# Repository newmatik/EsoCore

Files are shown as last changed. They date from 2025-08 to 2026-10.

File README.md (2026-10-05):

# EsoCore



EsoCore (Edge Sensor Observation, Control, Operations, Reliability Engine) is an open-source industrial IoT platform
for monitoring factory machinery and equipment. It spans the full stack from PCB hardware and embedded firmware to a
Django REST API backend and a Nuxt.js user portal.

## Repository Structure

```text
esocore/
  server/       Django REST API backend
  portal/       Nuxt.js user portal (dashboard, devices, alerts)
  website/      Public documentation site (static Nuxt.js, GitHub Pages)
  firmware/     Embedded C firmware for Edge (STM32H7) and sensors (STM32G0)
  hardware/     PCB designs (Altium), BOMs, Gerber, STEP, schematics
  tools/        Utility scripts (BOM sync, STEP linter)
  assets/       Shared icons and images
```

## Tech Stack

| Layer | Technology |
|---|---|
| Backend | Python 3.11+, Django 5, Django REST Framework, Poetry |
| Portal | TypeScript, Nuxt 4 (Vue 3), Nuxt UI, Tailwind CSS 4, Pinia |
| Website | TypeScript, Nuxt 4 (Vue 3), static generation, GitHub Pages |
| Firmware | C (C11), STM32H7 / STM32G0, ARM GCC, GNU Make |
| Hardware | Altium Designer, 4-layer FR4 PCBs |

## Prerequisites

- **Python 3.11+** and [Poetry](https://python-poetry.org/) for the server
- **Node 22.19+ (or 24.11+)** and [pnpm 9+](https://pnpm.io/) for the portal and website
- **ARM GCC** (`arm-none-eabi-gcc`) and **GNU Make** for the firmware

## Getting Started

### Server (Django REST API)

```bash
cd server
poetry install
poetry run python manage.py migrate
poetry run python manage.py createsuperuser
poetry run python manage.py runserver
```

The API is served at `http://localhost:8000/api/` with Swagger docs at `http://localhost:8000/api/docs/`.

See `server/README.md` for full setup, authentication, and deployment details.

### Portal (Nuxt.js)

```bash
cd portal
pnpm install
pnpm run dev
```

The portal runs at `http://localhost:3000`.

See `portal/README.md` for configuration and branding details.

### Website (Documentation)

```bash
cd website
pnpm install
pnpm run dev
```

To generate the static site for production:

```bash
pnpm run generate
```

See `website/README.md` for deployment instructions.

### Firmware

```bash
cd firmware
make all          # Build Edge + all sensors
make edge         # Build Edge only
make vibration    # Build a single sensor target
make help         # List all available targets
```

Requires the ARM GCC toolchain. See `firmware/README.md` for architecture and protocol details.

## Hardware

PCB designs, schematics, and BOMs are organized under `hardware/`:

- `hardware/edge/` -- Edge device (STM32H747, dual Ethernet, RS-485, WiFi, IEPE inputs, safety I/O)
- `hardware/sensors/` -- RS-485 sensor modules
  - vibration, acoustic, current, air quality, light, oil quality, pressure, temperature spot, proximity position
- `hardware/cables/` -- Cable assemblies

CAD files are in each device's `altium/` folder (open the `.PcbDoc` projects with Altium Designer).
See `hardware/README.md` and individual sensor READMEs for specifications.

### BOM Management

Canonical BOM CSVs live in each device folder under `hardware/`. The website reads CSVs from
`website/public/bom/` for public rendering. After editing any BOM in `hardware/`, run:

```bash
python3 tools/sync_bom_data.py
```

## Protocols

The Edge device supports industrial fieldbus protocols:

- Modbus RTU (RS-485, isolated) and Modbus TCP (Ethernet)
- PROFIBUS DP (DB-9, switchable termination)
- PROFINET Device (over Ethernet)

## Documentation

- [Hardware: Edge](website/content/esocore-edge.md) -- Core device specifications and connectivity
- [Hardware: Sensors](website/content/esocore-sensors.md) -- Sensor module catalog and applications
- [Installation Guide](website/content/getting-started/installation-guide.md) -- Full setup walkthrough
- Full docs are published at [www.esocore.com](https://www.esocore.com)

## Open Source

Source code: [github.com/newmatik/esocore](https://github.com/newmatik/esocore)

## Legal

Copyright 2026 Newmatik. All rights reserved.
Licensed under the Apache License, Version 2.0. See `website/content/license.md` for details.

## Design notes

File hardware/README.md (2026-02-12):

# EsoCore Hardware

## General Layout Requirements

- Prefer SMD components; avoid THT where feasible
- Provide Tag-Connect pads for MCU programming
- Include three fiducials on each SMD-assembled side
- Avoid single-sourcing; specify at least two MPNs where practical (exceptions: MCU or unique sensors)
- Evaluate cost-effective alternatives on LCSC, including reputable Chinese brands, not only established manufacturers

## Hardware sources

See READMEs in subfolders.

- `edge/`
- `sensors/`
  - `vibration sensor/`
  - `acoustic sensor/`
  - `current sensor/`
  - `air quality sensor/`
  - `light sensor/`
  - `oil quality sensor/`
  - `pressure sensor/`
  - `temperature spot sensor/`
  - `proximity position sensor/`
- `cables/`

Notes:

- BOMs live in the respective device folders.
- CAD/binaries belong under `altium/` and `mechanical/`.

## Copyright and License

Copyright © 2026 Newmatik. All rights reserved. Licensed under the Apache License, Version 2.0. See `website/content/license.md` for details.

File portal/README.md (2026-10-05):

# EsoCore Portal

Modern Vue.js frontend application for the EsoCore IoT monitoring system, built with Nuxt.js.

## Features

- **Dashboard**: Device monitoring overview with telemetry stats and recent alerts
- **Device Management**: Device listing with filtering, detail views with telemetry history
- **Asset Tracking**: Equipment grid with status filtering
- **Alert Management**: Alerts with severity filtering, acknowledgment, and resolution
- **Authentication**: Token-based authentication with cookie persistence
- **Dark Mode**: Forced dark theme with toggle support
- **Branding**: Configurable brand and product names via environment variables

## Technology Stack

- **Framework**: Nuxt 4 (Vue 3)
- **UI Library**: Nuxt UI (Tailwind CSS 4)
- **State Management**: Pinia
- **HTTP Client**: Nuxt `$fetch` (ofetch) with custom `useApi` composable
- **Authentication**: DRF Token authentication with cookie persistence
- **Icons**: Lucide (via Iconify)

## Quick Start

### Prerequisites

- Node.js 22.19+ (or 24.11+)
- pnpm 9+

### Installation

1. **Navigate to portal directory:**

   ```bash
   cd portal
   ```

2. **Install dependencies:**

   ```bash
   pnpm install
   ```

3. **Start development server:**

   ```bash
   pnpm run dev
   ```

The application will be available at `http://localhost:3000`

### Production Build

```bash
# Build for production
pnpm run build

# Preview production build
pnpm run preview

# Generate static site
pnpm run generate
```

## Configuration

### Environment Variables

Create a `.env` file in the portal directory:

```bash
# API Configuration
NUXT_PUBLIC_API_BASE_URL=http://localhost:8000/api
NUXT_PUBLIC_WS_BASE_URL=ws://localhost:8000/ws

# Authentication
NUXT_PUBLIC_AUTH_REDIRECT_URL=/dashboard

# App Configuration
NUXT_PUBLIC_APP_NAME=EsoCore
NUXT_PUBLIC_APP_VERSION=1.0.0

# Branding (optional)
# Set your brand and product names for UI titles and headers
# Example: Brand: Newmatik, Product: EsoCore => "EsoCore Portal"
NUXT_PUBLIC_BRAND=Newmatik
NUXT_PUBLIC_PRODUCT=EsoCore
```

### Branding

You can customize the displayed product name without code changes:

1. Set environment variables in your `.env` (or deployment env):

   ```bash
   NUXT_PUBLIC_BRAND=Newmatik
   NUXT_PUBLIC_PRODUCT=EsoCore
   ```

2. The UI will render headers and titles like: `EsoCore Portal`.

Defaults are defined in `app/config/branding.ts` and can be overridden at runtime via env vars.

## Project Structure

```text
portal/
├── app/
│   ├── app.vue                       # Root component
│   ├── assets/css/main.css           # Global CSS
│   ├── components/
│   │   └── ThemeToggle.vue           # Dark/light mode toggle
│   ├── composables/
│   │   ├── useApi.ts                 # API client ($fetch wrapper with auth)
│   │   └── useBranding.ts            # Brand/product name composable
│   ├── config/
│   │   └── branding.ts               # Branding defaults
│   ├── layouts/
│   │   ├── authenticated.vue         # Layout for authenticated pages
│   │   └── default.vue               # Default layout
│   ├── middleware/
│   │   └── auth.ts                   # Authentication route guard
│   ├── pages/
│   │   ├── index.vue                 # Landing page
│   │   ├── login.vue                 # Login page
│   │   ├── dashboard.vue             # Dashboard with stats and recent alerts
│   │   ├── alerts/index.vue          # Alert list with filtering and actions
│   │   ├── assets/index.vue          # Asset grid with status filtering
│   │   └── devices/
│   │       ├── index.vue             # Device list with site filtering
│   │       └── [id].vue              # Device detail with telemetry and events
│   ├── plugins/
│   │   ├── auth.client.ts            # Auth token restoration on startup
│   │   └── force-dark.client.ts      # Force dark mode on load
│   └── stores/
│       └── auth.ts                   # Auth state (token, user, login/logout)
├── public/                           # Static assets (icons, robots.txt)
├── app.config.ts                     # App-level configuration
├── eslint.config.js                  # ESLint configuration
├── nuxt.config.ts                    # Nuxt configuration
├── package.json                      # Dependencies and scripts
├── pnpm-lock.yaml                    # Lockfile
└── tsconfig.json                     # TypeScript configuration
```

## API Integration

The portal communicates with the Django REST backend through the `useApi` composable, which wraps
Nuxt's `$fetch` with automatic base URL resolution, auth token injection, and 401 redirect handling.

### Authentication

```typescript
const authStore = useAuthStore()
await authStore.login(email, password)

// Authenticated API calls
const api = useApi()
const devices = await api.get('/devices/devices/')
```

### API Endpoints Used

- **Auth**: `/auth/login/`, `/auth/logout/`, `/auth/me/`
- **Dashboard**: `/dashboard/summary/`
- **Devices**: `/devices/devices/`, `/devices/sites/`
- **Telemetry**: `/telemetry/points/`
- **Events**: `/events/events/`
- **Assets**: `/assets/assets/`

## Development

### Code Style

```bash
# Lint code
pnpm run lint

# Auto-fix lint issues
pnpm run lint:fix

# Format code
pnpm run format

# Check formatting
pnpm run format:check

# Type check
pnpm run typecheck
```

## Deployment

### Docker

```dockerfile
FROM node:22-alpine
WORKDIR /app
ENV NODE_ENV=production
# Use pnpm via Corepack (bundled with Node 22)
RUN corepack enable
COPY package.json pnpm-lock.yaml ./
RUN pnpm install --frozen-lockfile
COPY . .
RUN pnpm run build
EXPOSE 3000
CMD ["node", ".output/server/index.mjs"]
```

## Contributing

1. Follow Vue.js and Nuxt.js best practices
2. Use TypeScript for type safety
3. Follow the established component structure
4. Use meaningful commit messages

## License

Copyright 2026 Newmatik. All rights reserved.
Licensed under the Apache License, Version 2.0. See `website/content/license.md` for details.

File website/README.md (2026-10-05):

# EsoCore Website

This is the official website for EsoCore - an open-source industrial IoT platform for comprehensive monitoring of factory machinery and equipment.

The website is built with [Nuxt.js](https://nuxt.com) and deployed as a static site to GitHub Pages at [www.esocore.com](https://www.esocore.com).

## Features

- **Homepage**: Product overview with animated typewriter effect and hero image
- **Documentation**: Complete technical documentation with search and navigation
- **Static Generation**: Pre-rendered for optimal performance and SEO
- **BOM Integration**: Dynamic Bill of Materials widgets for hardware components
- **Responsive Design**: Works on desktop and mobile devices

## Development

### Prerequisites

- Node.js 22.19+ or 24.11+ (CI uses Node 22)
- pnpm 8 or later

### Setup

Install dependencies:

```bash
pnpm install
```

### Development Server

Start the development server on `http://localhost:3000`:

```bash
pnpm dev
```

### Building for Production

Generate the static site:

```bash
pnpm generate
```

The static files will be generated in `.output/public/` and can be deployed to any static hosting service.

### Preview Production Build

Preview the generated static site locally:

```bash
pnpm preview
```

## Project Structure

```text
website/
├── components/         # Vue components (header, footer, etc.)
├── composables/        # Vue composables (useDocs, etc.)
├── content/            # Markdown documentation files
├── layouts/            # Nuxt.js layouts
├── pages/              # Nuxt.js pages and routing
├── public/             # Static assets (images, CSS, BOM data)
│   ├── bom/            # Synced BOM CSV files
│   └── docs/           # Documentation assets
├── server/             # Server routes and plugins
│   ├── api/            # API routes for serving documentation
│   └── plugins/        # Server plugins (trailing-slash redirect)
├── utils/              # Utility modules (docs-config, etc.)
└── nuxt.config.ts      # Nuxt.js configuration
```

## Documentation

Documentation content is stored as Markdown files in the `content/` directory and served dynamically through API routes. The documentation includes:

- Hardware specifications
- API documentation
- Development guides
- Business information

## BOM Data Synchronization

BOM (Bill of Materials) data is synchronized from the hardware designs using the `sync_bom_data.py` script in the `tools/` directory:

```bash
# From the project root
python3 tools/sync_bom_data.py
```

This copies CSV files from `hardware/` to `website/public/bom/` for use in the documentation.

## Deployment

The website is automatically deployed to GitHub Pages via GitHub Actions when changes are pushed to the `main` branch. The workflow:

1. Sets up Node.js and pnpm
2. Installs dependencies
3. Generates the static site
4. Deploys to GitHub Pages

## Contributing

1. Make changes to the appropriate files
2. Test locally with `pnpm dev`
3. Generate and test the static build with `pnpm generate && pnpm preview`
4. Commit and push to trigger automatic deployment

For documentation updates, edit the Markdown files in `content/` and they will be automatically included in the next build.

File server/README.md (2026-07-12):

# EsoCore Server

Django REST Framework backend for the EsoCore IoT monitoring system.

**Status: In Development** -- Core REST API endpoints for device authentication, telemetry ingestion, and
configuration are implemented. MQTT real-time messaging and advanced analytics features are planned.

## Features

- **Device Management**: Register and manage IoT devices with API key authentication
- **Telemetry Ingestion**: High-performance time-series data collection
- **Asset Monitoring**: Track equipment cycles and maintenance schedules
- **Event Processing**: Real-time system events and alert management
- **User Management**: Role-based access control and customizable dashboards
- **RESTful API**: Complete REST API with OpenAPI/Swagger documentation

## Technology Stack

- **Framework**: Django 5.2 with Django REST Framework 3.16
- **Database**: SQLite (development) / PostgreSQL (production)
- **Authentication**: API Key authentication with session support
- **API Documentation**: DRF Spectacular (OpenAPI/Swagger)
- **Deployment**: Gunicorn / ASGI-compatible

## Quick Start

### Prerequisites

- Python 3.11+
- Poetry (recommended for Python dependencies)
- pnpm (for code quality scripts)

### Installation (Poetry)

1. **Navigate to server directory:**

   ```bash
   cd server
   ```

2. **Install dependencies with Poetry:**

   ```bash
   poetry install
   ```

3. **Activate the virtual environment (Poetry 2):**

   ```bash
   # Print the activation command, then evaluate it
   eval $(poetry env activate)
   # Or prefix all commands with: poetry run ...
   ```

4. **Run migrations:**

   ```bash
   poetry run python manage.py migrate
   ```

5. **Set up code quality tools (optional):**

   The project includes `package.json` with pnpm scripts for code quality tools. These are pre-configured and ready to use with the Poetry
   environment.

6. **Create superuser:**

   ```bash
   poetry run python manage.py createsuperuser
   ```

7. **Run development server:**

   ```bash
   poetry run python manage.py runserver
   ```

The API will be available at `http://localhost:8000/api/`

## API Endpoints

### Device-Facing Endpoints

- `POST /api/iot/v1/auth/handshake` - Authentication handshake
- `POST /api/iot/v1/telemetry/batch` - Telemetry data ingestion
- `GET /api/iot/v1/config` - Device configuration
- `GET /api/iot/v1/ota/check` - OTA update check
- `POST /api/iot/v1/ota/report` - OTA update status report

### Management Endpoints

- `/api/devices/devices/` - Device management
- `/api/devices/sites/` - Site management
- `/api/devices/firmware/` - Firmware bundle management
- `/api/assets/` - Asset management
- `/api/events/` - Event management
- `/api/telemetry/` - Telemetry data access
- `/api/users/` - User management
- `/api/auth/login/`, `/api/auth/logout/`, `/api/auth/me/` - User authentication
- `/api/dashboard/summary/` - Dashboard summary

## Authentication

### API Key Authentication (Devices)

Devices authenticate using API keys. Preferred header is `X-Auth-Key` (also accepts `X-API-Key` for compatibility):

```bash
curl -H "X-Device-Id: <uuid>" \
     -H "X-Auth-Key: <device-api-key>" \
     -H "Content-Type: application/json" \
     http://localhost:8000/api/iot/v1/telemetry/batch
```

### Session Authentication (Users)

Users authenticate via Django's session framework for web interface access.

## Configuration

### Environment Variables

The following environment variables can be set for production deployment. For local development the defaults
in `settings.py` are sufficient (SQLite, DEBUG=True).

> **Note:** The `.env` file is **not** auto-loaded by the Django settings. Set these as real environment
> variables, or add `python-dotenv` loading to `settings.py` if you prefer `.env` files.

```bash
DEBUG=True
SECRET_KEY=your-secret-key-here
ALLOWED_HOSTS=localhost,127.0.0.1
CORS_ALLOWED_ORIGINS=http://localhost:3000,http://127.0.0.1:3000
BRAND_NAME=Newmatik
PRODUCT_NAME=EsoCore
```

### Branding (Admin Title)

Admin branding is configured in `esocore_api/branding.py`.

Defaults:

```python
BRAND_NAME = "Newmatik"
PRODUCT_NAME = "EsoCore"
# Admin title becomes: "EsoCore Server"
```

Override via environment variables (no code change needed):

```bash
export BRAND_NAME="Acme"
export PRODUCT_NAME="Edge"
# Optional: override final admin title directly
export ADMIN_TITLE="Acme Edge Server"

poetry run python manage.py runserver
```

The title is used in Unfold's `SITE_TITLE` and the Django admin header/title.

### Database Configuration

For production, use PostgreSQL:

```python
DATABASES = {
    'default': {
        'ENGINE': 'django.db.backends.postgresql',
        'NAME': 'EsoCore',
        'USER': 'your_user',
        'PASSWORD': 'your_password',
        'HOST': 'localhost',
        'PORT': '5432',
    }
}
```

## Development

### Running Tests

```bash
poetry run python manage.py test
```

### Code Quality Tools

This project uses modern Python code quality tools:

- **Ruff**: Fast Python linter (replaces flake8)
- **Black**: Code formatter
- **isort**: Import organizer

#### Running Code Quality Checks

```bash
# Quick linting (recommended)
pnpm run lint

# Auto-format code
pnpm run format

# Individual tools
pnpm run ruff          # Lint with Ruff
pnpm run black         # Format with Black
pnpm run isort         # Organize imports
```

#### Check Only (No Auto-Fix)

```bash
# Check without fixing
pnpm run lint:check

# Individual checks
pnpm run ruff:check    # Check Ruff rules
pnpm run black:check   # Check Black formatting
pnpm run isort:check   # Check import organization
```

#### Auto-Fix Issues

```bash
# Fix all auto-fixable issues
pnpm run format:fix

# Individual fixes
pnpm run ruff:fix      # Fix Ruff issues
pnpm run black         # Format with Black
pnpm run isort         # Organize imports
```

### API Documentation

Access Swagger UI at: `http://localhost:8000/api/docs/`

## Deployment

### Production Settings

- Set `DEBUG=False`
- Use PostgreSQL database
- Configure proper CORS origins
- Set up proper logging
- Use environment variables for secrets

## Project Structure

```text
server/
├── esocore_api/          # Main Django project (active; used by manage.py, wsgi, asgi)
│   ├── settings.py
│   ├── urls.py
│   └── wsgi.py
├── devices/                   # Device management app (devices, sites, firmware)
├── iot/                       # IoT device-facing endpoints (auth, telemetry, config, OTA)
├── assets/                    # Asset management app
├── telemetry/                 # Telemetry data app
├── events/                    # Event processing app
├── users/                     # User management app
├── manage.py
├── pyproject.toml
├── poetry.lock (generated)
└── README.md
```

## Contributing

1. Follow Django coding standards
2. Write tests for new features
3. Update API documentation
4. Use meaningful commit messages

## License

Copyright © 2026 Newmatik. All rights reserved. Licensed under the Apache License, Version 2.0. See `website/content/license.md` for details.

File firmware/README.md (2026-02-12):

# EsoCore Firmware

## Industrial IoT Edge Computing Platform

**EsoCore** is a comprehensive firmware platform for industrial IoT applications, featuring real-time edge intelligence, robust communication
protocols, and enterprise-grade reliability.

## Architecture

```text
                          Data Acquisition
                   ┌──────────┬────────────────────┐
                   │          │                    │
              RS-485 Bus   4x Analog          6x Safety DI
              (Sensor       (Dual-mode          (Dual-channel
               Modules)      IEPE/DC)            optocoupled)
                   │          │                    │
                   └──────┬───┴────────────────────┘
                          │
                   EsoCore Edge Device (STM32H747)
                          │
          ┌───────────────┼───────────────┐
          │               │               │
     Dual Ethernet    WiFi/HTTP      Fieldbus
     Port A  Port B    API           RS-485
     (OT)   (IT)                     Modbus RTU
                                     PROFIBUS
     Internal Services:              Interbus
     ├── TinyML Engine
     ├── Safety I/O (6 dual-channel inputs + relay + SSR)
     ├── Power Management (24V DC + supercap)
     ├── Storage System (microSD)
     └── Configuration Management
```

### Data Acquisition Paths

EsoCore supports three complementary data acquisition methods:

- **RS-485 Sensor Bus**: Distributed sensor modules with local MCUs connect over an industrial RS-485 multi-drop bus. Each module performs its own
  conditioning and preprocessing. Supports auto-discovery and hot-plug. Best for: diverse sensor types, long cable runs (up to 100 m), scalable
  multi-sensor deployments.
- **Dual-Mode Analog Inputs (4 channels)**: On-board signal chain with per-channel mode selection via TMUX1101 analog switch. In IEPE mode:
  constant-current source enabled, AC-coupled for vibration accelerometers. In DC mode: current source off, direct bypass for 0-10 V, 4-20 mA,
  or other analog sensors. Both modes share 24-bit simultaneous ADC (ADS1274) at 50 kSPS, PGA (PGA280), and 15 kHz anti-aliasing filter. Best
  for: high-fidelity vibration monitoring or general-purpose analog sensing directly wired to the Edge device.
- **Safety Digital Inputs (6 channels)**: Dual-channel optocoupled 24V inputs with cross-monitoring (EN ISO 13849 Cat. 3). Each channel uses
  two independent optocouplers; firmware verifies agreement between both channels. Response time <10 ms. Best for: safety devices (e-stops,
  light curtains, safety edges, door sensors) as well as general machine state monitoring, production counting, and PLC integration.

## Key Features

- **Edge Intelligence**: TinyML with anomaly detection and predictive maintenance
- **Industrial Communication**: Dual Ethernet, RS-485, Modbus RTU/TCP, PROFINET, PROFIBUS, Interbus, WiFi, HTTP/HTTPS
- **Data Acquisition**: RS-485 sensor bus + 4 dual-mode analog inputs (IEPE/DC, 24-bit) + 6 safety digital inputs (dual-channel)
- **Safety I/O**: 6 dual-channel inputs (EN ISO 13849 Cat. 3) + safety relay (G7SA-2A2B-DC24) + SSR (AQY212EHAZ)
- **Power Resilience**: 24V DC with aggressive surge/ESD protection + supercapacitor backup
- **Enterprise Storage**: microSD with compression and power-safe writes
- **Remote Management**: OTA updates, configuration sync, health monitoring

## Quick Start

### Prerequisites

- ARM GCC toolchain (`arm-none-eabi-gcc`)
- GNU Make
- STM32H7 (Edge) and STM32G0 (Sensors) target support

### Build Commands

```bash
# Build everything (edge + all sensor modules)
make all

# Build specific components
make edge                   # Edge device
make vibration              # Vibration sensor
make acoustic               # Acoustic sensor
make current                # Current sensor
make air_quality            # Air quality sensor
make oil_quality            # Oil quality sensor
make pressure               # Pressure sensor
make temperature            # Temperature sensor
make proximity              # Proximity sensor
make light                  # Light sensor

# Flash devices
make flash_edge
make flash_vibration
make flash_acoustic
make flash_current
make flash_air_quality

# List all available targets
make help
```

> **Note:** The STM32G0 HAL, CMSIS, startup, and linker files (`stm32/stm32g0/`) are not yet included in
> the repository. Sensor module builds will fail until this directory structure is added. See the Makefile
> for the expected layout.

## Project Structure

```text
firmware/
├── common/                # Shared components
│   ├── communication/     # WiFi, HTTP, RS-485, Modbus
│   ├── storage/           # Sensor interface, microSD
│   ├── safety/            # EN ISO 13849 safety I/O (dual-channel inputs + relay outputs)
│   ├── management/        # Power, configuration management
│   ├── intelligence/      # Event system, TinyML
│   └── ui/                # OLED display
├── stm32/
│   ├── edge/              # Edge device firmware
│   └── sensors/           # Sensor module firmware
├── build/                 # Generated build artifacts
├── release/               # Release packages
└── Makefile               # Build system
```

## RS-485 Sensor Bus Modules

External sensor modules connect via the RS-485 multi-drop bus. Each module has its own MCU and performs local conditioning:

| Sensor Type | Key Capabilities | Use Cases |
| --- | --- | --- |
| **Vibration** | 3-axis FFT, bearing fault detection | Predictive maintenance |
| **Acoustic** | SPL measurement, ultrasound detection | Noise monitoring, leak detection |
| **Current** | Harmonic analysis, motor load detection | Power quality, motor monitoring  |
| **Air Quality** | IAQ calculation, health risk assessment | Environmental monitoring |
| **Oil Quality** | Turbidity, viscosity, water content | Lubrication monitoring |
| **Pressure** | Multi-range sensing, hydraulic monitoring | Process control |
| **Temperature** | NTC/RTD/Thermocouple, high precision | Thermal management |
| **Proximity** | Inductive/capacitive/laser sensing | Position detection |
| **Light** | Ambient/UV/IR sensing, lux measurement | Light level monitoring |

## On-Board Inputs

In addition to the sensor bus, the Edge device has direct on-board inputs:

| Input Type | Channels | Specification | Use Cases |
| --- | --- | --- | --- |
| **Analog (IEPE/DC)** | 4 | 24-bit ADC, 50 kSPS, PGA, 15 kHz AAF, TMUX1101 | IEPE accelerometers, 0-10V, 4-20mA sensors |
| **Safety Digital** | 6 | Dual-channel optocoupled, 24V, EN ISO 13849 Cat. 3 | E-stops, safety edges, light curtains, machine states |

## Configuration

### Edge Device

```c
#define WIFI_SSID           "EsoCore_Network"
#define SERVER_URL          "https://api.esocore.com"
#define HEARTBEAT_INTERVAL_MS    30000
#define OTA_CHECK_INTERVAL_MS    3600000
```

### Sensor Modules

```c
#define SENSOR_DEVICE_ADDRESS   0x02
#define SENSOR_DEVICE_TYPE      ESOCORE_DEVICE_TYPE_VIBRATION
#define DATA_TRANSMIT_INTERVAL_MS 2000
```

## System Monitoring

### Health Monitoring

```c
esocore_config_status_t status;
esocore_config_get_status(&status);
uint8_t health = status.system_health; // 0-100
```

### Event Logging

```c
esocore_event_log(ESOCORE_EVENT_SENSOR_DATA_READY,
                 ESOCORE_EVENT_SEVERITY_INFO,
                 (uint8_t *)"Data processed", 0);
```

### Performance Metrics

- CPU usage monitoring
- Memory utilization tracking
- Network latency measurement
- Sensor data throughput
- Storage compression ratios
- Power consumption monitoring

## API Reference

### Server Endpoints (IoT API)

The Edge device communicates with the EsoCore server at `/api/iot/v1/`:

- `POST /api/iot/v1/auth/handshake` - Device authentication via API key
- `POST /api/iot/v1/telemetry/batch` - Submit telemetry data batches
- `GET  /api/iot/v1/config` - Fetch device configuration
- `GET  /api/iot/v1/ota/check` - Check for firmware updates
- `POST /api/iot/v1/ota/report` - Report OTA update result

### RS-485 Sensor Bus Protocol

- `DISCOVER` - Device discovery
- `HEARTBEAT` - Connection monitoring
- `DATA_REQUEST/RESPONSE` - Sensor data exchange
- `CONFIG_UPDATE` - Configuration updates

## Hardware Abstraction Layer (HAL) Status

The firmware uses a layered architecture where higher-level modules call into HAL functions that
interface with hardware peripherals. HAL functions are implemented as stubs (returning `true` or
`false` without real hardware interaction) until the corresponding hardware driver is integrated.
This is a standard pattern for embedded projects under active development.

Stub functions are marked with `/* TODO: ... */` comments. Current module completion status:

| Module | Implemented | Stubs | Complete |
| --- | --- | ----- | --- |
| `common/communication/ethernet_manager.c` | 9 | 0 | 100% |
| `common/safety/safety_io.c` | 25 | 3 | 89% |
| `common/ui/oled_display.c` | 42 | 8 | 84% |
| `common/storage/storage_system.c` | 18 | 12 | 60% |
| `common/intelligence/tinyml_engine.c` | 20 | 15 | 57% |
| `common/sensors/sensor_interface.c` | 20 | 15 | 57% |
| `common/communication/wifi_manager.c` | 12 | 13 | 48% |

To find all HAL stubs, search for `TODO` comments in the `common/` directory.

## License

Apache License 2.0

## Support

- Issues: [GitHub Issues](https://github.com/newmatik/esocore/issues)
- Docs: [esocore.com](https://www.esocore.com)

---

**EsoCore** - Industrial IoT with Edge Intelligence

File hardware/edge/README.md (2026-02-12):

# EsoCore Edge

## PCB Specification

- Board: 4-layer FR4 1.55 mm +/-10%
- Dimensions: 86 × 171 mm (H × W) – sized for custom DIN Rail housing
- Surface finish: ENIG
- Copper: 35 µm (1 OZ) outer/inner
- Black soldermask / white silkscreen

## Hardware

- MCU: STM32H747IIT6 (LQFP176) dual-core M7/M4, 25 MHz active oscillator (shared with Ethernet PHY), 32.768 kHz RTC
- MCU support: 1.2 V LDO (TLV70212DBVR) for internal regulator bypass; ferrite bead (BLM18PG121SN1D) on VDD rail
- Storage: microSD socket (push-push) with EMIF06-MSD02N16 EMI filter on SDIO lines, industrial microSD card
- Power: Dedicated 24 V DC input -> 5 V buck (TPS54331, 3 A) -> 3.3 V digital LDO + 3.3 V low-noise analog LDO (TPS7A4533)
- Backup: 3.8 V 20 F supercap (SLA3R8L2060813) with 680 ohm charge current limiting and Schottky diode (CDBA240LL-HF)
  charge path control for safe shutdown; evaluate adding second unit if 30 s runtime target requires more capacity
- Protection: TVS diodes + varistors on 24 V input; input LC filter (47 uH + 470 uF); ESD arrays on USB/GPIO/sensor bus
- Interfaces:
  - USB-C device/service with common-mode choke (DLW21SN900SQ2L) and ESD protection (USBULC6-2M6); firmware flashing
    and terminal communication only; not used for normal operation or data collection
  - Dual Ethernet 10/100 (2x KSZ8081RNACA) with integrated magnetics (2x Wurth 7499111121) and ferrite beads
    (FCM1608KF-601T03) per PHY; Port A (Machine), Port B (IT)
  - RS-485 sensor bus (SN65HVD72), termination selectable
  - Fieldbus: Isolated Modbus RTU, PROFIBUS-compatible RS-485 (DB-9), dedicated Interbus RS-485
- I/O connectors:
  - Pluggable terminal blocks (Degson): plugs `2EDGK-5.0-xxP` mating with PCB connectors `2EDGR-5.0-xxP`; all PCB mates are 90° angled at PCB edge for
    enclosure access
  - 2x 4-pin sensor bus: plug `2EDGK-5.0-04P` / PCB mate `2EDGR-5.0-04P`
  - Safety digital inputs: 14-pin `2EDGK-5.0-14P` / `2EDGR-5.0-14P` (6 dual-channel safety inputs, 12 optocouplers)
  - Safety relay output: 6-pin `2EDGK-5.0-06P` / `2EDGR-5.0-06P`
  - Analog inputs: 10-pin `2EDGK-5.0-10P` / `2EDGR-5.0-10P` (4 dual-mode IEPE/DC channels)
  - Fieldbus: 6-pin `2EDGK-5.0-06P` / `2EDGR-5.0-06P`; PROFIBUS: DB-9
  - Interbus: 4-pin `2EDGK-5.0-04P` / `2EDGR-5.0-04P`
  - Power input: 2-pin `2EDGK-5.0-02P` / `2EDGR-5.0-02P`
- Programming/debug:
  - STM32 SWD: Tag-Connect TC2050-IDC-NL (10-pin needle footprint)
  - ESP32 UART: Tag-Connect TC2030-IDC-NL (6-pin needle footprint)
- WiFi/BT: ESP32-S3-WROOM-1-N16R8 with USB VBUS LDO (AMS1117-3.3) and auto-programming circuit (UMH3N)
- Safety I/O: 6 dual-channel safety inputs (12x PC817X2NIP1B optocouplers, EN ISO 13849 Cat. 3) + safety relay
  (1x G7SA-2A2B-DC24, 2NO+2NC) with DRV110APWR coil driver for PLd interlocking
- UI: 1.5" 128x64 OLED (I2C) with BSS138LT1G level shifter, Reset/Boot/Menu buttons, status LEDs
- Analog: 4-ch IEPE signal chain (ADS1274 ADC, PGA280, OPA4188, REF200AU current sources)

## Mechanical Constraints

- **PCB dimensions**: 86 mm (H) × 171 mm (W) to fit in custom DIN Rail housing
- **Housing**: 90 mm height × 175 mm width (10 × 17.5 mm for DIN rail mounting)
- **Clearance**: 2 mm on all sides between PCB edge and housing walls
- **Dimension logic**:
  - Height: 90 mm housing − 2 mm (top) − 2 mm (bottom) = **86 mm PCB**
  - Width: Housing must be multiple of 17.5 mm; 10 × 17.5 = 175 mm housing − 2 mm (left) − 2 mm (right) = **171 mm PCB**
- **Note**: Height is fixed at 86 mm; width can be adjusted in 17.5 mm increments (with corresponding 4 mm reduction for PCB)
- **Edge access**:
  - **Top edge**: All pluggable terminal blocks (green Degson connectors)
  - **Bottom edge**: USB-C, 2x Ethernet RJ45, DB-9 (PROFIBUS)
  - **Left and right edges**: Keep clear (no connectors or tall components)

## General Layout Requirements

- Black solder mask with white silk screen
- Silk screen for important components with information value only (such as connectors)
- Prefer SMD components; avoid THT where feasible
- Single-sided assembly: place all SMD and THT on one side only (no backside assembly)
- Prefer increasing PCB width (if needed) over double-sided assembly to reduce cost and simplify enclosure
- Provide Tag-Connect pads: TC2050 footprint for STM32 SWD and TC2030 footprint for ESP32 UART
- Include three fiducials on the assembled side
- Avoid single-sourcing; specify at least two MPNs where practical (exceptions: MCU or unique sensors)
- Evaluate cost-effective alternatives on LCSC, including reputable Chinese brands, not only established manufacturers

## Layout Guidance

### Component Placement

- **Display and UI**: Place 1.5" OLED display and buttons (Reset/Boot/Menu) on front face for easy access
- **Buttons**: Position Reset/Boot/Menu buttons directly below the display with sufficient spacing for easy operation; ensure no obstructions above
  button areas
- **Connectors**:
  - Group all pluggable terminal blocks (Degson green connectors) along the top edge
  - Place USB-C, Ethernet RJ45, and DB-9 along the bottom edge
  - Keep left and right edges completely clear
- **Tall components**: Keep away from left and right edges to maintain housing clearance

### Electrical Layout

- Separate power, digital, and analog zones; star ground tie at ADC/MCU ref
- Keep RS‑485, Ethernet, and USB return paths tight; add stitching vias near chokes
- Place TVS/ESD close to connectors; keep supercap high-current paths short
- Respect creepage/clearance around isolated fieldbus and Interbus sections

## CAD Toolchain

- Tool: Altium Designer
- Project: `hardware/edge/Altium/PCB/EsoCore_Edge.PcbDoc`
- Schematics: `hardware/edge/Altium/Schematics/*.SchDoc` (14 sheets)
- Footprint library: `hardware/edge/Altium/Footprint library/EsoCore.PcbLib`
- Notes: Open the `.PcbDoc` in Altium Designer; edit schematics/layout in `.SchDoc`/`.PcbDoc`. Generate fabrication
  outputs via Altium Designer.

## Copyright and License

Copyright © 2026 Newmatik. All rights reserved. Licensed under the Apache License, Version 2.0. See `website/content/license.md` for details.

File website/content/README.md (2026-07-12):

# EsoCore: Universal Industrial Machine Monitoring System

EsoCore is an advanced industrial IoT platform for comprehensive monitoring of factory machinery and equipment. By capturing critical operational
data—from thermal conditions to mechanical health indicators—this system enables predictive maintenance, reduces downtime, and optimizes equipment
performance across manufacturing facilities.

EsoCore is an acronym: Edge Sensor Observation, Control, Operations, Reliability Engine. The name also recognizes our heritage—Newmatik began as ESO
Electronic Service Ottenbreit GmbH in 1990—carrying that tradition forward as we build everything new and automatic today.

---

## Introduction

### The Problem

Unplanned equipment failures cost manufacturers millions in lost production, emergency repairs, and quality issues. Traditional reactive maintenance
leads to premature replacements, unexpected downtime, and safety hazards. This is especially critical for high-volume production, precision
manufacturing, and safety-critical operations where equipment reliability is paramount.

### The Solution

A robust edge-to-cloud telemetry platform that continuously monitors machine health through multiple sensor streams, providing early warning of issues
and actionable insights for maintenance teams. The system is designed to work with virtually all industrial machinery types and integrates with
existing factory systems, making it universally deployable across diverse manufacturing environments.

### Development Model

EsoCore is developed and maintained by Newmatik through a collaborative partnership model with strategic industrial partners. The entire
platform—including hardware designs, firmware, and cloud components—is fully open source under the Apache 2.0 License,
ensuring maximum flexibility and preventing vendor lock-in. Partners can develop proprietary market-specific
customizations while benefiting from shared platform development costs and continuous innovation. This unique approach
combines open-source principles with commercial viability, creating a sustainable ecosystem where partners retain full
independence and can fork the project if needed.

### Competitive Position

EsoCore differentiates itself in the industrial IoT market through cross-domain capability (supporting both industrial doors and CNC machines in one
platform), edge-first TinyML architecture for ultra-low latency anomaly detection, and comprehensive safety integration. While competitors often focus
on single verticals with proprietary platforms, EsoCore's open-source foundation and unified approach provides unique value for facilities managing
diverse industrial assets.

### Key Benefits

- **Predictive Maintenance**: Detect issues before failure occurs using AI-powered edge intelligence
- **Edge Intelligence**: On-device anomaly detection with TinyML for faster response
- **Operational Insights**: Track usage patterns and energy efficiency with algorithmic analysis
- **Fleet Management**: Monitor multiple machines from a centralized dashboard with ML-driven analytics
- **Cost Reduction**: Optimize maintenance schedules and extend equipment life through intelligent predictions
- **Compliance**: Maintain audit trails for safety and regulatory requirements
- **Universal Compatibility**: Works with virtually all industrial machinery and manufacturing equipment
- **Complete Data Visibility**: Comprehensive monitoring for mission-critical production environments

---

## Target Applications

**Machining & Metal Working:**

- CNC milling machines, lathes, turning centers
- Stamping presses, punching machines, press brakes
- Grinding machines, surface finishing equipment
- Welding stations, cutting systems (plasma, laser, waterjet)

**Process Manufacturing:**

- Injection molding machines, extrusion equipment
- Packaging lines, filling and sealing machines
- Chemical reactors, mixing equipment
- Food processing machinery, bottling lines

**Material Handling & Automation:**

- Conveyor systems, robotic arms, pick-and-place units
- Automated guided vehicles (AGVs), shuttle systems
- Assembly line automation, testing equipment
- Warehouse automation (AS/RS, sorters)
- Sectional doors, overhead doors, door drives

**Support Infrastructure:**

- Industrial pumps, compressors, blowers
- Motors, gearboxes, belt drives, couplings
- HVAC systems, cooling towers, chillers
- Hydraulic and pneumatic systems

**Specialized Equipment:**

- Textile machinery (looms, knitting machines)
- Paper processing equipment (pulping, coating)
- Mining equipment (crushers, mills, separators)
- Energy equipment (turbines, generators)

For these demanding applications, EsoCore provides the complete operational visibility and zero-downtime reliability that traditional reactive
maintenance cannot deliver.

---

## Project goals

- **Capture**:
  - Comprehensive air quality monitoring (temperature, humidity, CO₂, VOCs, particulate matter)
  - Equipment environmental monitoring for thermal management and air quality
  - Light intensity monitoring (visible, UV, IR, color, spectral) for workplace safety and process control
  - Oil quality monitoring (viscosity, contamination, water content) for predictive lubrication maintenance
  - Pressure monitoring for hydraulic/pneumatic systems (leak detection, performance validation)
  - Targeted temperature monitoring (bearings, gearboxes, extreme environments)
  - Position sensing and cycle counting (automation, robotics, machine validation)
  - Operational cycles (machine starts/stops, production counts)
  - Multi-axis vibration (RMS and diagnostic windows) for bearing/mechanical health
  - Motor current and power consumption for load monitoring
  - Acoustics (audible + ultrasound monitoring) for tool wear, quality, and fault detection
  - Process parameters (pressure, flow, speed) via analog/digital interfaces
- **Local durability**: store on SD in a standardized, append-only, audit-friendly format with integrity checks.
- **Reliable sync**: upload to a cloud IoT platform via REST with strong auth, resumable uploads, and conflict-free idempotency.
- **Mixed connectivity**: Wi-Fi or dual Ethernet, with automatic backfill after outages.
- **Fleet-grade ops**: secure provisioning, OTA firmware, device health, alerts, dashboards, and role-based access.

---

## System Architecture

### High-Level Components

| Component | Technology | Purpose |
| --- | --- | --- |
| **Edge** | STM32H747 (dual-core M7/M4) | Real-time sensor data collection and local processing |
| **Cloud Platform** | Django REST Framework Server + Nuxt.js Portal | Data management, analytics, and user interfaces |
| **Connectivity** | Dual Ethernet or Wi-Fi | Reliable data transmission with offline resilience |
| **Storage** | Industrial microSD + Cloud DB | Local buffering and long-term data persistence |

### Technology Choices Rationale

- **STM32 MCU**: Proven ecosystem with robust peripherals, extensive RTOS support, and hardware crypto acceleration
- **Django REST Framework Server + Nuxt.js Portal**: Scalable backend with REST APIs, role-based access control, and modern responsive frontend with
  real-time dashboards
- **Industrial microSD**: Provides local resilience for 30+ days of offline operation
- **TLS over REST**: Simple, firewall-friendly protocol with strong security

### Data Acquisition Architecture

EsoCore supports three complementary data acquisition methods:

- **RS-485 Sensor Bus**: Distributed sensor modules with local MCUs connect over an industrial RS-485 multi-drop bus, enabling plug-and-play
  expansion. New sensor types can be added without changing the Edge or platform architecture. Digital, noise-immune wiring up to 100 m with
  auto-discovery and hot-plug support.
- **On-Board IEPE Analog Inputs (4 channels)**: Dedicated signal chain for IEPE/ICP vibration accelerometers wired directly to the Edge device.
  24-bit simultaneous ADC at 50 kSPS per channel with programmable gain and anti-aliasing filter.
- **On-Board Safety Digital Inputs (6 channels)**: Dual-channel optocoupled 24 V inputs (EN ISO 13849 Cat. 3) with cross-monitoring for safety
  devices (e-stops, light curtains, safety edges) and general-purpose signals (cycle counts, machine states).

See detailed specs in [Hardware: Edge](/docs/esocore-edge).

---

## Hardware Overview

### Edge Platform

- **Microcontroller**: STM32H747 dual core (Cortex-M7/M4) with hardware crypto, sufficient for TLS and edge AI processing.
- **Connectivity**: Dual industrial Ethernet with physical network separation (preferred) or robust Wi-Fi module for reliable data transmission.
- **Storage**: Industrial-grade microSD with wear leveling for 30+ days of local data buffering.
- **Primary Power**: Dedicated 24 V DC with aggressive surge/ESD protection, input filtering, and brownout-safe behavior.
- **Backup System**: Supercapacitor bank (20 F, with optional second unit for ≥30 s runtime) providing ≥30 seconds for
  safe shutdown during power outages.
- **Environmental**: IP54-IP65 enclosure, -20°C to +60°C operation, industrial EMC compliance.

Detailed Specifications: See [Hardware: Edge](/docs/esocore-edge) for complete component specifications, compliance standards, and reference designs.

### Sensor Suite

- **Environmental**: Comprehensive air quality monitoring (temperature, humidity, CO₂, VOCs, particulate matter) + light intensity monitoring
  (visible, UV, IR, color, spectral) + oil quality monitoring (viscosity, contamination, water content) for thermal management and environmental
  compliance.
- **Mechanical**: 3-axis vibration (1-3kHz), acoustic monitoring (audible + ultrasonic), multi-range pressure sensors (hydraulic/pneumatic),
  proximity/position sensors (automation, cycle counting), motor current sensing for torque/load monitoring.
- **Thermal**: Targeted temperature monitoring with NTC thermistors, RTD sensors, thermocouples, and IR sensors for bearings, gearboxes, and extreme
  environments.
  Detailed Specifications: See [Hardware: Sensors](/docs/esocore-sensors) for complete component specifications, compliance standards, and reference
  designs.

---

## Firmware

The firmware is written in C (C11) and targets two STM32 families: STM32H7 for the Edge device and STM32G0 for sensor
modules. It is built with ARM GCC and GNU Make.

Key firmware responsibilities include sensor sampling, safety I/O monitoring, local data storage (JSON with zstd
compression on microSD), on-device TinyML inference for anomaly detection, cloud synchronization over REST, and OTA
firmware updates.

See [Firmware](/docs/firmware-overview) for the complete architecture, code structure, build system, and toolchain setup
instructions.

---

## Cloud Platform

The cloud platform consists of two applications:

- **[Backend Server](/docs/backend-server)**: A Django REST Framework application (Python) that handles device
  registration, telemetry ingestion, event processing, alerting, and exposes REST APIs. Supports PostgreSQL in
  production with auto-generated OpenAPI documentation.
- **[Portal](/docs/portal)**: A Nuxt 4 web application (Vue.js / TypeScript) providing real-time dashboards, device
  management, fleet monitoring, and alerting interfaces. Built with Nuxt UI and Tailwind CSS.

The server authenticates devices via API keys and users via session-based auth. The portal communicates with the server
over REST APIs.

See also: [API Specification](/docs/api-specification) and
[Cloud Infrastructure](/docs/cloud-infrastructure) for deployment details.

---

## Security & Device Management

- **Secure Provisioning**: Manufacturing-injected device credentials with QR-code claiming process for field deployment.
- **Enterprise Security**: TLS encryption, signed OTA updates, device authentication, and automatic rollback protection.
- **Fleet Management**: Centralized device configuration, firmware updates, and security key rotation.

---

## Testing & Validation

### Quality Assurance Framework

- **Comprehensive Testing**: Multi-layered validation including unit tests, hardware-in-loop testing, safety compliance verification, and end-to-end
  system validation.

### Performance Benchmarks

- 72-hour offline tolerance with full data recovery
- 99.5%+ OTA success rate
- <0.01% data loss rate over 30-day soak tests

### Compliance

- EMC testing (EN 61000), functional safety (EN ISO 13849), electrical safety (EN 60204-1), and environmental qualification testing.

Detailed Procedures: See [Testing Procedures](/docs/testing-procedures) for complete test protocols, acceptance criteria, and validation procedures.

---

## Deployment & Operations

- **Environment Strategy**: Progressive deployment through dev → staging → production with separate databases and security keys.
- **Observability**: Comprehensive monitoring with Sentry error tracking, Prometheus metrics, and automated uptime checks.
- **Fleet Operations**: Staged OTA rollouts (5%/25%/100%) with canary devices, automated backups, and compliance-ready data retention policies.

---

## Technology Decisions

- **Data Format**: JSON with zstd compression for maintainability and debugging ease.
- **Connectivity**: Dual Ethernet preferred for industrial environments; Wi-Fi for retrofits.
- **Protocols**: REST for all device communications; MQTT optional for real-time commands.
- **Database**: Django with PostgreSQL and optional TimescaleDB for heavy analytics workloads.

---

## Technical Documentation

This page provides the business case and system overview. The documentation is organized into the following sections,
accessible from the sidebar:

### Hardware

- **[Edge Hardware](/docs/esocore-edge)** -- Edge device specifications, dual Ethernet, analog inputs, fieldbus
  protocols
- **[Sensors](/docs/esocore-sensors)** -- Complete sensor module catalog with individual datasheets

### Software

- **[Firmware](/docs/firmware-overview)** -- C11 firmware architecture, toolchain, build system, and setup guide
- **[Edge Intelligence](/docs/edge-intelligence)** -- TinyML models, anomaly detection, and training pipelines
- **[Data Format Specification](/docs/data-format-specification)** -- JSON schemas, event types, and storage format

### Cloud Platform

- **[Backend Server](/docs/backend-server)** -- Django REST API: architecture, endpoints, and local setup
- **[Portal](/docs/portal)** -- Nuxt 4 frontend: dashboards, device management, and local setup
- **[API Specification](/docs/api-specification)** -- Detailed REST API documentation and data models
- **[Cloud Infrastructure](/docs/cloud-infrastructure)** -- Deployment architecture and hosting options

### Development and Operations

- **[Development Environment](/docs/development-environment)** -- Toolchain setup across all disciplines
- **[Testing Procedures](/docs/testing-procedures)** -- Test protocols, validation procedures, and acceptance criteria

### Business

- **[Business Model & Partnerships](/docs/business-model-and-partnerships)** -- Partnership framework and open source
  philosophy
- **[Competitor Analysis](/docs/competitor-analysis)** -- Market landscape and competitive positioning

---

## License

EsoCore is licensed under the **Apache License 2.0**. This means you can:

- Use commercially and modify the code
- Distribute and sell products based on EsoCore
- Fork the project and continue independently
- Integrate into proprietary software/hardware

See the [License](/docs/license) page for complete terms and a detailed summary of what you can and cannot do.

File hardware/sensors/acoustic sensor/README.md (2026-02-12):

# EsoCore Acoustic Sensor

## PCB Specification

- Board: 2-layer FR4 1.55 mm +/-10%
- Dimensions: Approx. 40 × 30 mm
- Surface finish: ENIG
- Copper: 35 µm (1 OZ)
- Black soldermash / white silkscreen

## Hardware

- MCU: STM32G031K8T6 (TSSOP20), 8 MHz crystal
- Sensor: Digital MEMS microphone ICS-43434 (wide-band 50Hz-20kHz ±3dB)
- Sensor: Ultrasound transducer MA40S4R (40±1kHz frequency response)
- Bus: RS‑485 half‑duplex (SN65HVD72), bias/termination network
- Power: 12 V bus → 3.3 V buck (TPS62172) + LDO (MCP1700) for clean analog
- Connectors: Two pluggable RS‑485 ports (IN and OUT): plug `2EDGK-5.0-04P` ↔ PCB mate `2EDGR-5.0-04P`; silk labels A/B/12V/GND; signal loop‑through;
  PG9 cable gland
- Addressing: 8‑position SMD DIP; 1–7 = Modbus address bits, 8 = 120 Ω termination enable; silkscreen: "1‑7=ADDR, 8=TERM, ON/OFF"
- Indicators: Green status LED
- Programming: Tag‑Connect SWD footprint

## General Layout Requirements

- Black solder mask with white silk screen
- Silk screen for important components with information value only (such as connectors)
- Prefer SMD components; avoid THT where feasible
- Single-sided assembly: place all SMD and THT on one side only (no backside assembly)
- Prefer increasing PCB size over double-sided assembly to reduce cost and simplify enclosure
- Provide Tag-Connect pads for MCU programming
- Include three fiducials on the assembled side
- Avoid single-sourcing; specify at least two MPNs where practical (exceptions: MCU or unique sensors)
- Evaluate cost-effective alternatives on LCSC, including reputable Chinese brands, not only established manufacturers

## Layout Guidance

- Keep microphone port unobstructed; consider acoustic opening and gasket
- Separate analog and digital grounds; single-point tie
- Place ESD near connector; route RS‑485 differential pair
- Provide mechanical support for enclosure mounting; consider magnetic base interface
- Allow space for both audible and ultrasonic frequency sensors

## CAD Toolchain

- Tool: Altium Designer
- Projects: live under the `altium/` subfolder of this device
- Main project: `acoustic-sensor.PcbDoc`
- Notes: Open the `.PcbDoc` in Altium Designer; generate fabrication outputs via Altium Designer.

## Copyright and License

Copyright © 2026 Newmatik. All rights reserved. Licensed under the Apache License, Version 2.0. See `website/content/license.md` for details.

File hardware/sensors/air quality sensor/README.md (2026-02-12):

# EsoCore Air Quality Sensor

## PCB Specification

- Board: 4-layer FR4 1.55 mm +/-10%
- Dimensions: Approx. 60 × 40 mm
- Surface finish: ENIG
- Copper: 35 µm (1 OZ)
- Black soldermash / white silkscreen

## Hardware

- MCU: STM32G031K8T6 (TSSOP20), 8 MHz crystal
- Environmental Sensor: BME680 (temperature, humidity, pressure, VOC, IAQ index)
- Particulate Matter Sensor: PMS5003 (PM2.5, PM10, particle count)
- CO2 Sensor: SCD40 (NDIR CO2 with auto-calibration)
- Bus: RS‑485 half‑duplex (SN65HVD72), bias/termination network
- Power: 12 V bus → 5 V buck (TPS62173) + 3.3 V LDO (MCP1700)
- Connectors: Two pluggable RS‑485 ports (IN and OUT): plug `2EDGK-5.0-04P` ↔ PCB mate `2EDGR-5.0-04P`; silk labels A/B/12V/GND; signal loop‑through
- Protection: ESD array on bus and power lines
- Addressing: 8‑position SMD DIP; 1–7 = Modbus address bits, 8 = 120 Ω termination enable; silkscreen: "1‑7=ADDR, 8=TERM, ON/OFF"
- Indicators: Green status LED
- Programming: Tag‑Connect SWD footprint

## General Layout Requirements

- Black solder mask with white silk screen
- Silk screen for important components with information value only (such as connectors)
- Prefer SMD components; avoid THT where feasible
- Single-sided assembly: place all SMD and THT on one side only (no backside assembly)
- Prefer increasing PCB size over double-sided assembly to reduce cost and simplify enclosure
- Provide Tag-Connect pads for MCU programming
- Include three fiducials on the assembled side
- Avoid single-sourcing; specify at least two MPNs where practical (exceptions: MCU or unique sensors)
- Evaluate cost-effective alternatives on LCSC, including reputable Chinese brands, not only established manufacturers

## Layout Guidance

- Place air intake ports for particulate sensor and environmental sensors
- Separate analog and digital grounds; single-point tie
- Provide proper air flow for accurate readings
- Include mesh filter protection for particulate sensor
- Allow space for multiple sensor components

## CAD Toolchain

- Tool: Altium Designer
- Projects: live under the `altium/` subfolder of this device
- Main project: `air-quality-sensor.PcbDoc`
- Notes: Open the `.PcbDoc` in Altium Designer; generate fabrication outputs via Altium Designer.

## Copyright and License

Copyright © 2026 Newmatik. All rights reserved. Licensed under the Apache License, Version 2.0. See `website/content/license.md` for details.

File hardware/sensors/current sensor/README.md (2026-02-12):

# EsoCore Current Sensor

## PCB Specification

- Board: 2-layer FR4 1.55 mm +/-10%
- Dimensions: Approx. 50 × 35 mm (DIN rail enclosure)
- Surface finish: ENIG
- Copper: 35 µm (1 OZ)
- Black soldermash / white silkscreen

## Hardware

- MCU: STM32G031K8T6 (TSSOP20), 8 MHz crystal
- Sensor: ACS723 ±30 A Hall current sensor (higher range, better linearity)
- Isolation: RS‑485 transceiver ADM2582E (integrated iso + DC/DC)
- Power: Isolated 12V→5V DC/DC (NXE1S1205MC) → 3.3 V LDO (MCP1700)
- Connectors: Two pluggable RS‑485 ports (IN and OUT): plug `2EDGK-5.0-04P` ↔ PCB mate `2EDGR-5.0-04P`; silk labels A/B/12V/GND; signal loop‑through;
  PG9 cable gland
- Protection: GDT surge suppressor on power; ESD arrays at bus/power
- Addressing: 8‑position SMD DIP; 1–7 = Modbus address bits, 8 = 120 Ω termination enable; silkscreen: "1‑7=ADDR, 8=TERM, ON/OFF"
- Indicators: Green status LED
- Programming: Tag‑Connect SWD footprint

## General Layout Requirements

- Black solder mask with white silk screen
- Silk screen for important components with information value only (such as connectors)
- Prefer SMD components; avoid THT where feasible
- Single-sided assembly: place all SMD and THT on one side only (no backside assembly)
- Prefer increasing PCB size over double-sided assembly to reduce cost and simplify enclosure
- Provide Tag-Connect pads for MCU programming
- Include three fiducials on the assembled side
- Avoid single-sourcing; specify at least two MPNs where practical (exceptions: MCU or unique sensors)
- Evaluate cost-effective alternatives on LCSC, including reputable Chinese brands, not only established manufacturers

## Layout Guidance

- Respect creepage/clearance across isolation barrier; route isolated and non-isolated grounds appropriately
- Keep high-current paths wide and short; minimize loop area
- Place ESD and GDT near connectors; filter supply rails for ADC measurements
- Provide DIN rail mounting holes in accordance with enclosure spec

## CAD Toolchain

- Tool: Altium Designer
- Projects: live under the `altium/` subfolder of this device
- Main project: `current-sensor.PcbDoc`
- Notes: Open the `.PcbDoc` in Altium Designer; generate fabrication outputs via Altium Designer.

## Copyright and License

Copyright © 2026 Newmatik. All rights reserved. Licensed under the Apache License, Version 2.0. See `website/content/license.md` for details.

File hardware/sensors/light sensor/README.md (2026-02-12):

# EsoCore Light Sensor

## PCB Specification

- Board: 2-layer FR4 1.55 mm +/-10%
- Dimensions: Approx. 45 × 35 mm
- Surface finish: ENIG
- Copper: 35 µm (1 OZ)
- Black soldermash / white silkscreen

## Hardware

- MCU: STM32G031K8T6 (TSSOP20), 8 MHz crystal
- Sensor: TSL2591 visible light sensor (high dynamic range 0.002-32k lux)
- Sensor: VEML6075 UVA/UVB light sensor for UV exposure monitoring
- Sensor: MLX90614 infrared temperature sensor for non-contact measurement
- Sensor: TCS34725 RGB color light sensor with IR blocking filter
- Sensor: AS7341 10-channel spectral sensor (380-1000nm)
- Bus: RS‑485 half‑duplex (SN65HVD72), bias/termination network
- Power: 12 V bus → 3.3 V buck (TPS62172) + LDO (MCP1700) for clean analog
- Connectors: Two pluggable RS‑485 ports (IN and OUT): plug `2EDGK-5.0-04P` ↔ PCB mate `2EDGR-5.0-04P`; silk labels A/B/12V/GND; signal loop‑through;
  PG9 cable gland
- Protection: ESD arrays on bus/power lines
- Addressing: 8‑position SMD DIP; 1–7 = Modbus address bits, 8 = 120 Ω termination enable; silkscreen: "1‑7=ADDR, 8=TERM, ON/OFF"
- Indicators: Green status LED
- Programming: Tag‑Connect SWD footprint

## Applications

- Workplace lighting compliance monitoring
- UV exposure safety monitoring for workers
- Process control for light-sensitive manufacturing
- Emergency lighting system validation
- Color quality control in production processes
- Spectral analysis for material characterization
- Non-contact temperature measurement
- Environmental light level monitoring

## General Layout Requirements

- Black solder mask with white silk screen
- Silk screen for important components with information value only (such as connectors)
- Prefer SMD components; avoid THT where feasible
- Single-sided assembly: place all SMD and THT on one side only (no backside assembly)
- Prefer increasing PCB size over double-sided assembly to reduce cost and simplify enclosure
- Provide Tag-Connect pads for MCU programming
- Include three fiducials on the assembled side
- Avoid single-sourcing; specify at least two MPNs where practical (exceptions: MCU or unique sensors)
- Evaluate cost-effective alternatives on LCSC, including reputable Chinese brands, not only established manufacturers

## Layout Guidance

- Position light sensors to avoid mutual interference
- Use optical diffusers for uniform light measurement
- Keep sensor apertures unobstructed
- Provide proper shielding from electromagnetic interference
- Separate analog and digital grounds; single-point tie
- Include light baffles to prevent cross-talk between sensors
- Allow space for optical components and mounting hardware

## CAD Toolchain

- Tool: Altium Designer
- Projects: live under the `altium/` subfolder of this device
- Main project: `light-sensor.PcbDoc`
- Notes: Open the `.PcbDoc` in Altium Designer; generate fabrication outputs via Altium Designer.

## Copyright and License

Copyright © 2026 Newmatik. All rights reserved. Licensed under the Apache License, Version 2.0. See `website/content/license.md` for details.

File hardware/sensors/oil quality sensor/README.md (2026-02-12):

# EsoCore Oil Quality Sensor

## PCB Specification

- Board: 2-layer FR4 1.55 mm +/-10%
- Dimensions: Approx. 60 × 45 mm
- Surface finish: ENIG
- Copper: 35 µm (1 OZ)
- Black soldermash / white silkscreen

## Hardware

- MCU: STM32G031K8T6 (TSSOP20), 8 MHz crystal
- Sensor: Turbidity sensor for contamination detection
- Sensor: DS18B20 oil temperature sensor
- Sensor: Piezoelectric viscosity sensor
- Sensor: Capacitive water content sensor
- Sensor: Dielectric constant sensor
- Bus: RS‑485 isolated transceiver (ADM2582E)
- Power: Isolated 12V→5V DC/DC (NXE1S1205MC) → 3.3 V LDO (MCP1700)
- Connectors: Two pluggable RS‑485 ports (IN and OUT): plug `2EDGK-5.0-04P` ↔ PCB mate `2EDGR-5.0-04P`; silk labels A/B/12V/GND; signal loop‑through;
  PG9 cable gland
- Protection: GDT surge suppressor, ESD arrays, oil filter mesh
- Addressing: 8‑position SMD DIP; 1–7 = Modbus address bits, 8 = 120 Ω termination enable; silkscreen: "1‑7=ADDR, 8=TERM, ON/OFF"
- Indicators: Green status LED
- Programming: Tag‑Connect SWD footprint

## Applications

- Gearbox oil condition monitoring
- Hydraulic oil quality assessment
- Lubrication system health monitoring
- Predictive maintenance for oil-lubricated equipment
- Contamination detection in industrial lubricants
- Oil degradation trend analysis

## General Layout Requirements

- Black solder mask with white silk screen
- Silk screen for important components with information value only (such as connectors)
- Prefer SMD components; avoid THT where feasible
- Single-sided assembly: place all SMD and THT on one side only (no backside assembly)
- Prefer increasing PCB size over double-sided assembly to reduce cost and simplify enclosure
- Provide Tag-Connect pads for MCU programming
- Include three fiducials on the assembled side
- Avoid single-sourcing; specify at least two MPNs where practical (exceptions: MCU or unique sensors)
- Evaluate cost-effective alternatives on LCSC, including reputable Chinese brands, not only established manufacturers

## Layout Guidance

- Respect creepage/clearance across isolation barrier
- Keep high-current paths wide and short
- Place ESD and GDT near connectors
- Include oil sampling port with proper sealing
- Provide oil filter mesh protection for sensors
- Separate oil and electronics compartments
- Allow space for oil-resistant gaskets and seals

## CAD Toolchain

- Tool: Altium Designer
- Projects: live under the `altium/` subfolder of this device
- Main project: `oil-quality-sensor.PcbDoc`
- Notes: Open the `.PcbDoc` in Altium Designer; generate fabrication outputs via Altium Designer.

## Copyright and License

Copyright © 2026 Newmatik. All rights reserved. Licensed under the Apache License, Version 2.0. See `website/content/license.md` for details.

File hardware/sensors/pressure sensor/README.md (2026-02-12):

# EsoCore Pressure Sensor

## PCB Specification

- Board: 2-layer FR4 1.55 mm +/-10%
- Dimensions: Approx. 50 × 40 mm
- Surface finish: ENIG
- Copper: 35 µm (1 OZ)
- Black soldermash / white silkscreen

## Hardware

- MCU: STM32G031K8T6 (TSSOP20), 8 MHz crystal
- Sensor: MPRLS0300YG00001BB (0-10 bar gauge pressure, Honeywell, I2C/SPI)
- Sensor: BMP388 (barometric pressure, 300-1250 hPa / 0.3-1.25 bar absolute)
- Sensor: BMP280 (barometric pressure, 300-1100 hPa / 0.3-1.1 bar absolute)
- Bus: RS‑485 half‑duplex (SN65HVD72), bias/termination network
- Power: 12 V bus → 3.3 V buck (TPS62172) + LDO (MCP1700) for clean analog
- Connectors: Two pluggable RS‑485 ports (IN and OUT): plug `2EDGK-5.0-04P` ↔ PCB mate `2EDGR-5.0-04P`; silk labels A/B/12V/GND; signal loop‑through;
  PG9 cable gland
- Protection: ESD arrays on bus/power, pressure relief valve
- Addressing: 8‑position SMD DIP; 1–7 = Modbus address bits, 8 = 120 Ω termination enable; silkscreen: "1‑7=ADDR, 8=TERM, ON/OFF"
- Indicators: Green status LED
- Programming: Tag‑Connect SWD footprint

## Applications

- Hydraulic system pressure monitoring
- Pneumatic system pressure monitoring
- Pump performance monitoring
- Filter clogging detection
- Leak detection in pressurized systems
- Process pressure control validation

## General Layout Requirements

- Black solder mask with white silk screen
- Silk screen for important components with information value only (such as connectors)
- Prefer SMD components; avoid THT where feasible
- Single-sided assembly: place all SMD and THT on one side only (no backside assembly)
- Prefer increasing PCB size over double-sided assembly to reduce cost and simplify enclosure
- Provide Tag-Connect pads for MCU programming
- Include three fiducials on the assembled side
- Avoid single-sourcing; specify at least two MPNs where practical (exceptions: MCU or unique sensors)
- Evaluate cost-effective alternatives on LCSC, including reputable Chinese brands, not only established manufacturers

## Layout Guidance

- Separate analog and digital grounds; single-point tie
- Place pressure sensors away from heat sources
- Include pressure relief valve for safety
- Route RS‑485 differential pair with proper spacing
- Provide proper sealing for pressure ports
- Allow space for pressure fittings and relief valve

## CAD Toolchain

- Tool: Altium Designer
- Projects: live under the `altium/` subfolder of this device
- Main project: `pressure-sensor.PcbDoc`
- Notes: Open the `.PcbDoc` in Altium Designer; generate fabrication outputs via Altium Designer.

## Copyright and License

Copyright © 2026 Newmatik. All rights reserved. Licensed under the Apache License, Version 2.0. See `website/content/license.md` for details.

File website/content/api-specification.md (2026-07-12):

# API Specification

This document defines the REST APIs, authentication mechanisms, and cloud platform specifications for the EsoCore IoT system using Django REST
Framework.

---

## Cloud Platform Architecture

Any capable backend can fulfill these roles. The following concrete model assumes Django + Django REST Framework for speed and maintainability.

### Django Models / Core Data Model

- **Device**: id, serial, model, keys, firmware, last_seen, site/customer, tags, status
- **Asset**: asset_id, site/customer, type (door/cnc/robot/etc.), make, model
- **Telemetry Packet (ingest ledger)**: device_id, upload_id, checksum, status
- **Timeseries (partitioned)**:
  - TelemetryPoint: ts, device_id, metric, value, unit, meta (JSON)
  - TelemetryWindow: ts, device_id, metric, stats (rms/max/std/bandpower)
- **System Events**:
  - SystemEvent: ts, device_id, event_type, severity, description, duration, resolved
  - EventLog: comprehensive audit trail with full context and metadata
- **Asset Events**: cycle_open, cycle_close, alerts (over‑torque, vibration)
- **Event Workflows**: automated response rules triggered by system events
- **Notification Queue**: pending alerts with delivery status and retries
- **Config Profile**: sampling rates, window sizes, thresholds per device type
- **Firmware Bundle**: version, hash, channel (stable/beta), rollout policy
- **Alert Rule & Notification**: thresholds, conditions, recipients, channels
- **Customer Portal Models**: Site, UserDeviceRole, Dashboards

---

## REST API (Device-Facing)

### Authentication Endpoint

```text
POST /api/iot/v1/auth/handshake
```

Returns nonce & server time (optional)

### Telemetry Upload

```text
POST /api/iot/v1/telemetry/batch
```

**Headers:**

- `X-Device-Id`: Unique device identifier
- `X-Auth-Key`: Device authentication key
- `Idempotency-Key`: UUIDv4 for duplicate detection
- `Content-SHA256`: Request body hash

**Body:** gzip/zstd JSON batch

**Response:**

```json
{
  "accepted": 1250,
  "duplicates": 3,
  "rejected": 0,
  "next_hint": "backoff_ms: 5000"
}
```

### Configuration Management

```text
GET /api/iot/v1/config
```

Returns device configuration (sampling rates, thresholds, NTP servers, endpoints)

### OTA Management

```text
GET /api/iot/v1/ota/check
```

Returns firmware version and signed download URL

```text
POST /api/iot/v1/ota/report
```

Device reports OTA update status

### Authentication Methods

- **Django API Key/Secret** per Device (using django-rest-framework-api-key), or
- **OAuth2 Client Credentials** for central key rotation
- **JWT Authentication** for user sessions

---

## Sync Logic & Protocol

### Authentication

- **Device API Key/Secret** (provisioned once), HMAC on body, and TLS
- **Key rotation** via OTA updates

### Data Batching

- **Batch size**: ~1–5 MB or 5–10k records per POST
- **Compression**: gzip or zstd compression

### Idempotency & Reliability

- **Idempotency-Key** header (UUIDv4) + server‑side deduplication
- **Exponential backoff** with jitter
- **Priority queuing**: newest data first, then backfill

### Clock Synchronization

- **NTP** at boot and every 12 hours
- **Firmware tolerance**: ±2 min skew
- **Server re-stamping**: available on request

---

## Event Processing & Workflow Automation

### Event Ingestion Pipeline

```text
System Event → Event Parser → Severity Classification → Workflow Trigger → Notification Queue → Delivery
```

### Workflow Examples

| Event Type | Trigger Condition | Automated Actions |
| --- | --- | --- |
| `connectivity_lost` | Duration > 5 minutes  | Email to maintenance team, escalate if > 30 min |
| `power_outage` | Severity = critical | Immediate SMS + email, create maintenance ticket |
| `safe_shutdown_initiated` | Any occurrence | Critical alert + incident creation, prepare site visit |
| `supercap_low` | Voltage < 80% rated | Maintenance alert, check backup power system |
| `safety_input_triggered` | Any safety activation | Immediate alert, log safety event, verify relay state  |
| `safety_cross_monitor_fault` | Any occurrence | Critical alert, force safe state, create incident |
| `server_unreachable` | Retry count > 5 | Notify IT team, check server status |
| `sensor_fault` | Any sensor failure | Schedule maintenance, disable affected alerts |
| `tamper_detected` | Security event | Instant security team alert, log incident |
| `sd_error` | Storage failure | Emergency notification, prepare replacement |

### Django Workflow Integration

- **Model Workflows**: Auto-create maintenance tickets from critical events (using django-workflows or custom logic)
- **Email Templates**: Customizable notifications with event context (Django templates + django-mailer)
- **Notification Hooks**: Slack/Teams/webhook integrations (django-notifications or custom webhooks)
- **Escalation Rules**: Time-based escalation chains (L1 → L2 → L3 support)
- **Conditional Logic**: Event severity, time of day, on-call schedules (Django signals + custom logic)
- **Batch Processing**: Group related events to prevent alert fatigue (Django Celery tasks)

### Event Correlation

- **Pattern Detection**: Identify recurring issues across device fleet
- **Root Cause Analysis**: Link cascading events (power → connectivity → sync failure)
- **Anomaly Detection**: Machine learning on event patterns for predictive alerting

---

## Admin & UX Features

### Dashboards

**Per device & per site:**

- Live status (online/offline), last sync, SD health, firmware version
- Trends: ambient/stator temperature, RH, torque/current, vibration RMS/bandpower, acoustics level/features
- Asset cycle counters & daily/weekly histograms

### Alerting System

- **Email/Slack/Webhooks** for thresholds (e.g., over‑torque, rising vibration, elevated acoustics/ultrasound events)
- **Device offline** notifications
- **Sync backlog** alerts

### Data Management

- **Data Explorer**: filter by site/door/device/metric/time, CSV/Parquet export
- **Device Provisioning UI**: create Device, print claim QR (Device ID + bootstrap token), see first‑seen time & firmware channel

### Access Control

- **RBAC**: Customer can see only their sites/devices

## Storage & Performance

### Database Design

- **Partitioning**: tables by month for telemetry; indexes on `(device_id, ts)` and `(metric, ts)` (using django-partitions)
- **External TSDB (optional)**: TimescaleDB/ClickHouse via Django integration for heavy analytics
- **Cold storage**: optional S3 for raw vibration windows (using django-storages)
- **Database**: SQLite for development, PostgreSQL/MySQL for production

---

## Device Provisioning & Security

### Manufacturing Process

- **Flash firmware**: inject unique `device_id`, API key/secret, and initial config
- **QR code generation**: for technician claiming process

### Device Claiming

- **Technician process**: scan QR → portal links device to customer/site → server enables the key
- **Security**: device remains inactive until properly claimed

### Security Features

- **Mutual TLS (optional tier)**: pin server CA; rotate keys annually; OTA key roll supported
- **Secure boot & OTA**: signed images, A/B partition, automatic rollback on watchdog

---

## Sync & Reliability Details

### Offline Buffer Management

- **Minimum capacity**: 30 days at nominal rates (size calculated during design)
- **Resume capability**: maintain upload cursor per file + per record offset
- **Recovery**: on reconnect, resume at last acknowledged position

### Duplicate Protection

- **Server storage**: `(device_id, batch_id, record_hash)` for 30 days
- **Idempotency**: guarantee exactly-once processing

### Backpressure Control

- **Server response**: `next_hint: backoff_ms` for rate limiting
- **Dynamic configuration**: server can reduce device sampling via `/config` endpoint

---

## Error Handling

### HTTP Status Codes

- **200**: Successful data ingestion
- **400**: Invalid request format
- **401**: Authentication failure
- **409**: Duplicate data (idempotency key conflict)
- **429**: Rate limiting active
- **500**: Server error
- **503**: Service unavailable (maintenance mode)

### Retry Logic

- **Exponential backoff**: starting at 1s, max 300s
- **Jitter**: ±25% to prevent thundering herd
- **Circuit breaker**: fail fast after consecutive failures
- **Fallback**: local storage with sync on recovery

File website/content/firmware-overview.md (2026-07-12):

# Firmware

EsoCore firmware (v1.5.0) is written in C (C11) and targets two families of STM32 microcontrollers: the STM32H7
series for the Edge device and the STM32G0 series for sensor modules. The build system uses GNU Make with the ARM
GCC cross-compiler toolchain.

This page covers the firmware architecture, code structure, build system, and how to set up a development environment
for building and flashing firmware.

---

## Architecture

The firmware follows a bare-metal cooperative (superloop) architecture with a shared common library and
target-specific code for each device type. The HAL layer uses CMSIS device headers for register definitions with
thin, custom wrappers -- no dependency on ST's HAL library.

| Target | MCU | Core | Clock | Purpose |
| --- | --- | --- | --- | --- |
| **Edge** | STM32H747IIT6 | Cortex-M7 (+ M4) | 480 MHz | Central hub: dual Ethernet, analog acquisition, fieldbus, TinyML |
| **Sensors** | STM32G031xx | Cortex-M0+ | 64 MHz  | Individual sensor modules connected via RS-485 bus |

The Edge device runs on the Cortex-M7 core of the dual-core STM32H747 at 480 MHz (PLL1 from 25 MHz HSE). It
manages:

- **Dual Ethernet** -- Port A (Machine/OT: PROFINET RT, Modbus TCP, static IP) and Port B (IT: HTTPS cloud sync,
  DHCP, OTA) via two KSZ8081RNACA PHYs
- **4-channel analog inputs** -- Dual-mode IEPE + DC with 24-bit simultaneous ADC (ADS1274) at 50 kSPS per channel,
  programmable gain (PGA280), and DMA double-buffered capture
- **6 dual-channel safety digital inputs** -- EN ISO 13849 Category 3 compliant with cross-monitoring
- **RS-485 sensor bus** -- Auto-discovery, hot-plug, 12V distributed power for sensor modules
- **Fieldbus interfaces** -- Modbus RTU, PROFIBUS DP, Interbus (each on dedicated isolated RS-485)
- **24V DC power management** -- Brownout detection, multi-rail monitoring, supercapacitor backup (20F, 3.8V)
- **Local storage** -- MicroSD with power-safe writes
- **Edge intelligence** -- TinyML inference for anomaly detection
- **Connectivity** -- ESP32-S3 WiFi/BT via UART AT commands

Each sensor module runs on a low-power STM32G0 MCU. Sensor firmware handles sampling, local signal conditioning, and
communication with the Edge over the RS-485 multi-drop bus.

---

## Code Structure

The firmware repository is organized under the `firmware/` directory:

```
firmware/
├── Makefile                    # Top-level build system
├── common/                     # Shared library code (used by both edge and sensors)
│   ├── analog/                 # Analog input subsystem and signal chain
│   ├── communication/          # Ethernet manager, sensor bus, Interbus, Modbus, HTTP, Wi-Fi
│   ├── storage/                # Sensor interface, SD card storage system
│   ├── safety/                 # Safety I/O handling (digital inputs + relay/SSR outputs)
│   ├── management/             # Power management (24V DC), configuration manager
│   ├── intelligence/           # Event system, TinyML inference engine
│   └── ui/                     # OLED display driver
├── stm32/
│   ├── edge/                   # Edge device application (main.c)
│   ├── sensors/                # Sensor module applications (main.c + per-sensor drivers)
│   ├── stm32h7/               # STM32H7 custom HAL, BSP, drivers, CMSIS, linker, startup
│   │   ├── bsp/               # Board support: pin mapping, system clock, board config
│   │   ├── cmsis/             # Minimal CMSIS device headers for STM32H747
│   │   ├── hal/               # Custom HAL: GPIO, SPI, UART, I2C, DMA, Timer, ETH, ADC
│   │   ├── drivers/           # Hardware drivers: KSZ8081, ADS1274, PGA280, TMUX1101, etc.
│   │   ├── linker/            # Linker script for Cortex-M7 (Flash + multi-region SRAM)
│   │   └── startup/           # Vector table and reset handler (assembly)
│   └── stm32g0/               # STM32G0 HAL, CMSIS, linker scripts, startup code
```

### Common Library

The `common/` directory contains platform-independent modules shared across firmware targets:

- **analog/**: 4-channel analog input manager (`analog_input`) with dual-mode IEPE/DC switching, programmable gain
  control, continuous DMA-driven acquisition from the ADS1274 ADC, and signal chain utilities for voltage conversion
  and noise floor calculation.
- **communication/**: Dual Ethernet manager (`ethernet_manager`) for isolated OT/IT networking, RS-485 sensor bus
  manager (`sensor_bus`) with auto-discovery and hot-plug, Interbus protocol layer (`interbus`), HTTP client for
  cloud sync, Wi-Fi management (ESP32-S3), Modbus RTU, and shared protocol layer.
- **storage/**: Sensor data interface abstraction and microSD storage system with wear leveling and power-safe writes.
- **safety/**: Safety I/O management for the 6 dual-channel optocoupled digital inputs (EN ISO 13849 Category 3)
  with cross-monitoring and periodic test pulses. Controls a safety relay (G7SA-2A2B) and solid-state relay
  (AQY212EHAZ) for outputs.
- **management/**: Power management for the 24V DC input system with multi-rail voltage monitoring via internal ADC,
  brownout state machine, supercapacitor charge estimation, power-up/down sequencing, and graceful shutdown.
  Runtime configuration management.
- **intelligence/**: Event system for structured event logging, and the TinyML inference engine for on-device anomaly
  detection.
- **ui/**: OLED display driver for local status display on the Edge device.

### STM32H7 HAL and Drivers

The custom HAL provides thin register-level wrappers using CMSIS device headers. No dependency on ST's HAL/LL
libraries -- every peripheral is configured via direct register writes for transparency and control.

**HAL modules** (`stm32h7/hal/`):

| Module | Description |
| --- | --- |
| `hal_gpio`  | Pin configuration, atomic read/write/toggle, alternate function setup |
| `hal_spi` | Blocking and DMA transfers; double-buffer mode for continuous ADC capture |
| `hal_uart`  | Blocking/interrupt TX/RX, RS-485 DE/RE control, RX callback |
| `hal_i2c` | Master read/write with register addressing, 100/400 kHz timing |
| `hal_eth` | Dual Ethernet MAC init, DMA descriptors, MDIO PHY management, frame TX/RX |
| `hal_dma` | Stream config with DMAMUX routing, circular and double-buffer modes |
| `hal_timer` | Periodic interrupt timers, microsecond delay via TIM2 |
| `hal_adc` | Internal ADC3 for power rail monitoring and die temperature readback |
| `hal_init`  | Centralized GPIO initialization for all board pins from pin mapping |

**Hardware drivers** (`stm32h7/drivers/`):

| Driver | IC | Description |
| --- | --- | --- |
| `drv_ksz8081`  | KSZ8081RNACA  | 10/100 Ethernet PHY (x2) -- auto-negotiation, link status |
| `drv_ads1274`  | ADS1274 | 24-bit 4-channel simultaneous ADC -- SPI + DMA continuous capture |
| `drv_pga280` | PGA280 | Programmable gain amplifier -- SPI register interface |
| `drv_tmux1101` | TMUX1101 | SPDT analog switch -- IEPE/DC mode selection per channel |
| `drv_iepe` | REF200AU gate | IEPE 4 mA current source enable/disable per channel |
| `drv_ssr` | AQY212EHAZ | Solid-state relay output control |

**BSP** (`stm32h7/bsp/`):

- `pin_mapping_v150.h` -- Complete GPIO pin assignment for all v1.5.0 peripherals
- `bsp_edge_v150.h` -- Board configuration: version, feature flags, power rail thresholds, defaults
- `system_clock.c` -- Full clock tree setup: 25 MHz HSE, PLL1 (480 MHz SYSCLK), PLL2 (50 MHz ETH), PLL3

### Sensor Drivers

Individual sensor types each have a dedicated source file under `stm32/sensors/`:

- `vibration_sensor.c` -- ADXL355 3-axis accelerometer with FFT processing
- `acoustic_sensor.c` -- Audible and ultrasonic microphone sampling
- `current_sensor.c` -- Motor current monitoring via hall-effect sensor
- `air_quality_sensor.c` -- Temperature, humidity, CO2, VOC, particulate matter
- `oil_quality_sensor.c` -- Viscosity, contamination, water content
- `pressure_sensor.c` -- Hydraulic/pneumatic pressure monitoring
- `temperature_spot_sensor.c` -- NTC, RTD, thermocouple, and IR sensor support
- `proximity_position_sensor.c` -- Inductive/capacitive proximity and position encoding
- `light_sensor.c` -- Visible, UV, IR, and spectral light measurement

---

## Toolchain

### Required Tools

| Tool | Version | Purpose |
| --- | --- | --- |
| `arm-none-eabi-gcc` | 10+ | Cross-compiler for ARM Cortex-M targets |
| `arm-none-eabi-objcopy` | (bundled) | Binary format conversion (ELF to HEX/BIN) |
| `arm-none-eabi-size` | (bundled) | Memory usage reporting |
| GNU Make | 4.0+ | Build system |
| OpenOCD or STM32CubeProgrammer | latest | Flashing and debugging |
| ST-LINK V2/V3 | -- | Debug probe hardware (SWD interface) |

### Installing the Toolchain

**macOS (Homebrew):**

```bash
brew install --cask gcc-arm-embedded
brew install make
```

**Ubuntu/Debian:**

```bash
sudo apt-get install gcc-arm-none-eabi make
```

**Windows:**

Download the [GNU Arm Embedded Toolchain](https://developer.arm.com/Tools%20and%20Software/GNU%20Toolchain) installer
from ARM and add it to your PATH. Install Make via MSYS2 or use the version bundled with STM32CubeIDE.

Verify your installation:

```bash
arm-none-eabi-gcc --version
make --version
```

---

## Build System

The firmware uses a GNU Make build system defined in `firmware/Makefile`. All builds are invoked from the `firmware/`
directory.

### Build Targets

**Edge device:**

```bash
make edge                # Build Edge firmware (STM32H7, Cortex-M7)
```

**Individual sensor modules:**

```bash
make vibration           # Build vibration sensor firmware
make acoustic            # Build acoustic sensor firmware
make current             # Build current sensor firmware
make air_quality         # Build air quality sensor firmware
make oil_quality         # Build oil quality sensor firmware
make pressure            # Build pressure sensor firmware
make temperature         # Build temperature sensor firmware
make proximity           # Build proximity sensor firmware
```

**All targets:**

```bash
make all                 # Build edge + all sensor modules
make sensors             # Build all sensor modules only
```

**Other commands:**

```bash
make clean               # Remove all build artifacts
make info                # Print build system configuration
make help                # Show all available targets and options
```

### Build Options

| Option | Default | Description |
| --- | --- | --- |
| `DEBUG=1` | `0` | Enable debug build (`-O0`, debug symbols, `DEBUG` macro defined) |
| `OPTIMIZATION` | `-O2` | Compiler optimization level |

Example debug build:

```bash
make edge DEBUG=1
```

### Build Output

Build artifacts are placed in the `build/` directory:

```
build/
├── edge/
│   ├── esocore_edge.elf       # Linked ELF binary (for debugging)
│   ├── esocore_edge.hex       # Intel HEX (for flashing)
│   └── esocore_edge.bin       # Raw binary
└── sensors/
    ├── vibration/
    │   ├── esocore_vibration.elf
    │   ├── esocore_vibration.hex
    │   └── esocore_vibration.bin
    └── ...
```

### Compiler Configuration

The build uses the following key compiler flags:

- **Standard**: C11 (`-std=c11`)
- **Warnings**: `-Wall -Wextra -Wpedantic -Wshadow -Wconversion -Wsign-conversion`
- **Optimization**: `-ffunction-sections -fdata-sections` with `-Wl,--gc-sections` for dead code elimination
- **Specs**: `nano.specs` and `nosys.specs` for minimal C library (newlib-nano)

MCU-specific flags are applied per target:

- **Edge (Cortex-M7)**: `-mcpu=cortex-m7 -mthumb -mfpu=fpv5-d16 -mfloat-abi=hard`
- **Sensors (Cortex-M0+)**: `-mcpu=cortex-m0plus -mthumb`

---

## Flashing and Debugging

### Flashing with OpenOCD

Connect an ST-LINK probe to the target board via the SWD header, then:

```bash
openocd -f interface/stlink.cfg -f target/stm32h7x.cfg \
  -c "program build/edge/esocore_edge.hex verify reset exit"
```

For sensor modules (STM32G0):

```bash
openocd -f interface/stlink.cfg -f target/stm32g0x.cfg \
  -c "program build/sensors/vibration/esocore_vibration.hex verify reset exit"
```

### Flashing with STM32CubeProgrammer

```bash
STM32_Programmer_CLI -c port=SWD -d build/edge/esocore_edge.hex -v -rst
```

### Debugging with GDB

Start OpenOCD as a GDB server, then connect:

```bash
# Terminal 1: start OpenOCD
openocd -f interface/stlink.cfg -f target/stm32h7x.cfg

# Terminal 2: connect GDB
arm-none-eabi-gdb build/edge/esocore_edge.elf
(gdb) target remote :3333
(gdb) monitor reset halt
(gdb) load
(gdb) continue
```

VS Code users can use the Cortex-Debug extension for integrated debugging with breakpoints and variable inspection.

---

## Release Packaging

To create a release archive containing all firmware binaries:

```bash
make release
```

This builds all targets and packages the `.bin` and `.hex` files into
`release/esocore_v1.5.0.tar.gz`.

---

## Future Plans

The documentation for the Edge device references Zephyr RTOS as the long-term target OS for the edge firmware. The
current implementation is bare-metal C with direct HAL access. A migration to Zephyr would bring:

- Deterministic real-time scheduling with preemptive multitasking
- Mature networking stack (TCP/IP, TLS, MQTT)
- Built-in filesystem support (LittleFS, FAT)
- Standardized OTA update mechanisms
- `west` and CMake-based build system for reproducible builds

The sensor module firmware will remain bare-metal due to the constrained resources of the Cortex-M0+ MCUs.

---

## Related Documentation

- [Edge Hardware](/docs/esocore-edge) -- Edge device hardware specifications
- [Sensors](/docs/esocore-sensors) -- Sensor module hardware catalog
- [Edge Intelligence & TinyML](/docs/edge-intelligence) -- On-device AI and anomaly detection
- [Data Format Specification](/docs/data-format-specification) -- Local storage format and JSON schemas
- [Development Environment](/docs/development-environment) -- Full toolchain setup across all disciplines

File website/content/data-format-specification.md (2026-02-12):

# Data Format Specification

This document defines the data formats, file structures, and event schemas used by the EsoCore edge-to-cloud
telemetry system (firmware v1.5.0).

---

## Local Data Storage Format

**Why standardize the format?** Ensures data integrity, enables audit trails, and simplifies cloud
synchronization across different firmware versions.

### File Organization

```text
SD Card Structure:
├── 202501/
│   ├── DEVICE001_20250115_143022_001.json.zst
│   ├── DEVICE001_20250115_150000_002.json.zst
│   └── ...
└── 202502/
    └── ...
```

### Technical Specifications

- **Data Format**: JSON (JavaScript Object Notation) - human-readable, widely supported, easier debugging and maintenance
- **Compression**: Zstandard (.zst) for ~70% size reduction
- **File Naming**: `YYYYMM/DEVICEID_YYYYMMDD_HHMMSS_SEQ.json.zst`
- **Rotation**: New file every 1MB or 1 hour (configurable)

---

## Data Record Schemas

### Sensor Data Record

Each sensor reading contains:

```json
{
  "ts": "2025-01-15T14:30:22.123Z", // Timestamp (UTC)
  "device_id": "DEVICE001", // Unique device identifier
  "site_id": "WAREHOUSE_A", // Installation location
  "asset_id": "ASSET_3", // Specific asset/machine
  "series": "temp_ambient", // Data type (sensor data or system event)
  "val": 23.5, // Measurement value (null for events)
  "unit": "°C", // Unit of measurement
  "meta": {
    // Additional context
    "firmware_ver": "1.5.0.0",
    "sensor_id": "SHT40_01",
    "sample_rate": 1000
  }
}
```

### System Event Records

In addition to sensor data, the system captures operational events:

#### Network Connectivity Event

```json
{
  "ts": "2025-01-15T14:35:10.456Z",
  "device_id": "DEVICE001",
  "site_id": "WAREHOUSE_A",
  "asset_id": "ASSET_3",
  "series": "connectivity_lost",
  "val": null,
  "unit": null,
  "meta": {
    "event_type": "network",
    "severity": "warning",
    "description": "WiFi connection lost - switching to offline mode",
    "duration_ms": 45000,
    "retry_count": 3
  }
}
```

#### Power Event

```json
{
  "ts": "2025-01-15T09:22:33.123Z",
  "device_id": "DEVICE001",
  "site_id": "WAREHOUSE_A",
  "asset_id": "ASSET_3",
  "series": "power_outage",
  "val": null,
  "unit": null,
  "meta": {
    "event_type": "power",
    "severity": "critical",
    "description": "24V DC input lost - running on supercap backup",
    "input_voltage_mv": 0,
    "rail_3v3_mv": 3280,
    "rail_1v2_mv": 1195,
    "supercap_voltage_mv": 3650,
    "supercap_charge_pct": 82,
    "estimated_runtime_sec": 25
  }
}
```

#### Safety Event

```json
{
  "ts": "2025-01-15T11:45:22.789Z",
  "device_id": "DEVICE001",
  "site_id": "WAREHOUSE_A",
  "asset_id": "ASSET_3",
  "series": "safety_input_triggered",
  "val": null,
  "unit": null,
  "meta": {
    "event_type": "safety",
    "severity": "critical",
    "description": "Emergency stop activated - dual-channel safety input triggered",
    "input_channel": "SI_1",
    "input_type": "emergency_stop",
    "channel_a_state": true,
    "channel_b_state": true,
    "cross_monitor_ok": true,
    "response_time_ms": 4
  }
}
```

#### Safe Shutdown Event

```json
{
  "ts": "2025-01-15T09:22:35.456Z",
  "device_id": "DEVICE001",
  "site_id": "WAREHOUSE_A",
  "asset_id": "ASSET_3",
  "series": "safe_shutdown_initiated",
  "val": null,
  "unit": null,
  "meta": {
    "event_type": "power",
    "severity": "critical",
    "description": "Emergency shutdown sequence started - graceful power-down",
    "supercap_voltage_mv": 3200,
    "supercap_charge_pct": 55,
    "data_flushed_mb": 2.4,
    "shutdown_reason": "brownout_critical"
  }
}
```

#### Analog Input Event

```json
{
  "ts": "2025-01-15T14:42:11.890Z",
  "device_id": "DEVICE001",
  "site_id": "WAREHOUSE_A",
  "asset_id": "ASSET_3",
  "series": "analog_acquisition",
  "val": null,
  "unit": null,
  "meta": {
    "event_type": "analog",
    "severity": "info",
    "channel": 0,
    "mode": "iepe",
    "gain": 10,
    "sample_rate_sps": 50000,
    "rms_uv": 4520,
    "peak_uv": 18200,
    "adc_bits": 24
  }
}
```

#### Ethernet Port Event

```json
{
  "ts": "2025-01-15T14:38:05.321Z",
  "device_id": "DEVICE001",
  "site_id": "WAREHOUSE_A",
  "asset_id": "ASSET_3",
  "series": "eth_link_change",
  "val": null,
  "unit": null,
  "meta": {
    "event_type": "network",
    "severity": "warning",
    "port": "A",
    "role": "OT",
    "link_state": "down",
    "phy": "KSZ8081",
    "speed_mbps": 100,
    "duplex": "full"
  }
}
```

---

## Event Categories

### Power Events

- `power_outage` - 24V DC input lost
- `power_restored` - 24V DC input restored
- `brownout_warning` - Input voltage below warning threshold
- `brownout_critical` - Input voltage below critical threshold, shutdown imminent
- `rail_fault` - Individual power rail (5V, 3.3V, 1.2V, 3.3VA) out of tolerance
- `backup_activated` - Supercapacitor backup engaged
- `supercap_low` - Supercapacitor charge below safe threshold
- `safe_shutdown_initiated` - Graceful shutdown sequence started

### Safety Events

- `safety_input_triggered` - Safety input activated (dual-channel confirmed)
- `safety_cross_monitor_fault` - Dual-channel cross-monitoring mismatch detected
- `safety_input_stuck` - Safety input stuck-at fault detected
- `safety_relay_activated` - Safety relay output energized
- `safety_relay_fault` - Safety relay feedback mismatch
- `safety_ssr_activated` - Solid-state relay (AQY212EHAZ) output activated
- `safety_test_pulse` - Periodic safety input test pulse executed

### Analog Input Events

- `analog_acquisition` - Analog channel acquisition started or reconfigured
- `analog_mode_change` - Channel mode changed (IEPE/DC)
- `analog_gain_change` - Channel gain reconfigured
- `analog_overrange` - ADC input overrange detected
- `analog_sensor_check` - IEPE sensor connectivity check result

### Network Events

- `eth_link_change` - Ethernet port link state change (up/down)
- `eth_port_a_up` - OT network port link established
- `eth_port_b_up` - IT network port link established
- `connectivity_lost` - Network connection lost
- `connectivity_restored` - Network connection restored
- `server_unreachable` - Cannot reach cloud server
- `sync_failed` - Data synchronization failed

### Fieldbus Events

- `interbus_connected` - Interbus master connection established
- `interbus_disconnected` - Interbus master disconnected
- `interbus_fault` - Interbus communication error
- `sensor_bus_device_found` - New sensor module discovered on RS-485 bus
- `sensor_bus_device_lost` - Sensor module heartbeat timeout
- `sensor_bus_fault` - Sensor bus communication error

### System Events

- `device_boot` - Device startup (v1.5.0 firmware)
- `watchdog_reset` - Independent watchdog (IWDG) reset
- `sd_error` - SD card error
- `sensor_fault` - Sensor malfunction
- `ota_started` - OTA update started
- `ota_completed` - OTA update completed
- `memory_error` - Memory allocation error
- `hardfault` - Cortex-M7 HardFault (logged on next boot)

### Security Events

- `auth_failed` - Authentication failure
- `tamper_detected` - Physical tampering detected
- `config_changed` - Configuration modified
- `enclosure_opened` - Device enclosure opened

---

## Data Integrity & Reliability

- **Power-safe writes**: Atomic file operations prevent corruption during power loss
- **Checksums**: CRC32 per record + SHA-256 per file to detect corruption
- **Audit trail**: Immutable append-only format for compliance requirements
- **Event persistence**: System events logged even during connectivity outages

---

## Data Semantics (Metrics & Rates)

- **Ambient**: temp_ambient (C), RH (%), 1 Hz default; averaged to 1 min for cloud
- **Drive stator temperature**: temp_stator (C), 1 Hz default; per-cycle min/avg/max for load indication
- **Asset cycles**: increment on open-closed or start-stop transitions; event objects carry `cycle_id` and durations
- **Torque proxy**: motor current RMS at 100-500 Hz; compute per-cycle stats (avg/max)
- **Vibration (analog input)**: 4 channels, 24-bit resolution, up to 50 kSPS via ADS1274. Rolling RMS computed
  per acquisition block; periodic high-rate windows for spectral bands (bearing, imbalance). Firmware computes
  RMS and peak values in real time with DMA double-buffered capture.
- **Acoustics**: rolling RMS and event detection; periodic windows in audible/ultrasound bands for spectral
  features; flag high-amplitude events (e.g., spring break)
- **Analog signal chain**: Each channel supports IEPE mode (4 mA current source for accelerometers) or DC mode
  (direct voltage measurement). Programmable gain from 1x to 128x (PGA280). 15 kHz anti-aliasing filter before
  ADC. All 4 channels sampled simultaneously.
- **Derived health KPIs**: over-torque rate, vibration trend slope, mean time between faults
- **Power monitoring**: Internal ADC3 reads 24V input, 5V, 3.3V digital, 3.3V analog, 1.2V core, and die
  temperature at 1 Hz. Brownout state machine transitions logged as events.

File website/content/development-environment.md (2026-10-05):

# Development Environment

This page documents the end-to-end development tooling used across hardware, firmware, mechanical, edge software, and cloud for EsoCore, with
rationale and minimum setup.

---

## PCB Design and Schematics

- **Primary toolchain**: Altium Designer
- **Why**: Professional EDA suite with comprehensive schematic capture, PCB layout, 3D visualization, and manufacturing output generation.
  Industry-standard tool with extensive component libraries and advanced features.

  ### High-Speed Design Capabilities

  Altium Designer excels in high-speed routing and signal integrity with industry-leading features:
  - **Advanced Length Matching**: Intelligent algorithms ensure precise signal timing in high-speed interfaces, critical for reliable communication
  - **Comprehensive Signal Integrity**: Advanced verification tools for high-speed designs including:
    - Differential pair routing with automatic phase matching
    - Impedance control and verification
    - Crosstalk analysis and mitigation
    - Eye diagram simulation and analysis
  - **Real-time Verification**: Continuous verification during routing ensures signal integrity throughout the design process

- **Artifacts**:
  - Source: .PcbDoc, .SchDoc
  - Manufacturing: Gerbers, drill files, IPC-356 netlist, ODB++ (preferred), Pick-and-Place, BOM (CSV/XLSX)
- **Collaboration**: Exported ODB++/Gerbers stored in GitHub Releases for traceability, with schematic/PCB sources versioned in Git.

## Enclosures and Mechanical

- **Primary toolchain**: Autodesk Fusion 360
- **Why**: Professional parametric 3D modeler with strong STEP interoperability, integrated CAM capabilities, generative design, and cloud
  collaboration for mechanical design.
- **Artifacts**:
  - Exchange: .step (AP214/AP242), .stl for 3D printing, drawings as .dxf/.pdf
  - 3D print profiles: PrusaSlicer/Cura project files when applicable
- **Conventions**: All mechanical interfaces (mounting holes, clearances, keep-outs) referenced to PCB origin and exported as STEP for ECAD-MCAD sync.

## Sensor Firmware (MCUs on Sensor Modules)

- **Reference MCU family**: STMicroelectronics STM32 (e.g., STM32G0/G4/F4/H7 as required)
- **IDE/tooling**:
  - Standard: STM32CubeIDE (required for official MCU projects)
  - Alternatives (optional): VS Code + Cortex-Debug + CMake with arm-none-eabi-gcc; CLion with embedded plugin
- **Utilities**:
  - STM32CubeMX for clock/peripheral init code generation
  - ST-LINK CLI (ST-LINK_CLI or STM32_Programmer_CLI) for flashing/debug
  - Serial console: screen/minicom
  - Live plotting: STM32CubeMonitor (modern replacement for legacy STMStudio)
- **Why**: STM32 ecosystem offers robust HAL, long-term availability, and wide community support. The GCC toolchain is open, stable, and reproducible.
- **Build**:
  - Compiler: gcc-arm-none-eabi (10+)
  - CMake presets for Debug/Release, -ffunction-sections -fdata-sections -Wl,--gc-sections
  - Unit tests on host where feasible (pure C modules)
- **Debug/flash**:
  - ST-LINK V2/V3 over SWD; OpenOCD or STM32CubeProgrammer
- **Artifacts**: .elf, .bin, .hex, optional .dfu

## Edge Device Software (Gateway)

- **OS target**: Zephyr RTOS on STM32 (Cortex-M4/M7)
- **Languages**: C/C++ for firmware and services; Python/Node.js optional for host-side tooling
- **Why**: Zephyr provides deterministic real-time scheduling, mature drivers, networking (when needed), secure OTA patterns, and an MCU-focused
  footprint with long-term support. Tooling is standardized around CMake and west for reproducible builds and CI.
- **Tooling**:
  - Build system: Zephyr (CMake + west); Ninja as default generator
  - Cross-compile: Zephyr SDK or arm-none-eabi-gcc toolchain; optional Docker for reproducibility
  - Artifacts: firmware images (.elf/.bin/.hex/.dfu) with versioned metadata
- **Debugging**: gdb via OpenOCD/J-Link, RTT/SWO logging, semihosting; on-target tracing where applicable

### Edge Device Hardware & OS prerequisites

- STM32-based main board (Cortex-M4/M7) with dual Ethernet, microSD, RS-485, RTC, and secure boot/OTA pathway.
- Tooling on dev host: Zephyr SDK, west, CMake/Ninja, OpenOCD or J-Link tools; Python runtime for scripting.
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

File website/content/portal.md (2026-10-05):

# Portal

The EsoCore Portal is a web application that provides the user-facing interface for device monitoring, fleet management,
and data visualization. It connects to the Backend Server APIs and presents real-time dashboards, device management
tools, and alerting interfaces.

---

## Technology Stack
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

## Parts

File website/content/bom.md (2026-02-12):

# Bill of Materials (Overview)

This section lists BOM pages for the Edge and each sensor module. Open a specific BOM to view the current parts list and estimated pricing.

---

## BOM Pages

- [Edge](/docs/bom/edge)
- [Vibration Sensor](/docs/bom/vibration-sensor)
- [Acoustic Sensor](/docs/bom/acoustic-sensor)
- [Current Sensor](/docs/bom/current-sensor)
- [Air Quality Sensor](/docs/bom/air-quality-sensor)
- [Light Sensor](/docs/bom/light-sensor)
- [Oil Quality Sensor](/docs/bom/oil-quality-sensor)
- [Pressure Sensor](/docs/bom/pressure-sensor)
- [Temperature Spot Sensor](/docs/bom/temperature-spot-sensor)
- [Proximity Position Sensor](/docs/bom/proximity-position-sensor)
- [Cables & Interconnects](/docs/bom/cables)

Notes:

- Prices are indicative and exclude assembly.
- CSV sources live under `/public/bom/*.csv` and are rendered by the docs app.

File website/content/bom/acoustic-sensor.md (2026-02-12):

# BOM: Acoustic Sensor

The acoustic sensor module bill of materials covers the MEMS microphone, low-noise audio
amplifier, anti-aliasing filter network, RS-485 transceiver, and supporting passives. Components
are selected for reliable operation in industrial noise environments. For specifications and
usage guidance, see the [Acoustic Sensor Module](/docs/sensors/acoustic-sensor) documentation.

<div id="bom-acoustic-sensor">Loading BOM...</div>

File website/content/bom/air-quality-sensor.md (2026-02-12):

# BOM: Air Quality Sensor

The air quality sensor module bill of materials covers the metal-oxide gas sensor, particulate
matter detector, temperature and humidity compensation circuitry, RS-485 transceiver, and
supporting passives. Components are selected for continuous ambient air monitoring in factory
environments. For specifications, see the
[Air Quality Sensor Module](/docs/sensors/air-quality-sensor) documentation.

<div id="bom-air-quality-sensor">Loading BOM...</div>

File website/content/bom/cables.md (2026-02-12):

# BOM: Cables and Interconnects

This bill of materials lists the cable assemblies and interconnects used to link the EsoCore Edge
board to its sensor modules. It includes M12 circular connectors, shielded twisted-pair cabling,
Ethernet patch cables, and associated strain reliefs. For wiring diagrams and pinout details,
see the [Edge Hardware](/docs/esocore-edge) documentation for integration details.

<div id="bom-cables">Loading BOM...</div>

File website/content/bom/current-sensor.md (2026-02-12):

# BOM: Current Sensor

The current sensor module bill of materials includes the Hall-effect current transducer, signal
conditioning amplifier, over-voltage protection circuitry, RS-485 transceiver, and supporting
passives. Parts are rated for continuous industrial current monitoring applications. For wiring
and specifications, see the [Current Sensor Module](/docs/sensors/current-sensor) documentation.

<div id="bom-current-sensor">Loading BOM...</div>

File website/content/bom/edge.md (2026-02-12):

# BOM: EsoCore Edge Board

The EsoCore Edge board bill of materials covers all components required to assemble the main
processing unit, including the STM32H7 microcontroller, Ethernet PHYs, RS-485 transceivers,
power regulation circuitry, and board-to-wire connectors. Quantities and reference pricing are
listed below. For board-level documentation and schematics, see the
[Edge Hardware](/docs/esocore-edge) reference.

<div id="bom-main">Loading BOM...</div>

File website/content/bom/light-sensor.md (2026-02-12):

# BOM: Light Sensor

The light sensor module bill of materials includes the ambient light photodiode, transimpedance
amplifier, precision ADC, RS-485 transceiver, and supporting passive components. Parts are rated
for industrial lighting and optical presence detection applications. For specifications, see the
[Light Sensor Module](/docs/sensors/light-sensor) documentation.

<div id="bom-light-sensor">Loading BOM...</div>

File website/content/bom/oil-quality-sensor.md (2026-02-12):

# BOM: Oil Quality Sensor

The oil quality sensor module bill of materials includes the dielectric constant sensing element,
temperature compensation circuitry, precision ADC, RS-485 transceiver, and supporting passives.
Components are chosen for long-term immersion in lubricant and hydraulic fluid environments. For
specifications, see the
[Oil Quality Sensor Module](/docs/sensors/oil-quality-sensor) documentation.

<div id="bom-oil-quality-sensor">Loading BOM...</div>

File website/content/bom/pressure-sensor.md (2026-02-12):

# BOM: Pressure Sensor

The pressure sensor module bill of materials covers the MEMS piezoresistive pressure transducer,
instrumentation amplifier, calibration EEPROM, RS-485 transceiver, and supporting passives.
All components are rated for hydraulic and pneumatic monitoring in industrial environments. For
specifications, see the [Pressure Sensor Module](/docs/sensors/pressure-sensor) documentation.

<div id="bom-pressure-sensor">Loading BOM...</div>

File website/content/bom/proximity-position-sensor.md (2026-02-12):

# BOM: Proximity Position Sensor

The proximity and position sensor module bill of materials covers the inductive sensing coil,
LC oscillator front-end, detection threshold comparator, RS-485 transceiver, and supporting
passives. Components are rated for reliable non-contact position and proximity detection in
industrial machinery. For specifications, see the
[Proximity Position Sensor Module](/docs/sensors/proximity-position-sensor) documentation.

<div id="bom-proximity-position-sensor">Loading BOM...</div>

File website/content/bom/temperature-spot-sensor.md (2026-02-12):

# BOM: Temperature Spot Sensor

The temperature spot sensor module bill of materials includes the infrared thermopile detector,
optical lens assembly, signal conditioning ADC, RS-485 transceiver, and supporting passives.
Components are selected for accurate non-contact surface temperature measurement in industrial
settings. For specifications, see the
[Temperature Spot Sensor Module](/docs/sensors/temperature-spot-sensor) documentation.

<div id="bom-temperature-spot-sensor">Loading BOM...</div>

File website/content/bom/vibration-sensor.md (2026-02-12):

# BOM: Vibration Sensor

The vibration sensor module bill of materials includes the 3-axis MEMS accelerometer, signal
conditioning circuitry, RS-485 transceiver, and supporting passive components. All parts are
industrial-grade and rated for extended temperature ranges. For functional details and
specifications, see the [Vibration Sensor Module](/docs/sensors/vibration-sensor) documentation.

<div id="bom-vibration-sensor">Loading BOM...</div>

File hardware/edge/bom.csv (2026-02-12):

Category | Item | MPN | Supplier | Qty | Unit | Notes | Package
MCU | STM32H747 Dual-core Cortex-M7/M4 LQFP176 | STM32H747IIT6 | ST | 1 | 13.50 | Main MCU (dual-core) | SMD
Wireless | WiFi/BT module ESP32-S3-WROOM-1-N16R8 | ESP32-S3-WROOM-1-N16R8 | Espressif | 1 | 4.50 | WiFi 802.11b/g/n + Bluetooth 5.0 | Module
Wireless | USB VBUS 3.3V LDO for ESP32 | AMS1117-3.3 | AMS | 1 | 0.12 | Powers ESP32 from USB VBUS during programming without main 24V supply | SMD
Wireless | ESP32 auto-programming dual NPN transistor | UMH3N | JSCJ | 1 | 0.03 | DTR/RTS auto-reset circuit for ESP32 UART programming | SMD
Storage | Generic microSD 16GB MLC -40C to 85C | ISD-16GB-MLC | Generic | 1 | 6.80 | Logging and buffering | SMD
Connector | MicroSD push-push holder | DM3AT-SF-PEJM5 | Hirose | 1 | 0.35 | MicroSD socket | SMD
Signal Integrity | SD card EMI filter and ESD protection | EMIF06-MSD02N16 | ST | 1 | 0.45 | Combined EMI filter + ESD on all SDIO lines; QFN-16 | SMD
Power | 24V to 5V buck converter 3A | TPS54331DR | Texas Instruments | 1 | 2.80 | Primary 24V to 5V rail for IEPE current sources and digital logic | SMD
Power | 5V to 3.3V LDO digital rail | TLV1117LV33DCYR | Texas Instruments | 1 | 0.45 | Digital 3.3V rail from 5V | SMD
Power | Low-noise 3.3V LDO for analog section | TPS7A4533DCYR | Texas Instruments | 1 | 1.80 | Dedicated low-noise analog 3.3V rail isolated from digital | SMD
Power | 1.2V LDO for STM32 internal regulator bypass | TLV70212DBVR | Texas Instruments | 1 | 0.35 | STM32H747 VCAP/DSI 1.2V supply; mandatory for dual-core operation | SMD
Power | Input LC filter inductor 47uH | SRN6045-470M | Bourns | 1 | 0.35 | 24V input EMI filtering | SMD
Power | Input filter capacitor 470uF 35V electrolytic | ERG35V470M10X16 | JIERR | 1 | 0.30 | 24V input bulk decoupling; larger cap for industrial transient ride-through | THT
Backup | Supercapacitor 3.8V 20F | SLA3R8L2060813 | Ymin | 1 | 3.50 | 3.8V rated; solves 2.7V overvoltage issue; evaluate adding second unit for 30s runtime target | THT
Backup | Supercap charge current limiting resistor 680 ohm | RC0805FR-07680RL | YAGEO | 1 | 0.01 | Limits inrush current to supercap during charging | SMD
Backup | Schottky diode for supercap charge path | CDBA240LL-HF | Comchip | 1 | 0.08 | Controls charge/discharge path for supercap backup | SMD
Protection | 24V TVS diode SMAJ24A | SMAJ24A | Littelfuse | 2 | 0.09 | Input surge protection | SMD
Protection | Varistor 33V for 24V input surge | ERZ-V14D330 | Panasonic | 1 | 0.18 | MOV for transient voltage clamping on 24V input | SMD
Protection | GPIO ESD protection array 2-ch | SP0502BAHTG | Littelfuse | 4 | 0.06 | Sensor connector protection (+-15kV ESD) | SMD
Protection | Resettable polyfuse 1.1A hold MF-MSMF110 | MF-MSMF110/33X-2 | BOURNS | 1 | 0.10 | Input overcurrent protection | SMD
Signal Integrity | USB 2.0 common-mode choke 90ohm | DLW21SN900SQ2L | TDK | 1 | 0.08 | Reduce USB EMI | SMD
Signal Integrity | USB ESD protection IC | USBULC6-2M6 | ST | 1 | 0.15 | Purpose-built USB D+/D- ESD protection; low capacitance; SON-6 | SMD
Signal Integrity | MCU VDD ferrite bead 120ohm at 100MHz | BLM18PG121SN1D | Murata | 1 | 0.02 | High-frequency noise filtering on MCU power rail | SMD
Connector | USB-C receptacle mid-mount | 632723300021 | Wurth | 1 | 0.35 | USB-C for service | THT
Connector | Power input pluggable PCB mate 2-pin 5.00mm | 2EDGR-5.0-02P | Degson | 1 | 0.12 | 24V DC power input; 90 deg angled PCB edge; mates with 2EDGK-5.0-02P | THT
Connector | Power input pluggable plug 2-pin 5.00mm | 2EDGK-5.0-02P | Degson | 1 | 0.12 | Field-side plug; mates with 2EDGR-5.0-02P | Accessory
IO | SMD Optocoupler for 24V inputs | PC817X2NIP1B | Sharp | 12 | 0.06 | 6 dual-channel safety digital inputs (2 per channel) with 5kV isolation | SMD
IO | SMD Solid State Relay 5V | AQY212EHAZ | Panasonic | 1 | 1.10 | Service indicator or interlock (60V/500mA) | SMD
Clock | 32.768kHz SMD RTC crystal | ABS07-32.768KHZ-T | ABRACON | 1 | 0.12 | Industrial temp range (-40C to 85C) | SMD
Clock | 25MHz active oscillator | OT3EL89CJI-111YLC-25M | YXC | 1 | 0.25 | Shared clock for STM32 + Ethernet PHY(s); active oscillator drives multiple loads; +-25ppm; 2.5x2.0mm | SMD
Ethernet | 10/100 Ethernet PHY (Port A Machine) | KSZ8081RNACA | Microchip | 1 | 2.00 | Industrial PHY (-40C to +85C) for machine network; RMII interface; auto-MDIX | QFN-24
Ethernet | 10/100 Ethernet PHY (Port B IT) | KSZ8081RNACA | Microchip | 1 | 2.00 | Industrial PHY (-40C to +85C) for IT network; RMII interface; auto-MDIX | QFN-24
Ethernet | RJ-45 MagJack with integrated magnetics (Port A) | 7499111121 | Wurth | 1 | 2.50 | Port A machine network; 1:1 transformer with CMC; built-in LEDs | THT
Ethernet | RJ-45 MagJack with integrated magnetics (Port B) | 7499111121 | Wurth | 1 | 2.50 | Port B IT network; 1:1 transformer with CMC; built-in LEDs | THT
Ethernet | TVS diode for Ethernet ESD PESD5V0L1BA | PESD5V0L1BA | Nexperia | 8 | 0.05 | +-30V clamp on each differential pair; 4 per port | SMD
Ethernet | Ferrite bead for Ethernet PHY power 600ohm | FCM1608KF-601T03 | TAI-TECH | 2 | 0.04 | 600 ohm at 100MHz; one per PHY for power filtering; 0603 | SMD
Connector | Sensor bus primary pluggable PCB mate 4-pin 5.00mm | 2EDGR-5.0-04P | Degson | 1 | 0.18 | Main RS-485 sensor bus out; 90 deg angled PCB edge; mates with 2EDGK-5.0-04P | THT
Connector | Sensor bus primary pluggable plug 4-pin 5.00mm | 2EDGK-5.0-04P | Degson | 1 | 0.18 | Field-side plug; mates with 2EDGR-5.0-04P | Accessory
Connector | Sensor bus secondary pluggable PCB mate 4-pin 5.00mm | 2EDGR-5.0-04P | Degson | 1 | 0.18 | Daisy-chain or secondary bus; 90 deg angled PCB edge; mates with 2EDGK-5.0-04P | THT
Connector | Sensor bus secondary pluggable plug 4-pin 5.00mm | 2EDGK-5.0-04P | Degson | 1 | 0.18 | Field-side plug; mates with 2EDGR-5.0-04P | Accessory
Connector | Safety relay output pluggable PCB mate 6-pin 5.00mm | 2EDGR-5.0-06P | Degson | 1 | 0.24 | Safety relay outputs and monitoring; 90 deg angled PCB edge; mates with 2EDGK-5.0-06P | THT
Connector | Safety relay output pluggable plug 6-pin 5.00mm | 2EDGK-5.0-06P | Degson | 1 | 0.24 | Field-side plug; mates with 2EDGR-5.0-06P | Accessory
Connector | Safety digital input pluggable PCB mate 14-pin 5.00mm | 2EDGR-5.0-14P | Degson | 1 | 0.56 | 6 dual-channel safety inputs (12 signal + GND + 24V); 90 deg angled PCB edge; mates with 2EDGK-5.0-14P | THT
Connector | Safety digital input pluggable plug 14-pin 5.00mm | 2EDGK-5.0-14P | Degson | 1 | 0.56 | Field-side plug; mates with 2EDGR-5.0-14P | Accessory
Connector | Analog input pluggable PCB mate 10-pin 5.00mm | 2EDGR-5.0-10P | Degson | 1 | 0.40 | 4 dual-mode analog inputs (IEPE or DC); signal + shield per ch + supply; 90 deg angled PCB edge | THT
Connector | Analog input pluggable plug 10-pin 5.00mm | 2EDGK-5.0-10P | Degson | 1 | 0.40 | Field-side plug for analog inputs | Accessory
Connector | Fieldbus pluggable PCB mate 6-pin 5.00mm | 2EDGR-5.0-06P | Degson | 1 | 0.24 | Modbus RTU PROFIBUS connections; 90 deg angled PCB edge; mates with 2EDGK-5.0-06P | THT
Connector | Fieldbus pluggable plug 6-pin 5.00mm | 2EDGK-5.0-06P | Degson | 1 | 0.24 | Field-side plug; mates with 2EDGR-5.0-06P | Accessory
Connector | Interbus pluggable PCB mate 4-pin 5.00mm | 2EDGR-5.0-04P | Degson | 1 | 0.18 | Interbus RS-485 connection (A/B/GND/Shield); 90 deg angled PCB edge | THT
Connector | Interbus pluggable plug 4-pin 5.00mm | 2EDGK-5.0-04P | Degson | 1 | 0.18 | Field-side plug for Interbus | Accessory
Sensor Bus | RS-485 transceiver for sensor network | SN65HVD72D | Texas Instruments | 1 | 0.85 | Sensor bus interface | SOIC-8
Sensor Bus | 12V power supply for sensor bus 2A | TPS54331DR | Texas Instruments | 1 | 2.40 | Distributed power for sensor modules | SMD
Sensor Bus | Bus termination resistor 120 ohm | ERJ-3EKF1200V | Panasonic | 2 | 0.02 | End-of-line termination | SMD
Programming | Tag-Connect 10-pin SWD footprint for STM32 | TC2050-IDC-NL | Tag-Connect | 0 | 0.00 | DNP; 10-pin needle footprint for STM32 SWD/JTAG debug | SMD
Programming | Tag-Connect 6-pin footprint for ESP32 | TC2030-IDC-NL | Tag-Connect | 0 | 0.00 | DNP; 6-pin needle footprint for ESP32 UART programming | SMD
UI | Tact switch 4.5mm SMD | TS-1187A-B-A-B | XKB | 2 | 0.03 | Reset and boot buttons | SMD
UI | Status LED green 0603 | LTST-C190KGKT | Lite-On | 2 | 0.01 | System status | SMD
UI | 1.5in OLED 128x64 I2C 3.3V | WEO015664A | Winstar | 1 | 4.50 | On-device debug/menu display | SMD
UI | OLED I2C level shifter MOSFET | BSS138LT1G | onsemi | 1 | 0.05 | MOSFET-based bidirectional level shifter for OLED I2C bus | SMD
UI | Menu buttons SMD tact 4.5mm | TS-1187A-B-A-B | XKB | 4 | 0.03 | Up Down Enter Back navigation | SMD
Passives | Resistors and capacitors 0603 assorted | R0603 assortment | Generic | 1 | 0.50 | Estimated per-board passives | SMD
RTC Backup | CR2032 lithium coin cell | CR-2032 | Panasonic | 1 | 0.25 | RTC backup battery | THT
RTC Backup | CR2032 SMD holder | 1060TR | Keystone | 1 | 0.32 | Coin cell holder for VBAT | SMD
RTC Backup | Schottky diode for VBAT isolation | BAT54WS-7-F | Diodes Inc | 1 | 0.03 | Prevents backfeed into coin cell | SMD
Fieldbus | Isolated RS-485 transceiver for Modbus RTU | ADM2582EBRWZ | Analog Devices | 1 | 4.20 | Isolation and integrated DC/DC | SMD
Fieldbus | PROFIBUS-compliant RS-485 transceiver | SN65HVD1176DR | Texas Instruments | 1 | 1.90 | Meets PROFIBUS electrical levels | SMD
Fieldbus | DB-9 male connector with shield for PROFIBUS | DS1037-09FNAKT74-0CC | Connfly | 1 | 1.00 | 90 deg angled THT D-Sub male shielded | THT
Fieldbus | Pluggable PCB mate 3-pin 5.00mm for RS-485 | 2EDGR-5.0-03P | Degson | 1 | 0.16 | A/B/GND screw terminal; 90 deg angled PCB edge; mates with 2EDGK-5.0-03P | THT
Fieldbus | Pluggable plug 3-pin 5.00mm for RS-485 | 2EDGK-5.0-03P | Degson | 1 | 0.16 | Field-side plug; mates with 2EDGR-5.0-03P | Accessory
Fieldbus | 120 ohm termination resistor 0805 | R0805-120R | Generic | 1 | 0.01 | Bus termination selectable | SMD
Fieldbus | 8-position SMD DIP switch | DSHP08TS-S | XKB | 1 | 0.22 | Addressing and termination enable (SMD DIP) | SMD
Interbus | Isolated RS-485 transceiver for Interbus | ADM2582EBRWZ | Analog Devices | 1 | 4.20 | Dedicated Interbus interface with isolation and integrated DC/DC | SMD
Interbus | 120 ohm termination resistor 0805 for Interbus | R0805-120R | Generic | 1 | 0.01 | Interbus bus termination selectable | SMD
Safety | Safety relay dual-channel SPDT | G7SA-2A2B-DC24 | Omron | 1 | 12.50 | EN ISO 13849 PLd safety-rated outputs; single relay provides 2NO+2NC dual-channel | THT
Safety | Relay coil driver with economization | DRV110APWR | Texas Instruments | 1 | 2.80 | Coil current control; contact monitoring via MCU | SMD
Analog | 4-channel 24-bit simultaneous delta-sigma ADC | ADS1274IPAPR | Texas Instruments | 1 | 12.50 | 50 kSPS per channel; SPI interface; simultaneous sampling; -40C to +105C | HTQFP-32
Analog | Programmable gain amplifier | PGA280AIDR | Texas Instruments | 4 | 4.80 | Gain 1/2/5/10/20; SPI/GPIO control; bandwidth >1 MHz; input +-10V | SOIC-16
Analog | Quad low-noise op-amp for buffer and AAF | OPA4188AIDR | Texas Instruments | 2 | 3.20 | 3.3 nV/rtHz noise; unity-gain buffer and 4-pole AAF stages | SOIC-14
Analog | IEPE constant-current source IC | REF200AU | Texas Instruments | 4 | 2.50 | Dual 100 uA source; scale to 4 mA with external resistor | SOIC-8
Analog | P-channel MOSFET for current source enable | Si2301CDS-T1-GE3 | Vishay | 4 | 0.15 | Per-channel IEPE current source enable via GPIO | SOT-23
Analog | DC blocking capacitor 10uF film 50V | ECW-F2106JL | Panasonic | 4 | 0.85 | AC coupling; blocks 8-12V IEPE DC bias; polypropylene film | THT
Analog | Input resistor to ground 100kohm 1% | ERA-3AEB1003V | Panasonic | 4 | 0.08 | Sets AC input impedance and high-pass filter corner | SMD
Analog | AAF resistors 1% metal film assorted | ERA-3AEB assortment | Panasonic | 1 | 0.60 | Anti-aliasing filter passive components (1% tolerance) | SMD
Analog | AAF capacitors C0G/NP0 assorted | GRM15 C0G assortment | Murata | 1 | 0.40 | Anti-aliasing filter capacitors (low-loss NP0/C0G) | SMD
Analog | Series input protection resistor 100ohm 0.25W | ERJ-3EKF1000V | Panasonic | 4 | 0.02 | Limits fault current from sensor cable | SMD
Analog | SPDT analog switch for IEPE/DC mode select | TMUX1101DCR | Texas Instruments | 4 | 0.40 | Per-channel mode switch; 1 ohm Ron; -120 dB THD; SOT-23-6; GPIO controlled | SMD
Analog | TVS diode for analog input ESD | PESD5V0L1BA | Nexperia | 4 | 0.05 | +-30V clamp; fast response for sensor input ESD protection | SMD
Protection | TVS diode array for sensor inputs | SP0503BAHTG | Littelfuse | 3 | 0.12 | Sensor connector protection | SMD
PCB | 4-layer PCB FR4 1.55mm 35um 86x171mm | PCB-4L | Various | 1 | 2.40 | ENIG finish 4-layer; black soldermask; white silkscreen | PCB

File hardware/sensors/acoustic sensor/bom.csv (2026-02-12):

Category | Item | MPN | Supplier | Qty | Unit | Notes | Package
MCU | STM32G031 ARM Cortex-M0+ 32MHz TSSOP20 | STM32G031K8T6 | ST | 1 | 1.80 | Local processing FFT and bus communication | SMD
Sensor | Digital MEMS microphone ICS-43434 | ICS-43434 | TDK InvenSense | 1 | 3.20 | Wide-band digital output 50Hz-20kHz ±3dB | SMD
Sensor | Ultrasound transducer MA40S4R | MA40S4R | Murata | 1 | 4.50 | Ultrasonic frequency response 40±1kHz | THT
Communication | RS-485 transceiver half-duplex | SN65HVD72D | Texas Instruments | 1 | 0.85 | Bus interface for digital communication | SMD
Power | Buck converter 12V to 3.3V 500mA | TPS62172DSGT | Texas Instruments | 1 | 1.45 | Efficient power from bus | SMD
Power | LDO 3.3V clean for analog | MCP1700T-3302E/TT | Microchip | 1 | 0.12 | Clean power for sensitive analog | SMD
Connector | RS-485 IN pluggable PCB mate 4-pin 5.00mm | 2EDGR-5.0-04P | Degson | 1 | 0.18 | IN: A/B/12V/GND; mates with 2EDGK-5.0-04P; loop-through | THT
Connector | RS-485 IN pluggable plug 4-pin 5.00mm | 2EDGK-5.0-04P | Degson | 1 | 0.18 | Field-side plug for IN; A/B/12V/GND | Accessory
Connector | RS-485 OUT pluggable PCB mate 4-pin 5.00mm | 2EDGR-5.0-04P | Degson | 1 | 0.18 | OUT: A/B/12V/GND; mates with 2EDGK-5.0-04P; loop-through | THT
Connector | RS-485 OUT pluggable plug 4-pin 5.00mm | 2EDGK-5.0-04P | Degson | 1 | 0.18 | Field-side plug for OUT; A/B/12V/GND | Accessory
Connector | Cable gland PG9 for 4-conductor cable | PG9-GLAND | Wiska | 1 | 1.50 | Strain relief and environmental sealing | THT
Protection | ESD protection diode array 4-ch | SP0503BAHTG | Littelfuse | 1 | 0.08 | Bus and power line protection | SMD
Fieldbus | Termination resistor 120 ohm 0805 | R0805-120R | Generic | 1 | 0.01 | RS-485 line termination switched by DIP 8 | SMD
Clock | 8MHz crystal for MCU | ABMM2-8.000MHZ-E2-T | ABRACON | 1 | 0.12 | MCU external clock source | SMD
Addressing | 8-position SMD DIP switch | DSHP08TS-S | XKB | 1 | 0.22 | 1-7=Modbus addr; 8=120Ω termination enable; silkscreen: 1-7=ADDR | 8=TERM | ON/OFF | SMD
Status | Status LED green 0603 | LTST-C190KGKT | Lite-On | 1 | 0.01 | Operational status indication | SMD
Passives | Resistors and capacitors 0603 assorted | R0603 assortment | Generic | 1 | 0.25 | Bus termination bias network filter caps | SMD
Mechanical | Industrial magnetic mount base | MM-BASE-20 | Generic | 1 | 2.50 | Flexible positioning on metal surfaces | Mechanical
PCB | 2-layer PCB FR4 1.55mm 40x30mm | PCB-2L-MEDIUM | Various | 1 | 0.80 | Acoustic sensor module with DSP | PCB
Enclosure | Custom enclosure (IP54 with acoustic port) | CUSTOM | Custom | 1 | 4.80 | Custom enclosure; equivalent spec to AS-ENC-01 | Mechanical
Programming | Tag-Connect SWD footprint (TC2050 or TC2030) | TC2050/TC2030 | Tag-Connect | 0 | 0.00 | DNP; ensure footprint on PCB for SWD | SMD

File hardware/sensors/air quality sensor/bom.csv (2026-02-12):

Category | Item | MPN | Supplier | Qty | Unit | Notes | Package
MCU | STM32G031 ARM Cortex-M0+ 32MHz TSSOP20 | STM32G031K8T6 | ST | 1 | 1.80 | Local air quality processing and bus communication | SMD
Sensor | Air Quality Sensor BME680 | BME680 | Bosch Sensortec | 1 | 8.50 | Temperature | humidity | pressure | VOC | IAQ index | SMD
Sensor | Particulate Matter Sensor PMS5003 | PMS5003 | Plantower | 1 | 12.80 | PM2.5 | PM10 | particle count and size distribution | SMD
Sensor | CO2 Sensor SCD40 | SCD40 | Sensirion | 1 | 15.60 | NDIR CO2 sensor with automatic self-calibration | SMD
Communication | RS-485 transceiver half-duplex | SN65HVD72D | Texas Instruments | 1 | 0.85 | Bus interface for digital communication | SMD
Power | Buck converter 12V to 5V 1A | TPS62173DSGT | Texas Instruments | 1 | 1.65 | Power for particulate sensor (needs 5V) | SMD
Power | LDO 5V to 3.3V 500mA | MCP1700T-3302E/TT | Microchip | 1 | 0.12 | Clean 3.3V for MCU and air quality sensors | SMD
Connector | RS-485 IN pluggable PCB mate 4-pin 5.00mm | 2EDGR-5.0-04P | Degson | 1 | 0.18 | IN: A/B/12V/GND; mates with 2EDGK-5.0-04P; loop-through | THT
Connector | RS-485 IN pluggable plug 4-pin 5.00mm | 2EDGK-5.0-04P | Degson | 1 | 0.18 | Field-side plug for IN; A/B/12V/GND | Accessory
Connector | RS-485 OUT pluggable PCB mate 4-pin 5.00mm | 2EDGR-5.0-04P | Degson | 1 | 0.18 | OUT: A/B/12V/GND; mates with 2EDGK-5.0-04P; loop-through | THT
Connector | RS-485 OUT pluggable plug 4-pin 5.00mm | 2EDGK-5.0-04P | Degson | 1 | 0.18 | Field-side plug for OUT; A/B/12V/GND | Accessory
Connector | Cable gland PG9 for 4-conductor cable | PG9-GLAND | Wiska | 1 | 1.50 | Strain relief and environmental sealing | THT
Protection | ESD protection diode array 4-ch | SP0503BAHTG | Littelfuse | 1 | 0.08 | Bus and power line protection | SMD
Fieldbus | Termination resistor 120 ohm 0805 | R0805-120R | Generic | 1 | 0.01 | RS-485 line termination switched by DIP 8 | SMD
Clock | 8MHz crystal for MCU | ABMM2-8.000MHZ-E2-T | ABRACON | 1 | 0.12 | MCU external clock source | SMD
Addressing | 8-position SMD DIP switch | DSHP08TS-S | XKB | 1 | 0.22 | 1-7=Modbus addr; 8=120Ω termination enable; silkscreen: 1-7=ADDR | 8=TERM | ON/OFF | SMD
Status | Status LED green 0603 | LTST-C190KGKT | Lite-On | 1 | 0.01 | Operational status indication | SMD
Passives | Resistors and capacitors 0603 assorted | R0603 assortment | Generic | 1 | 0.30 | Bus termination | filter | and bias network | SMD
Mechanical | Air intake filter mesh 1mm | SS-MESH-1MM | Generic | 1 | 0.50 | Protection for particulate sensor | Mechanical
Mechanical | Silicone adhesive for sensors | RTV-108 | Dow Corning | 0.1 | 0.05 | Sensor mounting and sealing | Mechanical
PCB | 4-layer PCB FR4 1.55mm 60x40mm | PCB-4L-MEDIUM | Various | 1 | 1.20 | Air quality sensor module with multiple sensors | PCB
Enclosure | Custom enclosure (IP54 with air vents) | CUSTOM | Custom | 1 | 6.80 | Custom enclosure; equivalent spec to AQ-ENC-01 | Mechanical
Programming | Tag-Connect SWD footprint (TC2050 or TC2030) | TC2050/TC2030 | Tag-Connect | 0 | 0.00 | DNP; ensure footprint on PCB for SWD | SMD

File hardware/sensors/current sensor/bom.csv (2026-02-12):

Category | Item | MPN | Supplier | Qty | Unit | Notes | Package
MCU | STM32G031 ARM Cortex-M0+ 32MHz TSSOP20 | STM32G031K8T6 | ST | 1 | 1.80 | Power analysis and bus communication | SMD
Sensor | Isolated Hall current sensor ±30A | ACS723LLCTR-30AB | Allegro | 1 | 4.20 | Higher current range with better linearity | SMD
Communication | RS-485 transceiver isolated | ADM2582EBRWZ | Analog Devices | 1 | 4.20 | Isolated bus interface for safety | SMD
Power | Isolated DC-DC 12V to 5V 1W | NXE1S1205MC | Murata | 1 | 9.20 | Primary isolation for safety | SMD
Power | LDO 5V to 3.3V | MCP1700T-3302E/TT | Microchip | 1 | 0.12 | MCU power supply | SMD
Connector | RS-485 IN pluggable PCB mate 4-pin 5.00mm | 2EDGR-5.0-04P | Degson | 1 | 0.18 | IN: A/B/12V/GND; mates with 2EDGK-5.0-04P; loop-through | THT
Connector | RS-485 IN pluggable plug 4-pin 5.00mm | 2EDGK-5.0-04P | Degson | 1 | 0.18 | Field-side plug for IN; A/B/12V/GND | Accessory
Connector | RS-485 OUT pluggable PCB mate 4-pin 5.00mm | 2EDGR-5.0-04P | Degson | 1 | 0.18 | OUT: A/B/12V/GND; mates with 2EDGK-5.0-04P; loop-through | THT
Connector | RS-485 OUT pluggable plug 4-pin 5.00mm | 2EDGK-5.0-04P | Degson | 1 | 0.18 | Field-side plug for OUT; A/B/12V/GND | Accessory
Connector | Cable gland PG9 for 4-conductor cable | PG9-GLAND | Wiska | 1 | 1.50 | Strain relief and environmental sealing | THT
Connector | Motor cable clamp-on 20A | CT-20A-CLAMP | Generic | 1 | 15.50 | Non-invasive installation on motor cable | Mechanical
Protection | Surge suppressor for power lines | GDT-230-3R | Bourns | 1 | 0.45 | Protection from motor switching spikes | SMD
Fieldbus | Termination resistor 120 ohm 0805 | R0805-120R | Generic | 1 | 0.01 | RS-485 line termination switched by DIP 8 | SMD
Clock | 8MHz crystal for MCU | ABMM2-8.000MHZ-E2-T | ABRACON | 1 | 0.12 | MCU external clock source | SMD
Addressing | 8-position SMD DIP switch | DSHP08TS-S | XKB | 1 | 0.22 | 1-7=Modbus addr; 8=120Ω termination enable; silkscreen: 1-7=ADDR | 8=TERM | ON/OFF | SMD
Status | Status LED green 0603 | LTST-C190KGKT | Lite-On | 1 | 0.01 | Operational status indication | SMD
Passives | Resistors and capacitors 0603 assorted | R0603 assortment | Generic | 1 | 0.20 | Filter bias and bypass components | SMD
Mechanical | DIN rail mount bracket | DIN-35-BRACKET | Phoenix Contact | 1 | 1.20 | Standard industrial mounting | Mechanical
PCB | 2-layer PCB FR4 1.55mm 50x35mm | PCB-2L-MEDIUM | Various | 1 | 0.90 | Current sensor module with isolation | PCB
Enclosure | Custom enclosure (DIN rail IP54 45x80x58mm) | CUSTOM | Custom | 1 | 8.90 | Custom enclosure; equivalent spec to Phoenix 1201161 | Mechanical
Programming | Tag-Connect SWD footprint (TC2050 or TC2030) | TC2050/TC2030 | Tag-Connect | 0 | 0.00 | DNP; ensure footprint on PCB for SWD | SMD

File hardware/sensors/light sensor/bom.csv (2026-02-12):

Category | Item | MPN | Supplier | Qty | Unit | Notes | Package
MCU | STM32G031 ARM Cortex-M0+ 32MHz TSSOP20 | STM32G031K8T6 | ST | 1 | 1.80 | Local light intensity processing and bus communication | SMD
Sensor | Visible Light Sensor TSL2591 | TSL2591 | Adafruit/AMS | 1 | 4.20 | High dynamic range visible light sensor (0.002-32k lux) | SMD
Sensor | UV Light Sensor VEML6075 | VEML6075 | Vishay | 1 | 3.80 | UVA/UVB light sensor for UV exposure monitoring | SMD
Sensor | IR Light Sensor MLX90614 | MLX90614 | Melexis | 1 | 8.90 | Infrared temperature sensor for non-contact measurement | SMD
Sensor | Color Light Sensor TCS34725 | TCS34725 | Adafruit/AMS | 1 | 5.50 | RGB color light sensor with IR blocking filter | SMD
Sensor | Spectral Light Sensor AS7341 | AS7341 | AMS | 1 | 12.90 | 10-channel spectral sensor (380-1000nm) | SMD
Communication | RS-485 transceiver half-duplex | SN65HVD72D | Texas Instruments | 1 | 0.85 | Bus interface for digital communication | SMD
Power | Buck converter 12V to 3.3V 500mA | TPS62172DSGT | Texas Instruments | 1 | 1.45 | Efficient power from bus | SMD
Power | LDO 3.3V clean for analog | MCP1700T-3302E/TT | Microchip | 1 | 0.12 | Clean 3.3V for light sensors | SMD
Connector | RS-485 IN pluggable PCB mate 4-pin 5.00mm | 2EDGR-5.0-04P | Degson | 1 | 0.18 | IN: A/B/12V/GND; mates with 2EDGK-5.0-04P; loop-through | THT
Connector | RS-485 IN pluggable plug 4-pin 5.00mm | 2EDGK-5.0-04P | Degson | 1 | 0.18 | Field-side plug for IN; A/B/12V/GND | Accessory
Connector | RS-485 OUT pluggable PCB mate 4-pin 5.00mm | 2EDGR-5.0-04P | Degson | 1 | 0.18 | OUT: A/B/12V/GND; mates with 2EDGK-5.0-04P; loop-through | THT
Connector | RS-485 OUT pluggable plug 4-pin 5.00mm | 2EDGK-5.0-04P | Degson | 1 | 0.18 | Field-side plug for OUT; A/B/12V/GND | Accessory
Connector | Cable gland PG9 for 4-conductor cable | PG9-GLAND | Wiska | 1 | 1.50 | Strain relief and environmental sealing | THT
Protection | ESD protection diode array 4-ch | SP0503BAHTG | Littelfuse | 1 | 0.08 | Bus and power line protection | SMD
Fieldbus | Termination resistor 120 ohm 0805 | R0805-120R | Generic | 1 | 0.01 | RS-485 line termination switched by DIP 8 | SMD
Clock | 8MHz crystal for MCU | ABMM2-8.000MHZ-E2-T | ABRACON | 1 | 0.12 | MCU external clock source | SMD
Addressing | 8-position SMD DIP switch | DSHP08TS-S | XKB | 1 | 0.22 | 1-7=Modbus addr; 8=120Ω termination enable; silkscreen: 1-7=ADDR | 8=TERM | ON/OFF | SMD
Status | Status LED green 0603 | LTST-C190KGKT | Lite-On | 1 | 0.01 | Operational status indication | SMD
Passives | Resistors and capacitors 0603 assorted | R0603 assortment | Generic | 1 | 0.25 | Bus termination filter and bias network | SMD
Mechanical | Light diffuser lens assembly | LIGHT-DIFFUSER | Generic | 1 | 3.50 | Optical diffuser for uniform light measurement | Mechanical
Mechanical | Sensor mounting bracket | LIGHT-BRACKET | Generic | 1 | 2.20 | Adjustable mounting for optimal light sensing | Mechanical
PCB | 2-layer PCB FR4 1.55mm 45x35mm | PCB-2L-SMALL | Various | 1 | 0.90 | Light sensor module with optical components | PCB
Enclosure | Custom enclosure (IP65 with light ports) | CUSTOM | Custom | 1 | 7.20 | Custom enclosure; equivalent spec to LIGHT-ENC-01 | Mechanical
Programming | Tag-Connect SWD footprint (TC2050 or TC2030) | TC2050/TC2030 | Tag-Connect | 0 | 0.00 | DNP; ensure footprint on PCB for SWD | SMD

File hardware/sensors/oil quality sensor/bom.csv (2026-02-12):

Category | Item | MPN | Supplier | Qty | Unit | Notes | Package
MCU | STM32G031 ARM Cortex-M0+ 32MHz TSSOP20 | STM32G031K8T6 | ST | 1 | 1.80 | Local oil quality processing and bus communication | SMD
Sensor | Turbidity sensor for oil contamination | TS-300-OIL-TURBIDITY | Generic | 1 | 15.50 | Turbidity measurement for contamination detection | SMD
Sensor | Oil temperature sensor DS18B20 | DS18B20 | Maxim Integrated | 1 | 2.50 | Oil temperature monitoring for thermal degradation | SMD
Sensor | Viscosity sensor piezoelectric | PV-100-VISCOSITY | Generic | 1 | 25.80 | Piezoelectric viscosity measurement for oil degradation | SMD
Sensor | Water content sensor capacitive | CAP-100-WATER | Generic | 1 | 18.90 | Capacitive water content detection in oil | SMD
Sensor | Dielectric constant sensor | DIELECTRIC-100 | Generic | 1 | 22.50 | Dielectric constant measurement for oil condition | SMD
Communication | RS-485 transceiver isolated | ADM2582EBRWZ | Analog Devices | 1 | 4.20 | Isolated bus interface for industrial safety | SMD
Power | Isolated DC-DC 12V to 5V 1W | NXE1S1205MC | Murata | 1 | 9.20 | Primary isolation for safety with oil sensors | SMD
Power | LDO 5V to 3.3V | MCP1700T-3302E/TT | Microchip | 1 | 0.12 | MCU power supply | SMD
Connector | RS-485 IN pluggable PCB mate 4-pin 5.00mm | 2EDGR-5.0-04P | Degson | 1 | 0.18 | IN: A/B/12V/GND; mates with 2EDGK-5.0-04P; loop-through | THT
Connector | RS-485 IN pluggable plug 4-pin 5.00mm | 2EDGK-5.0-04P | Degson | 1 | 0.18 | Field-side plug for IN; A/B/12V/GND | Accessory
Connector | RS-485 OUT pluggable PCB mate 4-pin 5.00mm | 2EDGR-5.0-04P | Degson | 1 | 0.18 | OUT: A/B/12V/GND; mates with 2EDGK-5.0-04P; loop-through | THT
Connector | RS-485 OUT pluggable plug 4-pin 5.00mm | 2EDGK-5.0-04P | Degson | 1 | 0.18 | Field-side plug for OUT; A/B/12V/GND | Accessory
Connector | Cable gland PG9 for 4-conductor cable | PG9-GLAND | Wiska | 1 | 1.50 | Strain relief and environmental sealing | THT
Connector | Oil sampling port G1/8 BSP | OIL-SAMPLING-PORT | Generic | 1 | 4.50 | Threaded port for oil extraction and measurement | THT
Protection | Surge suppressor for power lines | GDT-230-3R | Bourns | 1 | 0.45 | Protection from industrial electrical surges | SMD
Fieldbus | Termination resistor 120 ohm 0805 | R0805-120R | Generic | 1 | 0.01 | RS-485 line termination switched by DIP 8 | SMD
Clock | 8MHz crystal for MCU | ABMM2-8.000MHZ-E2-T | ABRACON | 1 | 0.12 | MCU external clock source | SMD
Addressing | 8-position SMD DIP switch | DSHP08TS-S | XKB | 1 | 0.22 | 1-7=Modbus addr; 8=120Ω termination enable; silkscreen: 1-7=ADDR | 8=TERM | ON/OFF | SMD
Status | Status LED green 0603 | LTST-C190KGKT | Lite-On | 1 | 0.01 | Operational status indication | SMD
Passives | Resistors and capacitors 0603 assorted | R0603 assortment | Generic | 1 | 0.30 | Filter bias and bypass components | SMD
Mechanical | Oil filter mesh 50 micron | OIL-FILTER-MESH | Generic | 1 | 3.20 | Protection for sensors from large particles | Mechanical
Mechanical | Silicone oil-resistant gasket | OIL-GASKET-SILICONE | Generic | 1 | 1.80 | Sealing for oil sampling port | Mechanical
PCB | 2-layer PCB FR4 1.55mm 60x45mm | PCB-2L-LARGE | Various | 1 | 1.10 | Oil quality sensor module with multiple sensors | PCB
Enclosure | Custom enclosure (IP67 oil-resistant) | CUSTOM | Custom | 1 | 18.90 | Custom enclosure; equivalent spec to OIL-ENC-01 | Mechanical
Programming | Tag-Connect SWD footprint (TC2050 or TC2030) | TC2050/TC2030 | Tag-Connect | 0 | 0.00 | DNP; ensure footprint on PCB for SWD | SMD

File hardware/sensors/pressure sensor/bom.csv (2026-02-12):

Category | Item | MPN | Supplier | Qty | Unit | Notes | Package
MCU | STM32G031 ARM Cortex-M0+ 32MHz TSSOP20 | STM32G031K8T6 | ST | 1 | 1.80 | Local pressure processing and bus communication | SMD
Sensor | Pressure Sensor 0-10bar gauge I2C | MPRLS0300YG00001BB | Honeywell | 1 | 12.50 | Gauge pressure for hydraulic/pneumatic systems (300 PSI / 20.7 bar full scale) | SMD
Sensor | Pressure Sensor barometric 300-1250hPa | BMP388 | Bosch Sensortec | 1 | 2.80 | Barometric/ambient pressure monitoring (0.3-1.25 bar absolute) | SMD
Sensor | Pressure Sensor barometric 300-1100hPa | BMP280 | Bosch Sensortec | 1 | 2.20 | Low-range barometric pressure and altitude (0.3-1.1 bar absolute) | SMD
Communication | RS-485 transceiver half-duplex | SN65HVD72D | Texas Instruments | 1 | 0.85 | Bus interface for digital communication | SMD
Power | Buck converter 12V to 3.3V 500mA | TPS62172DSGT | Texas Instruments | 1 | 1.45 | Efficient power from bus | SMD
Power | LDO 3.3V clean for analog | MCP1700T-3302E/TT | Microchip | 1 | 0.12 | Clean power for pressure sensors | SMD
Connector | RS-485 IN pluggable PCB mate 4-pin 5.00mm | 2EDGR-5.0-04P | Degson | 1 | 0.18 | IN: A/B/12V/GND; mates with 2EDGK-5.0-04P; loop-through | THT
Connector | RS-485 IN pluggable plug 4-pin 5.00mm | 2EDGK-5.0-04P | Degson | 1 | 0.18 | Field-side plug for IN; A/B/12V/GND | Accessory
Connector | RS-485 OUT pluggable PCB mate 4-pin 5.00mm | 2EDGR-5.0-04P | Degson | 1 | 0.18 | OUT: A/B/12V/GND; mates with 2EDGK-5.0-04P; loop-through | THT
Connector | RS-485 OUT pluggable plug 4-pin 5.00mm | 2EDGK-5.0-04P | Degson | 1 | 0.18 | Field-side plug for OUT; A/B/12V/GND | Accessory
Connector | Cable gland PG9 for 4-conductor cable | PG9-GLAND | Wiska | 1 | 1.50 | Strain relief and environmental sealing | THT
Connector | Pressure fittings G1/4 BSP | M12-PRESSURE-FITTING | Generic | 2 | 3.50 | Hydraulic/pneumatic pressure ports | THT
Protection | ESD protection diode array 4-ch | SP0503BAHTG | Littelfuse | 1 | 0.08 | Bus and power line protection | SMD
Fieldbus | Termination resistor 120 ohm 0805 | R0805-120R | Generic | 1 | 0.01 | RS-485 line termination switched by DIP 8 | SMD
Clock | 8MHz crystal for MCU | ABMM2-8.000MHZ-E2-T | ABRACON | 1 | 0.12 | MCU external clock source | SMD
Addressing | 8-position SMD DIP switch | DSHP08TS-S | XKB | 1 | 0.22 | 1-7=Modbus addr; 8=120Ω termination enable; silkscreen: 1-7=ADDR | 8=TERM | ON/OFF | SMD
Status | Status LED green 0603 | LTST-C190KGKT | Lite-On | 1 | 0.01 | Operational status indication | SMD
Passives | Resistors and capacitors 0603 assorted | R0603 assortment | Generic | 1 | 0.25 | Bus termination filter and bias network | SMD
Mechanical | Pressure relief valve 100bar | RELIEF-VALVE-100BAR | Generic | 1 | 8.50 | Safety relief for overpressure protection | Mechanical
PCB | 2-layer PCB FR4 1.55mm 50x40mm | PCB-2L-MEDIUM | Various | 1 | 0.85 | Pressure sensor module with multiple ranges | PCB
Enclosure | Custom enclosure (IP67 pressure-rated) | CUSTOM | Custom | 1 | 12.50 | Custom enclosure; equivalent spec to PRESSURE-ENC-01 | Mechanical
Programming | Tag-Connect SWD footprint (TC2050 or TC2030) | TC2050/TC2030 | Tag-Connect | 0 | 0.00 | DNP; ensure footprint on PCB for SWD | SMD

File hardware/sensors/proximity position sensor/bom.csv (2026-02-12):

Category | Item | MPN | Supplier | Qty | Unit | Notes | Package
MCU | STM32G031 ARM Cortex-M0+ 32MHz TSSOP20 | STM32G031K8T6 | ST | 1 | 1.80 | Local position processing and bus communication | SMD
Sensor | Inductive proximity sensor LJ12A3-4-Z/BX | INDUCTIVE-12MM | Generic | 2 | 4.50 | 12mm sensing distance for metal detection | SMD
Sensor | Capacitive proximity sensor LJ18A3-8-Z/BX | CAPACITIVE-18MM | Generic | 1 | 5.20 | 18mm sensing distance for non-metal detection | SMD
Sensor | Optical encoder quadrature 1000PPR | ENCODER-1000PPR | Generic | 1 | 12.80 | High-resolution position and speed measurement | SMD
Sensor | Magnetic proximity sensor reed switch | REED-SWITCH-10MM | Generic | 2 | 2.10 | Magnetic field detection for position sensing | SMD
Sensor | Laser distance sensor VL53L0X | VL53L0X | ST | 1 | 6.90 | Laser ranging up to 2m for precision positioning | SMD
Communication | RS-485 transceiver half-duplex | SN65HVD72D | Texas Instruments | 1 | 0.85 | Bus interface for digital communication | SMD
Power | Buck converter 12V to 3.3V 500mA | TPS62172DSGT | Texas Instruments | 1 | 1.45 | Efficient power from bus | SMD
Power | LDO 3.3V clean for analog | MCP1700T-3302E/TT | Microchip | 1 | 0.12 | Clean power for sensors | SMD
Connector | RS-485 IN pluggable PCB mate 4-pin 5.00mm | 2EDGR-5.0-04P | Degson | 1 | 0.18 | IN: A/B/12V/GND; mates with 2EDGK-5.0-04P; loop-through | THT
Connector | RS-485 IN pluggable plug 4-pin 5.00mm | 2EDGK-5.0-04P | Degson | 1 | 0.18 | Field-side plug for IN; A/B/12V/GND | Accessory
Connector | RS-485 OUT pluggable PCB mate 4-pin 5.00mm | 2EDGR-5.0-04P | Degson | 1 | 0.18 | OUT: A/B/12V/GND; mates with 2EDGK-5.0-04P; loop-through | THT
Connector | RS-485 OUT pluggable plug 4-pin 5.00mm | 2EDGK-5.0-04P | Degson | 1 | 0.18 | Field-side plug for OUT; A/B/12V/GND | Accessory
Connector | Cable gland PG9 for 4-conductor cable | PG9-GLAND | Wiska | 1 | 1.50 | Strain relief and environmental sealing | THT
Connector | M12 connector for proximity sensors | M12-4PIN-FEMALE | Generic | 3 | 2.40 | Industrial connectors for proximity sensors | THT
Connector | Encoder connector 8-pin | ENCODER-CONN-8PIN | Generic | 1 | 3.80 | Differential encoder signal connector | THT
Protection | ESD protection diode array 4-ch | SP0503BAHTG | Littelfuse | 1 | 0.08 | Bus and power line protection | SMD
Fieldbus | Termination resistor 120 ohm 0805 | R0805-120R | Generic | 1 | 0.01 | RS-485 line termination switched by DIP 8 | SMD
Clock | 8MHz crystal for MCU | ABMM2-8.000MHZ-E2-T | ABRACON | 1 | 0.12 | MCU external clock source | SMD
Addressing | 8-position SMD DIP switch | DSHP08TS-S | XKB | 1 | 0.22 | 1-7=Modbus addr; 8=120Ω termination enable; silkscreen: 1-7=ADDR | 8=TERM | ON/OFF | SMD
Status | Status LED green 0603 | LTST-C190KGKT | Lite-On | 1 | 0.01 | Operational status indication | SMD
Passives | Resistors and capacitors 0603 assorted | R0603 assortment | Generic | 1 | 0.30 | Bus termination filter and bias network | SMD
Mechanical | Proximity sensor mounting bracket | MOUNT-BRACKET-M12 | Generic | 3 | 1.50 | Adjustable mounting for different sensor types | Mechanical
Mechanical | Encoder mounting hub 8mm shaft | ENCODER-HUB-8MM | Generic | 1 | 4.20 | Flexible coupling for encoder installation | Mechanical
PCB | 2-layer PCB FR4 1.55mm 55x40mm | PCB-2L-MEDIUM | Various | 1 | 0.95 | Proximity sensor module with multiple sensor interfaces | PCB
Enclosure | Custom enclosure (IP67 industrial) | CUSTOM | Custom | 1 | 10.50 | Custom enclosure; equivalent spec to PROX-ENC-01 | Mechanical
Programming | Tag-Connect SWD footprint (TC2050 or TC2030) | TC2050/TC2030 | Tag-Connect | 0 | 0.00 | DNP; ensure footprint on PCB for SWD | SMD

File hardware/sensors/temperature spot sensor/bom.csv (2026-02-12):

Category | Item | MPN | Supplier | Qty | Unit | Notes | Package
MCU | STM32G031 ARM Cortex-M0+ 32MHz TSSOP20 | STM32G031K8T6 | ST | 1 | 1.80 | Local temperature processing and bus communication | SMD
Sensor | High-temperature NTC thermistor 10kΩ | NTCLE100E3103JB0 | Vishay | 4 | 0.45 | High-temp NTC for motor bearings and hot spots | SMD
Sensor | PT100 RTD temperature sensor | PT100-CLASS-A | Generic | 2 | 3.20 | Precision RTD for accurate temperature measurement | SMD
Sensor | TCouple Type K amplifier AD8495 | AD8495 | Analog Devices | 2 | 4.50 | Thermocouple amplifier for extreme temperatures | SMD
Sensor | Infrared temperature sensor MLX90614 | MLX90614 | Melexis | 1 | 8.90 | Non-contact IR temperature measurement | SMD
ADC | 16-bit ADC ADS1115 for thermocouples | ADS1115IDGSR | Texas Instruments | 1 | 2.40 | High-precision ADC for temperature measurements | SMD
Communication | RS-485 transceiver half-duplex | SN65HVD72D | Texas Instruments | 1 | 0.85 | Bus interface for digital communication | SMD
Power | Buck converter 12V to 3.3V 500mA | TPS62172DSGT | Texas Instruments | 1 | 1.45 | Efficient power from bus | SMD
Power | LDO 3.3V clean for analog | MCP1700T-3302E/TT | Microchip | 1 | 0.12 | Clean power for temperature sensors | SMD
Connector | RS-485 IN pluggable PCB mate 4-pin 5.00mm | 2EDGR-5.0-04P | Degson | 1 | 0.18 | IN: A/B/12V/GND; mates with 2EDGK-5.0-04P; loop-through | THT
Connector | RS-485 IN pluggable plug 4-pin 5.00mm | 2EDGK-5.0-04P | Degson | 1 | 0.18 | Field-side plug for IN; A/B/12V/GND | Accessory
Connector | RS-485 OUT pluggable PCB mate 4-pin 5.00mm | 2EDGR-5.0-04P | Degson | 1 | 0.18 | OUT: A/B/12V/GND; mates with 2EDGK-5.0-04P; loop-through | THT
Connector | RS-485 OUT pluggable plug 4-pin 5.00mm | 2EDGK-5.0-04P | Degson | 1 | 0.18 | Field-side plug for OUT; A/B/12V/GND | Accessory
Connector | Cable gland PG9 for 4-conductor cable | PG9-GLAND | Wiska | 1 | 1.50 | Strain relief and environmental sealing | THT
Connector | High-temp thermocouple connector | THERMO-COAX-CONN | Generic | 2 | 1.80 | Mineral insulated thermocouple connectors | THT
Protection | ESD protection diode array 4-ch | SP0503BAHTG | Littelfuse | 1 | 0.08 | Bus and power line protection | SMD
Fieldbus | Termination resistor 120 ohm 0805 | R0805-120R | Generic | 1 | 0.01 | RS-485 line termination switched by DIP 8 | SMD
Clock | 8MHz crystal for MCU | ABMM2-8.000MHZ-E2-T | ABRACON | 1 | 0.12 | MCU external clock source | SMD
Addressing | 8-position SMD DIP switch | DSHP08TS-S | XKB | 1 | 0.22 | 1-7=Modbus addr; 8=120Ω termination enable; silkscreen: 1-7=ADDR | 8=TERM | ON/OFF | SMD
Status | Status LED green 0603 | LTST-C190KGKT | Lite-On | 1 | 0.01 | Operational status indication | SMD
Passives | Precision resistor for NTC bias 0.1% | ERA-3AEB1002V | Panasonic | 4 | 0.08 | Temperature measurement accuracy | SMD
Passives | Resistors and capacitors 0603 assorted | R0603 assortment | Generic | 1 | 0.35 | Bus termination filter and bias network | SMD
Mechanical | High-temperature adhesive RTV-108 | RTV-108 | Dow Corning | 0.1 | 0.05 | Sensor bonding to hot surfaces | Mechanical
Mechanical | Kapton tape high-temp 25mm | KAPTON-25MM-1M | 3M | 0.1 | 0.08 | Insulation and protection for high-temp installations | Mechanical
PCB | 2-layer PCB FR4 1.55mm 50x35mm | PCB-2L-MEDIUM | Various | 1 | 0.85 | Temperature sensor module with multiple sensor types | PCB
Enclosure | Custom enclosure (high-temp protection sleeve) | CUSTOM | Custom | 1 | 8.50 | Custom enclosure; equivalent spec to TEMP-SPOT-ENC-01 | Mechanical
Programming | Tag-Connect SWD footprint (TC2050 or TC2030) | TC2050/TC2030 | Tag-Connect | 0 | 0.00 | DNP; ensure footprint on PCB for SWD | SMD

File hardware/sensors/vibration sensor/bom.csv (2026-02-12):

Category | Item | MPN | Supplier | Qty | Unit | Notes | Package
MCU | STM32G071 ARM Cortex-M0+ 64MHz TSSOP20 | STM32G071KBT6 | ST | 1 | 2.20 | Enhanced DSP capabilities for FFT processing | SMD
Sensor | 3-axis accelerometer MEMS | ADXL355BCCZ | Analog Devices | 1 | 4.50 | ≥1-3kHz ODR for bearing/mechanical health | SMD
Communication | RS-485 transceiver half-duplex | SN65HVD72D | Texas Instruments | 1 | 0.85 | Bus interface for digital communication | SMD
Power | Buck converter 12V to 3.3V 500mA | TPS62172DSGT | Texas Instruments | 1 | 1.45 | Efficient power from bus | SMD
Power | LDO 3.3V clean for analog | MCP1700T-3302E/TT | Microchip | 1 | 0.12 | Clean power for sensor | SMD
Connector | RS-485 IN pluggable PCB mate 4-pin 5.00mm | 2EDGR-5.0-04P | Degson | 1 | 0.18 | IN: A/B/12V/GND; mates with 2EDGK-5.0-04P; loop-through | THT
Connector | RS-485 IN pluggable plug 4-pin 5.00mm | 2EDGK-5.0-04P | Degson | 1 | 0.18 | Field-side plug for IN; A/B/12V/GND | Accessory
Connector | RS-485 OUT pluggable PCB mate 4-pin 5.00mm | 2EDGR-5.0-04P | Degson | 1 | 0.18 | OUT: A/B/12V/GND; mates with 2EDGK-5.0-04P; loop-through | THT
Connector | RS-485 OUT pluggable plug 4-pin 5.00mm | 2EDGK-5.0-04P | Degson | 1 | 0.18 | Field-side plug for OUT; A/B/12V/GND | Accessory
Connector | Cable gland PG9 for 4-conductor cable | PG9-GLAND | Wiska | 1 | 1.50 | Strain relief and environmental sealing | THT
Protection | ESD protection diode array 4-ch | SP0503BAHTG | Littelfuse | 1 | 0.08 | Bus and power line protection | SMD
Fieldbus | Termination resistor 120 ohm 0805 | R0805-120R | Generic | 1 | 0.01 | RS-485 line termination switched by DIP 8 | SMD
Clock | 8MHz crystal for MCU | ABMM2-8.000MHZ-E2-T | ABRACON | 1 | 0.12 | MCU external clock source | SMD
Addressing | 8-position SMD DIP switch | DSHP08TS-S | XKB | 1 | 0.22 | 1-7=Modbus addr; 8=120Ω termination enable; silkscreen: 1-7=ADDR | 8=TERM | ON/OFF | SMD
Status | Status LED green 0603 | LTST-C190KGKT | Lite-On | 1 | 0.01 | Operational status indication | SMD
Passives | Resistors and capacitors 0603 assorted | R0603 assortment | Generic | 1 | 0.25 | Bus termination pullups bypass caps | SMD
Mechanical | Industrial vibration mounting stud M6 | ISO-4762-M6x20 | Generic | 2 | 0.25 | Rigid coupling to motor housing | Mechanical
Mechanical | Thread-locking compound | Loctite-242 | Henkel | 0.1 | 0.02 | Permanent sensor mounting | Mechanical
PCB | 2-layer PCB FR4 1.55mm 40x30mm | PCB-2L-SMALL | Various | 1 | 0.75 | Sensor module with MCU | PCB
Enclosure | Custom enclosure (IP67 miniature housing) | CUSTOM | Custom | 1 | 3.20 | Custom enclosure; equivalent spec to OKW-A9073009 | Mechanical
Programming | Tag-Connect SWD footprint (TC2050 or TC2030) | TC2050/TC2030 | Tag-Connect | 0 | 0.00 | DNP; ensure footprint on PCB for SWD | SMD

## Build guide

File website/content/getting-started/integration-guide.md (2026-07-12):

# EsoCore Integration Guide

Comprehensive guide for integrating EsoCore with existing industrial systems including CMMS, SCADA, MES, ERP, and industrial protocols. Learn how to
connect EsoCore monitoring data to your existing workflows, automate maintenance processes, and maximize the value of equipment health insights.

---

## Integration Overview

EsoCore supports multiple integration pathways to fit into your existing industrial infrastructure:

**Industrial Protocols:**

- Modbus RTU/TCP
- PROFINET Device
- PROFIBUS DP
- OPC UA (planned)

**IT Systems:**

- REST API for custom integrations
- Webhook notifications for events
- Database access for analytics
- File exports (CSV, JSON, Parquet)

**Common Integrations:**

- CMMS (Computerized Maintenance Management Systems)
- SCADA (Supervisory Control and Data Acquisition)
- MES (Manufacturing Execution Systems)
- ERP (Enterprise Resource Planning)
- BI Tools (Business Intelligence and Analytics)

---

## REST API Integration

### API Overview

EsoCore provides a REST API for programmatic access to platform features.

> **Note:** The management API is under active development. Some integration patterns described below
> (webhooks, alert acknowledgment, config REST API) are planned but not yet implemented.
> Refer to the live Swagger documentation at `/api/docs/` for the current endpoint list.

**Base URL:** `https://[SERVER]/api/`

**Authentication:** Token-based authentication via `Authorization` header, or API key
via `X-Auth-Key` header (also accepts `X-API-Key` for compatibility):

```http
Authorization: Token your-token-here
# or for device-facing IoT endpoints:
X-Auth-Key: your-device-api-key
```

**Response Format:** JSON

### Authentication

Users authenticate via the login endpoint:

```python
import requests

# Get auth token
response = requests.post(
    "https://server/api/auth/login/",
    json={"email": "user@example.com", "password": "password"}
)
token = response.json()["token"]

# Use token for subsequent requests
headers = {
    "Authorization": f"Token {token}",
    "Content-Type": "application/json"
}

response = requests.get(
    "https://server/api/telemetry/points/",
    headers=headers
)
```

### Key API Endpoints

**Management Endpoints (token auth):**

```http
GET /api/devices/devices/          # Device list
GET /api/devices/sites/            # Site list
GET /api/devices/firmware/         # Firmware bundles
GET /api/telemetry/packets/        # Telemetry packets
GET /api/telemetry/points/         # Telemetry data points
GET /api/telemetry/windows/        # Telemetry windows
GET /api/events/events/            # System events
GET /api/events/rules/             # Alert rules
GET /api/events/notifications/     # Notification queue
GET /api/assets/assets/            # Asset management
GET /api/assets/cycles/            # Asset cycles
GET /api/users/profiles/           # User profiles
GET /api/dashboard/summary/        # Dashboard summary
```

**IoT Device-Facing Endpoints (API key auth via `X-Auth-Key`):**

```http
POST /api/iot/v1/auth/handshake    # Device authentication
POST /api/iot/v1/telemetry/batch   # Telemetry data ingestion
GET  /api/iot/v1/config            # Device configuration
GET  /api/iot/v1/ota/check         # OTA update check
POST /api/iot/v1/ota/report        # OTA update status report
```

Common query parameters for list endpoints:

- `page`: Page number for pagination
- `page_size`: Results per page
- `ordering`: Sort field
- `search`: Text search filter

### Example Integrations

**Python Integration:**

```python
import requests
from datetime import datetime, timedelta

class EsoCoreClient:
    def __init__(self, base_url, token):
        self.base_url = base_url
        self.headers = {
            "Authorization": f"Token {token}",
            "Content-Type": "application/json"
        }

    def get_devices(self):
        """Get all devices"""
        response = requests.get(
            f"{self.base_url}/devices/devices/",
            headers=self.headers
        )
        return response.json()

    def get_telemetry_points(self, **params):
        """Get telemetry data points"""
        response = requests.get(
            f"{self.base_url}/telemetry/points/",
            headers=self.headers,
            params=params
        )
        return response.json()

    def get_events(self, **params):
        """Get system events"""
        response = requests.get(
            f"{self.base_url}/events/events/",
            headers=self.headers,
            params=params
        )
        return response.json()

# Usage
client = EsoCoreClient(
    base_url="https://your-server/api",
    token="your-auth-token"
)

# Get devices
devices = client.get_devices()
for device in devices["results"]:
    print(f"{device['name']}: {device['status']}")

# Get recent events
events = client.get_events()
if events["results"]:
    print(f"INFO: {len(events['results'])} recent events")
```

**JavaScript/Node.js Integration:**

```javascript
const axios = require('axios')

class EsoCoreClient {
  constructor(baseUrl, token) {
    this.baseUrl = baseUrl
    this.headers = {
      Authorization: `Token ${token}`,
      'Content-Type': 'application/json',
    }
  }

  async getDevices() {
    const response = await axios.get(`${this.baseUrl}/devices/devices/`, {
      headers: this.headers,
    })
    return response.data
  }

  async getTelemetryPoints(params = {}) {
    const response = await axios.get(`${this.baseUrl}/telemetry/points/`, {
      headers: this.headers,
      params,
    })
    return response.data
  }
}

// Usage
const client = new EsoCoreClient('https://your-server/api', 'your-auth-token')

client
  .getDevices()
  .then(data => console.log(data.results))
  .catch(error => console.error(error))
```

---

## CMMS Integration

### Overview

Integrate EsoCore with Computerized Maintenance Management Systems to automatically create work orders based on equipment condition.

**Supported CMMS Platforms:**

- SAP PM
- IBM Maximo
- Infor EAM
- eMaint
- Fiix
- Generic via REST API

### Integration Methods

**Method 1: Webhook Notifications**

Configure EsoCore to send alerts directly to CMMS:

1. **In EsoCore:**
   - Settings → Integrations → Webhooks
   - Add new webhook
   - Webhook URL: `https://cmms.company.com/api/work-orders`
   - Authentication: Bearer token or API key
   - Event types: Select alert severities to trigger
   - Payload template: Map EsoCore data to CMMS fields

2. **Payload Example:**

```json
{
  "equipment_id": "{{device_id}}",
  "alert_type": "{{alert_severity}}",
  "description": "{{alert_message}}",
  "priority": "{{priority_mapping}}",
  "detected_at": "{{timestamp}}",
  "sensor_data": {
    "sensor": "{{sensor_name}}",
    "value": "{{current_value}}",
    "threshold": "{{threshold_value}}"
  }
}
```

3. **Test integration** with sample alert

**Method 2: Scheduled Polling**

CMMS polls EsoCore API periodically:

```python
# CMMS-side script (runs every 5 minutes)
import requests

ESOCORE_API = "https://your-server/api"
ESOCORE_TOKEN = "your-auth-token"
CMMS_API = "https://cmms/api/work-orders"
CMMS_KEY = "cmms-api-key"

# Get recent events from EsoCore
events = requests.get(
    f"{ESOCORE_API}/events/events/",
    headers={"Authorization": f"Token {ESOCORE_TOKEN}"},
).json()

# Create work orders in CMMS for new events
for event in events["results"]:
    work_order = {
        "equipment_id": event["device"],
        "title": f"Alert: {event['event_type']}",
        "description": event["message"],
        "priority": map_priority(event["severity"]),
        "due_date": calculate_due_date(event["severity"])
    }

    # Create work order
    response = requests.post(
        CMMS_API,
        headers={"Authorization": f"Bearer {CMMS_KEY}"},
        json=work_order
    )
```

**Method 3: Email-to-Ticket**

If CMMS supports email-to-ticket:

1. **In EsoCore:**
   - Settings → Notifications → Email
   - Add CMMS email address: `workorders@cmms.company.com`
   - Configure email template with required CMMS fields in subject/body

2. **Email Template:**

```
Subject: [EQUIPMENT:{{device_name}}][PRIORITY:{{severity}}] {{alert_type}}

Equipment: {{device_name}}
Location: {{location}}
Alert: {{alert_type}}
Severity: {{severity}}
Detected: {{timestamp}}

Description:
{{alert_message}}

Sensor Data:
{{sensor_readings}}

Recommended Action:
{{recommended_action}}
```

### SAP PM Integration Example

```python
# SAP PM work order creation
from pyrfc import Connection

def create_sap_notification(alert):
    # Connect to SAP
    conn = Connection(
        ashost='sap.company.com',
        sysnr='00',
        client='100',
        user='INTERFACE_USER',
        passwd='password'
    )

    # Call BAPI to create notification
    result = conn.call('BAPI_ALM_NOTIF_CREATE', {
        'NOTIFHEADER': {
            'NOTIF_TYPE': 'M2',  # Maintenance notification
            'EQUIPMENT': alert['equipment_id'],
            'PRIORITY': map_to_sap_priority(alert['severity'])
        },
        'NOTIFTASK': [{
            'TASK_TEXT': alert['message'],
            'TASK_CODE': 'PRED',  # Predictive maintenance
            'TASK_CODEGRP': 'PM'
        }]
    })

    if result['RETURN']['TYPE'] == 'S':
        notification_id = result['NOTIFHEADER']['NOTIF_NO']
        return notification_id
    else:
        raise Exception(f"SAP Error: {result['RETURN']['MESSAGE']}")
```

---

## SCADA Integration

### Modbus TCP Integration

Expose EsoCore data to SCADA via Modbus TCP:

**Configuration:**

1. EsoCore Web UI → Settings → Fieldbus → Modbus TCP
2. Enable Modbus TCP Server
3. Port: 502 (default) or custom
4. Configure register mapping:
   - Starting register: 40001
   - Data type: Float (2 registers) or Integer (1 register)
   - Map sensors to register ranges

**Register Map Example:**

| Register | Parameter | Type  | Unit |
| --- | --- | ----- | --- |
| 40001-40002 | Motor 1 Vibration RMS | Float | mm/s |
| 40003-40004 | Motor 1 Temperature | Float | °C |
| 40005-40006 | Motor 1 Current Phase A | Float | A |
| 40007 | Motor 1 Status | Int | 0=OK, 1=Warning, 2=Alert |
| 40008 | Motor 1 Alert Code | Int | See docs |
| ... | ... | ... | ... |

**SCADA Configuration:**

_Allen-Bradley / Rockwell:_

```
Controller: Modbus/TCP
IP Address: 192.168.1.100
Port: 502
Unit ID: 1
Register Map: Import CSV
Scan Rate: 1000ms
```

_Siemens WinCC:_

```
Driver: ModbusTCP.chn
IP: 192.168.1.100
Port: 502
Register Configuration: Import from XML
Update Cycle: 1s
```

_Ignition SCADA:_

```python
# Add device
Name: EsoCore_Edge1
Driver: Modbus TCP
Hostname: 192.168.1.100
Port: 502

# Configure tags
Motor1_Vibration: Float, 40001, 2 registers
Motor1_Temperature: Float, 40003, 2 registers
Motor1_Status: Int16, 40007, 1 register
```

### OPC UA Integration (Planned)

Future release will include OPC UA server:

- Standard OPC UA information model
- TLS-encrypted communication
- User authentication
- Browse-able address space
- Subscriptions for real-time updates

---

## MES Integration

### Manufacturing Execution System Integration

Connect equipment health data to production systems:

**Use Cases:**

- Display equipment health on production dashboards
- Prevent production scheduling on degraded equipment
- Correlate quality issues with equipment condition
- Track equipment availability for OEE calculation

**Integration Example:**

```python
# MES Integration Script
import requests
from datetime import datetime

class MESIntegration:
    def __init__(self, esocore_url, esocore_key, mes_url, mes_key):
        self.esocore_url = esocore_url
        self.esocore_headers = {"Authorization": f"Token {esocore_key}"}
        self.mes_url = mes_url
        self.mes_headers = {"Authorization": f"Bearer {mes_key}"}

    def update_equipment_status(self):
        """Update MES with equipment health status"""
        # Get equipment health from EsoCore
        devices = requests.get(
            f"{self.esocore_url}/devices/devices/",
            headers=self.esocore_headers
        ).json()

        for device in devices:
            # Get current health status
            health = self.get_device_health(device['id'])

            # Update MES equipment status
            requests.put(
                f"{self.mes_url}/equipment/{device['equipment_id']}/status",
                headers=self.mes_headers,
                json={
                    "health_score": health['score'],
                    "status": health['status'],
                    "alerts": health['active_alerts'],
                    "last_updated": datetime.now().isoformat()
                }
            )

    def check_production_readiness(self, equipment_id):
        """Check if equipment is ready for production"""
        device = self.get_device_by_equipment_id(equipment_id)

        # Get active alerts
        events = requests.get(
            f"{self.esocore_url}/events/events/",
            headers=self.esocore_headers,
            params={"device": device['id']}
        ).json()

        # Check for critical events
        critical_alerts = [e for e in events["results"] if e.get('severity') == 'critical']

        return {
            "ready": len(critical_alerts) == 0,
            "alerts": critical_alerts,
            "recommendation": "Schedule maintenance" if critical_alerts else "OK"
        }
```

---

## ERP Integration

### Enterprise Resource Planning Integration

Connect equipment data to business systems:

**Use Cases:**

- Automatic spare parts ordering based on predictions
- Maintenance cost tracking and budgeting
- Asset lifecycle management
- Warranty and vendor management

**Integration Points:**

_Procurement:_

```python
# Trigger spare parts order based on alert
def trigger_parts_order(alert):
    # Map alert to required spare parts
    parts = get_required_parts(alert['device_type'], alert['alert_type'])

    # Create purchase requisition in ERP
    for part in parts:
        create_purchase_req(
            part_number=part['number'],
            quantity=1,
            priority="Normal" if alert['severity'] != 'critical' else "Urgent",
            requester="Predictive Maintenance System",
            notes=f"Based on alert: {alert['message']}"
        )
```

_Finance:_

```python
# Track actual maintenance costs vs predicted
def track_maintenance_roi():
    # Get prevented failures
    prevented = get_prevented_failures()

    # Calculate avoided costs
    avoided_costs = sum([
        failure['estimated_downtime_hours'] * facility_hourly_rate +
        failure['estimated_repair_cost']
        for failure in prevented
    ])

    # Get actual monitoring costs
    monitoring_costs = get_monitoring_system_costs()

    # Calculate ROI
    roi = (avoided_costs - monitoring_costs) / monitoring_costs * 100

    # Post to ERP financial module
    post_cost_savings(
        category="Predictive Maintenance",
        avoided_costs=avoided_costs,
        actual_costs=monitoring_costs,
        roi=roi
    )
```

---

## Business Intelligence Integration

### Data Export for Analytics

**CSV Export:**

```python
# Export historical data for analysis
def export_to_csv(device_id, start_date, end_date):
    data = requests.get(
        f"{API_URL}/telemetry/points/",
        headers=headers,
        params={
            "device_id": device_id,
            "start_time": start_date,
            "end_time": end_date,
            "limit": 100000
        }
    ).json()

    # Convert to pandas DataFrame
    import pandas as pd
    df = pd.DataFrame(data)
    df.to_csv(f"esocore_export_{device_id}.csv", index=False)
```

**Database Integration:**

```python
# Sync to data warehouse
import psycopg2

def sync_to_warehouse():
    # Connect to data warehouse
    conn = psycopg2.connect(
        host="warehouse.company.com",
        database="analytics",
        user="esocore_sync",
        password="password"
    )

    # Get latest data from EsoCore
    latest_data = get_latest_telemetry()

    # Insert into warehouse
    cursor = conn.cursor()
    for reading in latest_data:
        cursor.execute("""
            INSERT INTO equipment_telemetry
            (timestamp, device_id, sensor_id, metric, value, unit)
            VALUES (%s, %s, %s, %s, %s, %s)
            ON CONFLICT (timestamp, device_id, sensor_id, metric)
            DO UPDATE SET value = EXCLUDED.value
        """, (
            reading['timestamp'],
            reading['device_id'],
            reading['sensor_id'],
            reading['metric'],
            reading['value'],
            reading['unit']
        ))

    conn.commit()
    cursor.close()
    conn.close()
```

**Power BI Integration:**

```python
# Power BI REST API integration
def publish_to_powerbi(dataset_id, table_name, data):
    import requests

    # Get Power BI access token (OAuth2)
    token = get_powerbi_token()

    # Push data to Power BI
    response = requests.post(
        f"https://api.powerbi.com/v1.0/myorg/datasets/{dataset_id}/tables/{table_name}/rows",
        headers={
            "Authorization": f"Bearer {token}",
            "Content-Type": "application/json"
        },
        json={"rows": data}
    )

    return response.ok
```

---

## Best Practices

### Security

**API Key Management:**

- Generate separate keys for each integration
- Use read-only keys when possible
- Rotate keys regularly (quarterly recommended)
- Store keys securely (vault, environment variables)
- Never commit keys to source control

**Network Security:**

- Use TLS/HTTPS for all API connections
- Implement firewall rules limiting access
- Use VPN for remote integrations
- Monitor API usage for anomalies

### Performance

**Optimize API Usage:**

- Cache data when appropriate
- Use bulk endpoints vs many individual calls
- Implement exponential backoff for retries
- Set reasonable polling intervals (1-5 minutes typical)
- Use webhooks instead of polling when possible

**Data Management:**

- Only query data you need (use filters)
- Limit historical queries to necessary time ranges
- Implement pagination for large datasets
- Archive old data regularly

### Reliability

**Error Handling:**

```python
import time
from requests.adapters import HTTPAdapter
from requests.packages.urllib3.util.retry import Retry

def get_session_with_retries():
    session = requests.Session()
    retry = Retry(
        total=3,
        backoff_factor=1,
        status_forcelist=[429, 500, 502, 503, 504]
    )
    adapter = HTTPAdapter(max_retries=retry)
    session.mount('https://', adapter)
    return session

# Usage
session = get_session_with_retries()
response = session.get(url, headers=headers)
```

**Monitoring:**

- Log all integration errors
- Track API response times
- Monitor data freshness
- Alert on integration failures
- Maintain fallback procedures

---

## Support and Resources

### Documentation

- [REST API Reference](/docs/api-specification)
- [Hardware Specifications](/docs/esocore-edge)
- [Installation Guide](/docs/getting-started/installation-guide)
- [Quick Start Guide](/docs/getting-started/quick-start)

### Examples and Code

- GitHub repository: Sample integrations and code examples
- Community contributions: Share your integrations
- Professional services: Custom integration development available

### Support

- Community forum: GitHub Discussions
- Commercial support: support@newmatik.com
- Integration consulting: consulting@newmatik.com

---

Successful integration amplifies the value of equipment monitoring by connecting insights to action. Choose the integration methods that best fit your
existing infrastructure and workflows.

[API Documentation](/docs/api-specification) | [Installation Guide](/docs/getting-started/installation-guide) |
[Quick Start](/docs/getting-started/quick-start)

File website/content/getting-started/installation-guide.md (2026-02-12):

# EsoCore Installation Guide

Complete installation guide for deploying EsoCore industrial IoT monitoring across your facility. This comprehensive guide covers hardware
installation, network configuration, sensor deployment, cloud platform setup, and system integration for production deployments.

---

## Prerequisites

### Hardware Requirements

**Per Monitored Machine:**

- 1× EsoCore Edge device (STM32H747-based)
- 1-5× Sensor modules (based on monitoring requirements)
- 24V DC power supply (2A minimum, dedicated external supply recommended)
- Industrial microSD card (8GB+, SLC or MLC with wear leveling)
- Ethernet cable (Cat5e or better) OR WiFi access
- RS-485 cable (4-conductor shielded, Belden 3105A or equivalent)

**Tools Required:**

- Screwdrivers (Phillips and flathead)
- Wire strippers and crimpers
- Multimeter for voltage verification
- Drill and mounting hardware
- Cable ties and labels
- Laptop or tablet for configuration

### Network Requirements

**Connectivity Options:**

- Dual Ethernet with DHCP on IT port and static IP on machine port (recommended)
- Static IP assignment on both ports
- WiFi (2.4 GHz, WPA2 minimum)

**Bandwidth:**

- Minimal: <1 KB/min per device normal operation
- Peak: 10-50 KB during anomaly events
- Cloud sync: 50-100 MB/month per device

**Firewall Requirements:**

- Outbound HTTPS (port 443) for cloud sync
- Optional: Inbound HTTPS (port 443) for local web UI access
- Optional: Modbus TCP (port 502), PROFINET for integration

### Skills Required

**Basic Installation:**

- Industrial equipment familiarity
- Basic electrical knowledge (12-24V DC safety)
- Network configuration basics
- Reading installation diagrams

**Advanced Installation:**

- Industrial protocol knowledge (Modbus, PROFINET)
- System integration experience
- Network troubleshooting capabilities

---

## Installation Planning

### Step 1: Equipment Assessment

**Identify Monitoring Priorities:**

1. List all equipment to be monitored
2. Classify by criticality (High/Medium/Low)
3. Document historical failure modes
4. Determine sensor requirements per machine
5. Calculate total hardware requirements

**Site Survey:**

- Verify 24V DC power availability
- Check network connectivity at each location
- Identify sensor mounting locations
- Plan cable routing paths
- Document environmental conditions

**Create Installation Plan:**

- Deployment schedule (phased approach recommended)
- Resource allocation (personnel, tools, time)
- Downtime windows for installation
- Testing and validation timeline
- Training schedule

### Step 2: Hardware Procurement

**Edge Devices:**

- Quantity needed: [_____]
- Configuration: Standard or custom
- Accessories: Mounting hardware, power supplies
- Lead time: 2-4 weeks typical

**Sensor Modules:**

- Vibration sensors: [_____]
- Temperature sensors: [_____]
- Current sensors: [_____]
- Pressure sensors: [_____]
- Acoustic sensors: [_____]
- Other sensors: [_____]

**Cables and Accessories:**

- RS-485 cable length needed: [_____] meters
- Ethernet cables: [_____]
- Power cables: [_____]
- Junction boxes: [_____]
- Cable management: Ties, conduit, labels

**Spare Parts:**

- Recommend 10% spare sensors
- 2-3 spare Edge devices
- Spare cables and connectors

---

## Edge Device Installation

### Physical Installation

**Location Selection:**

- Within 100 meters of sensors (RS-485 range limit)
- Protected from physical damage
- Temperature: -20°C to +60°C
- Protected from moisture and contaminants
- Good WiFi signal if not using Ethernet
- Accessible for maintenance and viewing display

**Mounting Options:**

_DIN Rail Mount:_

1. Measure required rail space (10cm width typical)
2. Position device on 35mm DIN rail
3. Press down until clips engage
4. Verify secure mounting

_Wall Mount:_

1. Mark mounting hole locations
2. Drill holes appropriate for wall material
3. Install anchors if needed
4. Secure device with provided screws
5. Ensure level and secure mounting

_Panel Mount:_

1. Cut opening in panel per template
2. Insert device from front
3. Secure with provided brackets
4. Seal edges if needed for environment

### Power Connection

**24V DC Power Connection:**

1. Verify power supply voltage: 24V DC nominal
2. Confirm current capacity: 2A minimum
3. Identify polarity (typically red = +, black = -)
4. **Double-check polarity before connecting!**
5. Connect wires to terminal block:
   - V+ to positive terminal
   - GND to negative terminal
6. Tighten terminal screws securely
7. Apply power
8. Verify power LED illuminates
9. Check OLED display shows boot sequence

**Power Verification:**

- Display shows firmware version and IP address
- Status LEDs indicate normal operation
- No error messages on display
- Device responds to network ping

### Network Configuration

**DHCP Configuration (Default):**

1. Connect Ethernet cable or configure WiFi
2. Device obtains IP automatically
3. Note IP address from OLED display
4. Verify connectivity: `ping [IP_ADDRESS]`
5. Access web UI: `https://[IP_ADDRESS]`

**Static IP Configuration:**

1. Initially connect via DHCP to access web UI
2. Navigate to Settings → Network
3. Change from DHCP to Static
4. Enter static IP configuration:
   - IP Address: [_____]
   - Subnet Mask: [_____]
   - Gateway: [_____]
   - DNS Server: [_____]
5. Apply settings
6. Device reboots with new IP
7. Verify connectivity at new IP address

**WiFi Configuration:**

1. Power on device without Ethernet connected
2. Device enters AP mode: "EsoCore-[SERIAL]"
3. Connect laptop/phone to this network
4. Browse to: http://192.168.4.1
5. Enter WiFi credentials:
   - SSID: [_____]
   - Password: [_____]
   - Security: WPA2 (recommended)
6. Click "Connect"
7. Device reboots and connects to WiFi
8. Note IP address from display
9. Verify connectivity

**Network Troubleshooting:**

- No IP address: Check DHCP server, cable connection
- Cannot access web UI: Check firewall, use HTTPS not HTTP
- Intermittent connectivity: Check WiFi signal strength, interference
- Slow response: Check network congestion, bandwidth

### USB Connection (Maintenance and Development)

**Purpose:**

The USB connection on the EsoCore Edge device is used exclusively for:

- **Firmware flashing:** Updating device firmware
- **Serial communication:** Terminal access for diagnostics and direct device communication

**Important Notes:**

- USB is NOT used for normal operation or data collection
- USB is NOT used for network connectivity or data transfer
- Use network interfaces (Ethernet/WiFi) for operational communication
- USB access requires physical connection to the device

**Serial Terminal Access:**

1. Connect USB cable between Edge device and computer
2. Install appropriate USB-to-serial drivers if needed
3. Use terminal application (PuTTY, screen, minicom):
   - Baud rate: 115200
   - Data bits: 8
   - Parity: None
   - Stop bits: 1
4. Access diagnostic commands and system logs

**Firmware Updates:**

1. Download firmware file (.bin or .hex)
2. Connect via USB
3. Enter bootloader mode (follow device-specific procedure)
4. Flash firmware using appropriate tool
5. Device reboots with new firmware

---

## Sensor Installation

### Vibration Sensor Installation

**Location Selection:**

- Close to rotating components (bearings, gears)
- Rigid mounting surface (not flexible sheet metal)
- Accessible for future inspection
- Away from excessive heat or contamination

**Mounting Methods:**

_Stud Mount (Preferred - Best Accuracy):_

1. Drill and tap mounting hole (M6 or M8 typical)
2. Clean mounting surface thoroughly
3. Apply thin layer of coupling compound
4. Thread sensor onto stud
5. Tighten to specified torque
6. Verify sensor is firmly mounted

_Magnetic Mount (Quick Installation):_

1. Clean mounting surface (remove paint, oil, rust)
2. Ensure surface is flat and smooth
3. Place magnet base on surface
4. Verify strong magnetic attachment
5. Apply safety cable as backup

_Adhesive Mount (Temporary or Testing):_

1. Clean surface with isopropyl alcohol
2. Apply industrial adhesive or epoxy
3. Press sensor firmly to surface
4. Allow curing time per adhesive specs
5. Verify bond before leaving

**Wiring:**

1. Route 4-conductor shielded cable to sensor
2. Strip wire ends carefully
3. Connect to terminal block:
   - Power+ (red)
   - Power- (black)
   - Data+ (green/A)
   - Data- (white/B)
4. Secure strain relief
5. Connect shield to ground at one end only

**DIP Switch Addressing:**

1. Each sensor needs unique address (1-254)
2. Set address using binary DIP switches
3. Example addresses:
   - 00000001 = Address 1
   - 00000010 = Address 2
   - 00000011 = Address 3
   - etc.
4. Document address for each sensor
5. Label sensor with address number

### Temperature Sensor Installation

**Mounting Locations:**

- Bearing housings (direct contact)
- Motor bodies
- Hydraulic reservoirs
- Gearbox housings
- Process fluids (with thermowells)

**Installation:**

_Surface Mount:_

1. Clean mounting surface
2. Apply thermal compound for good contact
3. Secure sensor with clamp or adhesive
4. Insulate from ambient if needed
5. Verify good thermal contact

_Thermowell Installation (Process Fluids):_

1. Install thermowell in process per specifications
2. Fill thermowell with thermal compound
3. Insert temperature sensor
4. Secure compression fitting
5. Allow thermal stabilization (15-30 minutes)

**Wiring:** Same 4-conductor bus connection as vibration sensors Set unique DIP switch address

### Current Sensor Installation

**CT Clamp Installation:**

1. Identify motor power conductors
2. Select appropriate clamp size for conductor
3. Open clamp jaws
4. Place around **single** conductor (not bundled cable)
5. Close clamp until it clicks
6. Arrow on clamp indicates current flow direction
7. Secure clamp to prevent movement
8. For 3-phase motors: Install clamp on each phase

**Important Safety Notes:**

- **Never** work on live circuits without proper training
- Follow lockout/tagout procedures
- Verify circuits are de-energized before installation
- Use appropriate PPE
- Follow electrical codes and regulations

**Wiring:** Same 4-conductor bus connection Set unique DIP switch address

### Additional Sensor Types

**Pressure Sensors:**

- Install in pressure taps with appropriate fittings
- Use thread sealant or tape
- Verify pressure range matches application
- Consider pulsation dampeners if needed

**Acoustic Sensors:**

- Mount near sound source (bearings, valves, leaks)
- Avoid mounting on vibrating surfaces
- Use foam isolation pad if needed
- Protect from moisture and contamination

**Proximity/Position Sensors:**

- Mount with specified air gap
- Align with target surface/object
- Verify detection distance
- Secure mounting to prevent movement

### RS-485 Bus Wiring

**Cable Routing:**

1. Use 4-conductor shielded cable (Belden 3105A or equivalent)
2. Keep away from power cables (minimum 12" separation)
3. Avoid parallel runs with AC power
4. Use conduit or cable tray for protection
5. Support cable every 3-6 feet
6. Avoid sharp bends (minimum 4× cable diameter radius)

**Daisy Chain Topology:**

```text
Edge Device → Sensor 1 → Sensor 2 → Sensor 3 → ... → Last Sensor
```

1. Connect Edge device to first sensor (4 wires)
2. Connect first sensor to second sensor (4 wires)
3. Continue chain to last sensor
4. Maximum total length: 100 meters
5. Shield grounded at one end only (usually at Edge device)

**Termination:**

- Install 120Ω termination resistor at last sensor
- Some sensors have DIP switch for built-in termination
- Required for proper signal integrity
- Edge device typically has built-in termination on its end

**Bus Power:**

- Edge device supplies +12V to sensor bus
- Total current limit: 2A
- Typical sensor consumption: 50-150mA each
- Calculate total: [Number of sensors] × [150mA] = [_____] mA
- Must be less than 2000mA

---

## System Configuration

### Initial Setup

**Access Web Interface:**

1. Note IP address from Edge device display
2. Open web browser on computer (same network)
3. Navigate to: `https://[IP_ADDRESS]`
4. Accept self-signed certificate warning (first time only)
5. Default credentials:
   - Username: `admin`
   - Password: `esocore`

**First-Time Setup Wizard:**

1. Change admin password (required)
2. Set device name and location
3. Configure timezone and NTP server
4. Set network preferences (if not using defaults)
5. Review settings and apply

### Sensor Discovery

**Automatic Discovery:**

1. Navigate to: Sensors → Discovery
2. Click "Scan RS-485 Bus"
3. System discovers all connected sensors
4. Review discovered sensors list
5. Verify expected sensors found

**Assign Descriptive Names:** For each sensor:

1. Click sensor to edit
2. Change name from default to descriptive:
   - "Motor 1 Drive End Bearing"
   - "Pump Discharge Pressure"
   - "Spindle Temperature"
3. Assign location/machine association
4. Set measurement units if applicable
5. Save changes

### Sensor Configuration

**Sampling Rates:**

Configure appropriate rates for each sensor type:

_Vibration Sensors:_

- Analysis windows: 1-3 kHz for 1-5 seconds
- Window frequency: Every 5-15 minutes
- Continuous RMS: 1-10 Hz
- Alert evaluation: Every 30-60 seconds

_Temperature Sensors:_

- Sampling rate: 0.1-1 Hz (every 1-10 seconds)
- Alert evaluation: Every 60 seconds
- Thermal time constant consideration

_Current Sensors:_

- Sampling rate: 100-500 Hz
- RMS calculation: 1-10 Hz
- Power analysis: Every 1-5 seconds

_Pressure Sensors:_

- Sampling rate: 1-10 Hz
- Alert evaluation: Every 10-60 seconds
- Filtering for pulsations if needed

**Measurement Ranges:**

- Select appropriate range for application
- Avoid saturation (clipping)
- Optimize for signal-to-noise ratio
- Can be adjusted based on baseline data

### Baseline Collection

**Understanding Baselines:**

- System needs 2-4 weeks to learn normal operation
- Automatic process (no interaction required)
- Alerts disabled during baseline period
- Must include all operating modes

**Monitoring Progress:**

1. Navigate to Dashboard → Baseline Status
2. View percentage complete for each sensor
3. Green checkmarks indicate sufficient data
4. Typical completion: 2-4 weeks

**Accelerating Baseline:**

- Operate equipment through all modes
- Include startups and shutdowns
- Cover different load conditions
- Run through full operational range
- 24/7 operation speeds learning

### Alert Configuration

**After Baseline Completes:**

1. Navigate to Settings → Alerts
2. Review suggested thresholds:
   - Warning: 20% deviation from baseline
   - Attention: 40% deviation
   - Critical: 80% deviation
3. Adjust sensitivity:
   - More sensitive = earlier warnings, more false positives
   - Less sensitive = fewer alerts, potentially late warnings
4. Start with suggested values
5. Tune based on experience

**Notification Methods:**

_Email:_

1. Settings → Notifications → Email
2. Enter SMTP server details:
   - Server: smtp.example.com
   - Port: 587 (TLS) or 465 (SSL)
   - Username: [_____]
   - Password: [_____]
3. Add recipient email addresses
4. Select severity levels to notify
5. Test email delivery

_Local Outputs:_

1. Wire relay outputs to alarm devices
2. Configure trigger conditions
3. Test before relying on

_CMMS Integration:_

1. Settings → Integrations → CMMS
2. Enter CMMS API endpoint
3. Configure authentication
4. Enable auto work order creation
5. Map alert severities to work order priorities

---

## Cloud Platform Setup (Optional)

### Self-Hosted Deployment

**Server Requirements:**

- Linux server (Ubuntu 20.04+ recommended)
- 4 CPU cores minimum
- 8 GB RAM minimum
- 100 GB storage
- Docker and Docker Compose installed

**Installation:**

```bash
# Clone EsoCore repository
git clone https://github.com/newmatik/EsoCore.git
cd EsoCore/server

# Install Python dependencies with Poetry
pip install poetry
poetry install

# Run database migrations
poetry run python manage.py migrate

# Create admin user
poetry run python manage.py createsuperuser

# Start the server
poetry run python manage.py runserver 0.0.0.0:8000
```

> **Note:** Docker deployment files are planned but not yet included.
> For production, configure a WSGI/ASGI server (e.g. Gunicorn) behind a reverse proxy (e.g. Nginx).

**Access Platform:**

- Admin interface: https://[SERVER_IP]/admin
- API endpoint: https://[SERVER_IP]/api/
- Configure DNS and SSL certificates for production

### Managed Cloud Service

**Sign Up:**

1. Visit: https://cloud.esocore.com (if using managed service)
2. Create account
3. Select plan based on device count
4. Enter payment information

**Device Provisioning:**

1. Navigate to Devices → Add Device
2. Enter device serial number
3. Generate API key
4. Note API key (shown once)
5. Device status shows "Pending"

**Edge Device Configuration:**

1. On Edge device web UI: Settings → Cloud
2. Enter cloud platform URL
3. Enter device API key
4. Configure sync interval (5-15 minutes recommended)
5. Click "Test Connection"
6. Enable "Auto Sync"
7. Device appears online in cloud platform

---

## System Integration

### Modbus Integration

**Modbus RTU (RS-485):**

1. Connect Modbus devices to dedicated RS-485 port
2. Configure in web UI:
   - Settings → Fieldbus → Modbus RTU
   - Baud rate: 9600, 19200, or 115200
   - Device addresses to poll
   - Register map configuration
3. Enable Modbus polling
4. Verify data appears in dashboard

**Modbus TCP:**

1. Configure in web UI:
   - Settings → Fieldbus → Modbus TCP
   - Enable Modbus TCP server
   - Port: 502 (default)
2. Configure Modbus master to connect to Edge device IP
3. Provide register map documentation
4. Test read/write operations

### PROFINET Integration

1. Settings → Fieldbus → PROFINET
2. Configure device name (GSD file provided)
3. Set I/O data mapping
4. Import into TIA Portal or PLC configuration tool
5. Configure PLC to read EsoCore data
6. Test communication

### REST API Integration

**Authentication:**

- Token authentication for users (via `Authorization: Token <token>`)
- API key authentication for devices (via `X-Auth-Key` header)

**Common Endpoints:**

```http
GET /api/devices/devices/         # List devices
GET /api/devices/sites/           # List sites
GET /api/telemetry/points/        # Get telemetry data
GET /api/events/events/           # Get system events
GET /api/dashboard/summary/       # Dashboard summary
```

**Example Integration:**

```python
import requests

API_URL = "https://your-server/api"
TOKEN = "your-auth-token"
headers = {"Authorization": f"Token {TOKEN}"}

# Get current telemetry data
response = requests.get(f"{API_URL}/telemetry/points/", headers=headers)
data = response.json()
```

---

## Testing and Validation

### Installation Verification Checklist

**Hardware:**

- [ ] All Edge devices powered and online
- [ ] All sensors discovered and responding
- [ ] Network connectivity stable
- [ ] Display shows correct status
- [ ] No error LEDs or messages

**Configuration:**

- [ ] Admin password changed from default
- [ ] Device names and locations set
- [ ] All sensors named descriptively
- [ ] Sampling rates configured
- [ ] Time zone and NTP configured
- [ ] Network settings correct (static IP if applicable)

**Data Collection:**

- [ ] Live data visible on dashboard
- [ ] Sensor readings appear reasonable
- [ ] Data logging to SD card verified
- [ ] Cloud sync functioning (if enabled)
- [ ] No data gaps or errors

**Alerts:**

- [ ] Test email notifications working
- [ ] CMMS integration tested (if configured)
- [ ] Local alarm outputs tested (if used)
- [ ] Alert thresholds set appropriately

### Functional Testing

**Test Scenarios:**

1. **Normal Operation:** Verify data collection during normal equipment operation
2. **Network Loss:** Disconnect network, verify local operation and data buffering
3. **Power Loss:** Simulate power loss, verify safe shutdown and data integrity
4. **Sensor Fault:** Disconnect sensor, verify fault detection and alerting
5. **Alert Testing:** Create alert condition, verify notification delivery

**Performance Verification:**

- Response time: <100ms for edge processing
- Data accuracy: Compare to reference instruments
- Alert latency: <1 second from detection to notification
- System uptime: 99.9% target

---

## Documentation

### Installation Records

Create documentation package including:

**Equipment List:**

- Edge device serial numbers and locations
- Sensor serial numbers and locations
- IP addresses (static or DHCP)
- API keys and credentials (securely stored)

**Wiring Diagrams:**

- RS-485 bus topology
- Power connections
- Network connections
- Integration connections

**Configuration:**

- Network settings
- Sensor configurations
- Alert thresholds
- Integration settings

**Contact Information:**

- Technical support
- Vendor contacts
- Internal IT contacts
- Maintenance team

### User Training

**Operator Training:**

- Accessing web interface
- Viewing dashboard and data
- Responding to alerts
- Basic troubleshooting

**Maintenance Training:**

- System overview
- Alert interpretation
- Planned maintenance based on alerts
- Advanced configuration

**Administrator Training:**

- User management
- System configuration
- Integration management
- Troubleshooting

---

## Maintenance

### Routine Maintenance

**Monthly:**

- Review system health dashboard
- Verify all sensors responding
- Check SD card health
- Review alert logs

**Quarterly:**

- Clean sensors and connections
- Inspect cable conditions
- Verify sensor mounting secure
- Update firmware if available

**Annually:**

- Sensor calibration verification
- Battery backup replacement (if applicable)
- SD card replacement (preventive)
- System configuration backup

### Troubleshooting

**Common Issues:**

See [Quick Start Guide](/docs/getting-started/quick-start) for detailed troubleshooting steps.

---

## Support Resources

- **Documentation:** [Complete technical docs](/docs)
- **Community:** GitHub Discussions
- **Commercial Support:** support@newmatik.com
- **Emergency:** Include escalation procedures

---

Comprehensive installation complete! Your industrial IoT monitoring system is now operational and protecting your critical equipment.

[Quick Start Guide](/docs/getting-started/quick-start) | [Integration Guide](/docs/getting-started/integration-guide) |
[API Documentation](/docs/api-specification)

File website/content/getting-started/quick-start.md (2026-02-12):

# EsoCore Quick Start Guide

Get up and running with EsoCore industrial IoT monitoring in under 30 minutes. This guide walks you through your first equipment monitoring
deployment, from hardware setup to viewing live sensor data and configuring alerts.

---

## Prerequisites

Before starting, ensure you have:

**Hardware:**

- 1 EsoCore Edge device (STM32H747-based)
- 1 or more sensor modules (vibration, temperature, or current sensor recommended for first deployment)
- 24V DC power supply (dedicated external supply recommended for maximum robustness)
- Ethernet cables (2x recommended: one for machine network, one for IT network) or WiFi credentials
- microSD card (industrial grade, 8GB+ recommended)

**Network:**

- Ethernet connection (preferred) or WiFi access
- DHCP or static IP configuration
- Outbound HTTPS access for cloud sync (optional)
- Local network access for configuration web UI

**Skills:**

- Basic understanding of industrial equipment
- Ability to mount sensors on equipment
- Basic networking knowledge (helpful but not required)

**Time Required:**

- Hardware installation: 15-30 minutes
- Initial configuration: 10-15 minutes
- Baseline data collection: 2-4 weeks (automatic, no interaction needed)
- Total hands-on time: 25-45 minutes

---

## Step 1: Hardware Setup (15-30 minutes)

### Edge Device Installation

**Location Selection:**

- Within 100 meters of monitored equipment (for RS-485 sensor bus)
- Protected from physical damage and extreme temperatures
- Good WiFi signal if not using Ethernet
- Access to 24V DC power supply

**Mounting:**

1. Mount Edge device on DIN rail or wall mount
2. Ensure adequate ventilation around device
3. Position so status display and buttons are accessible
4. Keep away from high EMI sources (VFDs, arc welders, etc.)

**Power Connection:**

_24V DC Power:_

1. Connect 24V DC power supply to terminal block
2. Observe polarity marking on device
3. Reverse polarity protection prevents damage but won't power on if backwards
4. Power LED should illuminate when correctly connected

**Network Connection:**

_Option A: Dual Ethernet (Recommended)_

1. Connect Ethernet cable to Port A (Machine Network) for PLC/SCADA integration
2. Connect Ethernet cable to Port B (IT Network) for cloud sync and remote access
3. Port A defaults to static IP; Port B obtains IP via DHCP
4. Note displayed IP addresses from OLED screen
5. Static IP configuration available via web UI for both ports

_Option B: WiFi_

1. Power on device (initially in WiFi setup mode)
2. Connect phone/laptop to "EsoCore-XXXX" WiFi network
3. Browse to 192.168.4.1
4. Enter your WiFi SSID and password
5. Device connects and displays IP on OLED screen

### Sensor Installation

**Vibration Sensor (Example):**

1. Clean mounting surface on equipment
2. Apply thin layer of coupling compound (for best accuracy)
3. Mount sensor with stud or magnet base
4. Location recommendations:
   - Motors: Housing near drive end bearing
   - Pumps: Pump body near bearing
   - Gearboxes: Housing near gear mesh
   - General: Closest to rotating components

**Temperature Sensor (Example):**

1. Identify critical temperature measurement point
2. Mount sensor in contact with surface
3. Secure with thermal adhesive or mechanical clamp
4. Ensure good thermal contact for accurate readings
5. Locations: Bearing housings, motor bodies, hydraulic tanks

**Current Sensor (Example):**

1. Identify motor power leads
2. Clamp CT around single phase conductor
3. Do not clamp around bundled cable (measures net current = 0)
4. Arrow on CT indicates current flow direction
5. Secure CT to prevent movement

**Sensor Bus Wiring:**

1. Run 4-conductor shielded cable from Edge to first sensor
2. Connect to sensor terminal block:
   - Power+ (red)
   - Power- (black)
   - Data+ (green)
   - Data- (white)
3. For multiple sensors, daisy-chain from first to next
4. Maximum bus length: 100 meters total
5. Install 120Ω termination resistor at final sensor

**DIP Switch Addressing:**

1. Each sensor needs unique address (1-254)
2. Set via DIP switches on sensor module
3. Binary encoding: 00000001 = address 1, 00000010 = address 2, etc.
4. Document addresses for your reference

---

## Step 2: Initial Configuration (10-15 minutes)

### Access Web Interface

1. Note IP address from Edge device OLED display
2. Open web browser on computer connected to same network
3. Navigate to `https://[IP_ADDRESS]`
4. Accept self-signed certificate (first-time setup)
5. Default credentials: admin / esocore (change immediately)

### Device Configuration

**Network Settings:**

1. Navigate to Settings → Network
2. Configure static IP if required (optional, DHCP works for most)
3. Set DNS servers if needed
4. Configure NTP server for time synchronization (critical for data timestamps)

**Change Default Password:**

1. Navigate to Settings → Security
2. Change admin password to secure value
3. Document password securely

**Sensor Discovery:**

1. Navigate to Sensors → Discovery
2. Click "Scan Bus" button
3. System auto-discovers all connected sensors
4. Verify expected sensors appear in list
5. Assign descriptive names (e.g., "Motor 1 Bearing DE", "Pump Inlet Pressure")

**Sensor Configuration:**

1. Click on each sensor to configure
2. Set sampling rates:
   - Vibration: 1-3 kHz for analysis windows
   - Temperature: 1 Hz continuous
   - Current: 100-500 Hz
   - Pressure: 1-10 Hz
3. Configure measurement ranges if sensors have multiple options
4. Enable desired measurements (some sensors have multiple channels)

### Cloud Sync Configuration (Optional)

If using cloud platform for historical analytics:

1. Navigate to Settings → Cloud
2. Enter cloud platform URL
3. Enter device API key (from cloud provisioning)
4. Configure sync interval (recommend 5-15 minutes)
5. Click "Test Connection" to verify
6. Enable "Auto Sync" when ready

**Note:** Cloud sync is optional. Edge device operates fully independently with local storage and alerting.

---

## Step 3: Baseline Data Collection (Automatic)

### Understanding Baselines

EsoCore needs 2-4 weeks of normal operation data to establish baseline patterns for each machine. This is automatic—no interaction required, just let
it run.

**What's Happening:**

- Sensors continuously collect data
- Edge device processes and stores on local SD card
- Statistical baselines calculated for:
  - Vibration RMS and frequency spectra
  - Temperature normal operating ranges
  - Current signatures and load patterns
  - Pressure normal ranges and stability
- Seasonal and operational patterns identified
- Hour-of-day and day-of-week patterns recognized

**During Baseline Period:**

- Alerts are disabled (learning mode)
- Status dashboard shows live data
- Data is stored locally on SD card (30+ days capacity)
- Optional cloud sync uploads data for historical viewing
- OLED display shows "Baseline Mode" status

**After Baseline Period:**

- System automatically enables anomaly detection
- Alert thresholds configured based on learned baselines
- Monitoring transitions from passive to active mode
- You'll receive email notification when complete

### Monitoring Baseline Progress

1. Navigate to Dashboard
2. View "Baseline Status" widget
3. Shows percentage complete for each sensor
4. Green checkmarks appear when baseline is sufficient
5. Typically completes in 2-4 weeks depending on equipment operating patterns

**Accelerating Baseline Collection:**

- Ensure equipment operates in all typical modes
- Include startup and shutdown cycles
- Cover different load conditions if applicable
- Run through full operational range

---

## Step 4: View Live Data

While baseline collects, you can view live sensor data:

### Dashboard Overview

1. Navigate to Dashboard (home screen)
2. See tile for each monitored machine
3. Current values displayed for all sensors
4. Color coding indicates status:
   - Gray: Baseline mode (learning)
   - Green: Normal operation
   - Yellow: Minor deviation (watch)
   - Orange: Significant deviation (attention needed)
   - Red: Critical deviation (maintenance required)

### Sensor Detail View

1. Click on any sensor tile
2. View real-time waveforms (vibration, current)
3. See FFT spectra for frequency analysis
4. Historical trend charts (temperature, pressure)
5. Statistical metrics (RMS, peak, average, etc.)

### Time-Series Charts

1. Navigate to Analytics → Trends
2. Select sensor(s) to view
3. Choose time range (last hour, day, week, month)
4. Overlay multiple sensors for correlation
5. Zoom and pan to examine details
6. Export data as CSV if needed

### FFT Waterfall Display

For vibration sensors:

1. Navigate to Analytics → FFT Analysis
2. View waterfall display showing frequency content over time
3. Identify specific frequencies of interest
4. Compare to bearing and gear frequencies
5. Look for developing patterns

---

## Step 5: Configure Alerts (After Baseline)

Once baseline collection completes (2-4 weeks), configure alerting:

### Alert Thresholds

1. Navigate to Settings → Alerts
2. System suggests thresholds based on baseline:
   - Warning: 20% deviation from baseline
   - Attention: 40% deviation
   - Critical: 80% deviation
3. Adjust sensitivity based on your preferences:
   - More sensitive = earlier warnings, more false positives
   - Less sensitive = fewer alerts, potentially late warnings
4. Start with suggested values and tune based on experience

### Alert Methods

**Email Alerts:**

1. Navigate to Settings → Notifications → Email
2. Enter SMTP server details
3. Configure recipient list
4. Set alert severity levels to send (recommend critical + attention)
5. Test email delivery

**SMS Alerts (via SMTP-to-SMS gateway):**

1. Use carrier's email-to-SMS gateway
2. Configure as email recipient
3. Example: 5551234567@txt.att.net

**Local Alarm Output:**

1. Wire relay output to alarm light or horn
2. Configure trigger conditions
3. Test before relying on

**CMMS Integration:**

1. Navigate to Settings → Integrations → CMMS
2. Enter CMMS API endpoint
3. Configure authentication
4. Enable auto work order creation
5. Test integration

### Alert Rules

Create custom alert logic:

1. Navigate to Settings → Alert Rules
2. Click "New Rule"
3. Define conditions:
   - Sensor: Select from list
   - Metric: Choose parameter (RMS, temperature, etc.)
   - Condition: Threshold and duration
   - Example: "Vibration RMS > 8 m/s² for >5 minutes"
4. Set severity level
5. Assign notification recipients
6. Enable rule

---

## Step 6: First Maintenance Action

### When Alert Triggers

**Investigation Workflow:**

1. Review alert details:
   - Which sensor triggered?
   - What parameter exceeded threshold?
   - By how much?
   - How long has it been elevated?

2. Check correlated sensors:
   - Has temperature also increased?
   - Has current draw changed?
   - Are there acoustic changes?
   - Multiple symptoms = higher confidence

3. View historical trend:
   - Is this sudden or gradual?
   - When did deviation start?
   - What is rate of change?
   - Gradual = predictable failure, sudden = investigate cause

4. Plan maintenance action:
   - Schedule during next available maintenance window
   - Order replacement parts if needed
   - Prepare tools and resources
   - Document planned action

**Maintenance Execution:**

1. Perform identified maintenance (bearing replacement, etc.)
2. Note findings during maintenance
3. Verify issue was as predicted
4. Document in CMMS
5. Update EsoCore with maintenance record

**Post-Maintenance:**

1. Equipment returns to normal operation
2. Sensor values return to baseline
3. System recalculates baseline to include new component
4. Alert clears automatically
5. Document prevented failure value (avoided downtime and catastrophic damage)

---

## Step 7: Expand Monitoring

After success with first machine:

**Add More Sensors to Same Machine:**

1. Install additional sensor modules
2. Connect to RS-485 bus
3. System auto-discovers
4. Configure and start baseline

**Add Additional Machines:**

1. Install Edge device on next machine
2. Follow same setup process
3. Leverage learnings from first deployment
4. Standardize sensor packages by equipment type

**Fleet Analytics:**

1. With multiple machines monitored, compare performance
2. Identify outliers (best and worst performers)
3. Benchmark similar equipment
4. Share best practices across fleet

---

## Common Issues and Solutions

### Issue: Edge Device Won't Power On

**Troubleshooting:**

- Verify 24V DC polarity is correct
- Check power supply output voltage (should be 24V DC nominal)
- Check for blown fuse (if equipped)
- Power LED should be solid when powered

**Solution:** Verify power source, check polarity, test with known good supply

### Issue: Cannot Connect to Web UI

**Troubleshooting:**

- Verify device and computer on same network
- Check IP address on OLED display
- Try pinging device IP
- Disable firewall temporarily to test
- Clear browser cache

**Solution:** Use IP from OLED, ensure network connectivity, try different browser

### Issue: Sensors Not Discovered

**Troubleshooting:**

- Verify sensor power LED is illuminated
- Check RS-485 wiring (Data+, Data-, Power+, Power-)
- Verify shield is grounded at one end only
- Check DIP switch addresses are unique
- Try one sensor at a time to isolate issue
- Verify 120Ω termination resistor at bus end

**Solution:** Check wiring systematically, verify power at each sensor, test one at a time

### Issue: False Alerts After Baseline

**Troubleshooting:**

- Review alert threshold settings
- Check if equipment operation changed
- Verify sensors are securely mounted
- Look for new sources of vibration or noise
- Review baseline data quality

**Solution:** Increase alert thresholds slightly, extend baseline period, improve sensor mounting

### Issue: High Vibration Readings

**Note:** This might be real, not an issue!

**Investigation:**

- Compare to equipment specifications
- Check if readings correlate with equipment condition
- Verify sensor mounting is secure and proper
- Review installation location (on rigid structure, not flexible)
- Look for external vibration sources

**Solution:** If sensor installation is correct, this is likely detecting real issue—schedule inspection

---

## Next Steps

### Learn More

- **Full Documentation:** [www.esocore.com/docs](/docs)
- **Hardware Specifications:** [Edge device details](/docs/esocore-edge)
- **Sensor Guide:** [Sensor specifications](/docs/esocore-sensors)
- **API Documentation:** [REST API reference](/docs/api-specification)

### Expand Capabilities

- **Predictive Maintenance:** [Implementation guide](/docs/solutions/predictive-maintenance)
- **CNC Monitoring:** [Application-specific guide](/docs/industries/cnc-machine-monitoring)
- **Door Monitoring:** [Industrial door guide](/docs/industries/industrial-door-monitoring)
- **Integration Guide:** [Connect to existing systems](/docs/getting-started/integration-guide)

### Get Support

- **Community Forum:** GitHub Discussions
- **Issue Tracking:** GitHub Issues
- **Commercial Support:** support@newmatik.com
- **Professional Services:** consulting@newmatik.com

### Best Practices

- Start with 1-2 machines to learn system
- Document sensor locations and addresses
- Take photos of installations for reference
- Keep spare sensors on hand
- Review dashboard weekly during first month
- Tune alert thresholds based on experience
- Document prevented failures for ROI tracking

---

## Success Checklist

After completing this guide, you should have:

- [ ] Edge device installed and powered
- [ ] Sensors mounted on equipment
- [ ] RS-485 bus wired correctly
- [ ] Network connectivity established
- [ ] Web UI accessible
- [ ] Default password changed
- [ ] Sensors discovered and named
- [ ] Sampling rates configured
- [ ] Baseline collection running
- [ ] Dashboard showing live data
- [ ] Alert thresholds configured (or will configure after baseline)
- [ ] Notification methods configured
- [ ] Documentation created for installation

---

Congratulations! You've completed your first EsoCore deployment. Over the next 2-4 weeks, the system will learn your equipment's normal behavior and
begin detecting developing issues. You're now on the path to predictive maintenance and reduced downtime.

**Questions?** Join our community discussions or contact support@newmatik.com

[View Full Documentation](/docs) | [Installation Guide](/docs/getting-started/installation-guide) | [Get Support](https://github.com/newmatik/EsoCore/issues)

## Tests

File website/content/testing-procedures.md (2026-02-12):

# Testing & Validation Procedures

This document defines the comprehensive testing procedures, validation protocols, and acceptance criteria for the EsoCore edge-to-cloud monitoring
system.

---

## Testing Categories

### Unit Tests (Firmware)

- **Sensor drivers**: Individual sensor initialization, reading, and error handling
- **CRC calculations**: Data integrity verification algorithms
- **File rotation**: SD card file management and rotation logic
- **Clock drift**: RTC accuracy and NTP synchronization
- **Event logging**: System event capture and formatting
- **Safety I/O**: Dual-channel input cross-monitoring, safety relay and SSR output control and feedback

### Hardware-in-Loop (HIL) Testing

#### Vibration Testing

- **Shaker table**: Controlled vibration patterns for accelerometer validation
- **Frequency response**: 1-3 kHz sampling validation
- **Amplitude accuracy**: Calibration verification across operating range

#### Motor Testing

- **Motor rig**: Programmable load for torque/current mapping
- **Current sensor calibration**: Verify torque proxy accuracy
- **Drive simulation**: Various motor types and operating conditions

### Safety I/O Testing

- **Dual-channel input verification**: Confirm all 6 safety input channels read consistently across both optocouplers (Channel A and
  Channel B); verify cross-monitoring detects injected mismatch within <10 ms
- **Stuck-at fault detection**: Verify periodic test pulses identify inputs stuck high or low
- **Safety relay verification**: Confirm dual-channel relay (G7SA-2A2B-DC24) correct energize/de-energize behavior
- **SSR output testing**: Verify AQY212EHAZ solid-state relay switching and load handling
- **Feedback monitoring**: Verify relay feedback signals match commanded state
- **Coil driver testing**: Verify DRV110APWR driver economization and contact monitoring
- **Safe state enforcement**: Verify cross-monitor fault triggers de-energization of safety relay within response time budget

### Power Management Testing

#### Supercapacitor Testing

- **Charge/discharge cycles**: Verify 50,000+ cycle capability
- **Temperature range**: Test -40°C to +65°C operation
- **Safe shutdown timing**: Confirm ≥30 second runtime capability
- **Voltage monitoring**: Verify accurate power level detection

#### Brownout Detection

- **Voltage threshold testing**: Verify early warning system
- **Graceful degradation**: Test system behavior during voltage sags
- **Recovery procedures**: Validate system restart after power restoration

### Sync & Connectivity Testing

#### Soak Tests

- **Packet loss simulation**: Various network conditions
- **Long offline periods**: 72+ hour disconnection testing
- **Power-loss during write**: Data integrity during unexpected shutdowns
- **Network quality variations**: Different bandwidth and latency conditions

#### Event Simulation Tests

- **Network disconnection**: Controlled connectivity loss scenarios
- **Power cycling**: Repeated power on/off sequences
- **Server failures**: Backend unavailability simulation
- **SD card errors**: Storage failure and recovery testing
- **Safety activations**: Triggered safety events during operation

### Workflow Automation Testing

- **Alert triggering**: Verify notification system responsiveness
- **Escalation timers**: Test time-based escalation chains
- **Notification delivery**: Confirm email, SMS, and webhook delivery
- **Event correlation**: Validate cascading event detection

### Security Testing

- **Key revocation**: Authentication key invalidation procedures
- **TLS downgrade resistance**: Protocol security validation
- **OTA rollback**: Firmware update failure recovery
- **Tamper detection**: Physical security monitoring
- **Authentication bypass attempts**: Security penetration testing

### Cloud Platform Testing

- **API idempotency**: Duplicate request handling verification
- **Partition pruning**: Database performance optimization
- **RBAC**: Role-based access control validation
- **Multi‑tenant leakage checks**: Data isolation verification

---

## Acceptance Criteria

### Performance Requirements

- **Offline tolerance**: Device tolerates 72 h offline and fully backfills within 6 h at 10 Mbps
- **Data integrity**: Data loss < 0.01% over 30‑day soak with 10 forced reboots/day
- **Clock accuracy**: Clock error < ±2 s/day with daily NTP; server corrects within ±500 ms on ingest if requested
- **OTA reliability**: OTA success rate > 99.5% across 50 devices/staged rollout

### Event System Requirements

- **Event logging**: All system events captured and transmitted within 30 s of connectivity restoration
- **Safety I/O**: Dual-channel input cross-monitoring verified; safety relay energize/de-energize cycles verified; relay feedback
  consistent with commanded state; response time <10 ms confirmed
- **Power management**: Supercap provides ≥30s safe shutdown time; graceful shutdown completes in <20s
- **Safe shutdown reliability**: 100% data integrity during 1000+ simulated power loss events

### Automation Requirements

- **Workflow automation**: Critical events trigger notifications within 60 s; escalation rules function correctly
- **Event correlation**: Detect and report cascading failure patterns across device fleet

---

## Test Environments

### Development Environment

- **Hardware**: Development boards with debug interfaces
- **Software**: JTAG debuggers, logic analyzers, oscilloscopes
- **Network**: Controlled network conditions with packet injection
- **Load simulation**: Door movement simulators and motor test rigs

### Staging Environment

- **Production hardware**: Final hardware revision testing
- **Real doors**: 5-10 pilot door installations
- **Network diversity**: Various connectivity types (dual Ethernet, Wi-Fi)
- **Environmental conditions**: Temperature and humidity variations

### Production Environment

- **Fleet testing**: Staged rollout across device population
- **Monitoring**: Real-time performance and reliability tracking
- **Customer feedback**: User acceptance and satisfaction metrics

---

## Validation Protocols

### Functional Validation

1. **Sensor accuracy**: Compare readings against calibrated reference instruments
2. **Event detection**: Verify proper categorization and logging of system events
3. **Safety response**: Validate safety system response times and reliability
4. **Communication protocols**: Test all API endpoints and data formats

### Performance Validation

1. **Throughput testing**: Maximum data processing and transmission rates
2. **Latency measurement**: End-to-end response times for critical events
3. **Resource utilization**: CPU, memory, and storage usage optimization
4. **Battery/supercap life**: Power consumption and backup duration testing

### Reliability Validation

1. **MTBF calculation**: Mean time between failures across device fleet
2. **Failure mode analysis**: Comprehensive failure scenario testing
3. **Recovery procedures**: Automatic and manual recovery validation
4. **Data consistency**: Verification of data integrity across system restarts

### Security Validation

1. **Penetration testing**: External security audit and vulnerability assessment
2. **Encryption validation**: TLS implementation and key management testing
3. **Access control**: Authentication and authorization mechanism verification
4. **Data privacy**: Compliance with GDPR, HIPAA, and industry standards

---

## Quality Assurance Metrics

### Reliability Metrics

- **Device uptime**: >99.9% operational availability
- **False positive rate**: <5% for maintenance alerts
- **False negative rate**: <1% for safety-critical events
- **Mean time to repair**: <2 hours for critical issues

### Performance Metrics

- **Response time**: <1 second for anomaly detection
- **Data transmission efficiency**: >90% reduction through intelligent filtering
- **Network utilization**: Optimized bandwidth usage
- **Storage efficiency**: Effective use of local SD card capacity

### User Experience Metrics

- **Setup time**: <30 minutes for device installation and configuration
- **Dashboard responsiveness**: <3 seconds for data visualization loading
- **Alert relevance**: >95% of alerts result in actionable maintenance
- **Customer satisfaction**: >90% positive feedback on system effectiveness

---

## Certification & Compliance Testing

### Safety Certifications

- **EN ISO 13849** functional safety compliance for dual-channel safety digital inputs
- **EN 60204-1** electrical safety compliance

### EMC Testing

- **EN 61000-6-2/-6-4** electromagnetic compatibility
- **IEC 61000-4-2/-4-4/-4-5** immunity and emissions testing

### Environmental Testing

- **Operating temperature**: -20°C to +60°C validation
- **Humidity resistance**: 5-95% RH non-condensing
- **Vibration resistance**: Industrial environment simulation
- **IP rating verification**: IP54-IP65 enclosure protection

---

## Continuous Integration & Testing

### Automated Testing Pipeline

1. **Code commit triggers**: Automatic test execution on code changes
2. **Unit test suite**: Comprehensive firmware and software testing
3. **Integration tests**: End-to-end system validation
4. **Performance benchmarks**: Automated performance regression detection

### Quality Gates

- **Code coverage**: >90% test coverage requirement
- **Static analysis**: Zero critical security vulnerabilities
- **Performance regression**: <5% performance degradation tolerance
- **Documentation**: Complete test documentation and traceability

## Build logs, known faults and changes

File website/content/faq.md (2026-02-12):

# Frequently Asked Questions

Common questions about EsoCore, the open-source industrial IoT platform for predictive maintenance and equipment monitoring.

---

## General Questions

### What is EsoCore?

EsoCore is an open-source industrial IoT platform designed for comprehensive equipment monitoring and predictive maintenance in manufacturing
environments. The platform combines edge computing with machine learning to deliver real-time insights into machine health, preventing costly downtime
and optimizing maintenance schedules. EsoCore provides everything needed for modern factory automation: modular sensor modules, edge intelligence,
cloud infrastructure, and seamless integration with existing industrial control systems.

### Is EsoCore really free?

Yes. EsoCore is fully open source under the Apache 2.0 License, which means you can use it commercially, modify it, distribute it, and integrate it
into proprietary systems without paying licensing fees. All hardware designs, firmware source code, and cloud platform components are freely
available. While the core platform is free, optional commercial services like managed cloud hosting, enterprise support, and custom development are
available from Newmatik and partners.

### How does EsoCore differ from proprietary industrial IoT platforms?

EsoCore differentiates itself through complete transparency, vendor independence, and customization freedom. Unlike proprietary platforms, you own the
entire technology stack and can modify it for your specific needs. There are no per-device fees, no forced cloud subscriptions, and no vendor lock-in.
You can deploy on-premises, integrate with any cloud provider, or use the optional managed service. The open-source model also means continuous
community-driven improvements and the ability to fork the project if your needs diverge from the main development path.

### Who develops and maintains EsoCore?

EsoCore is developed and maintained by Newmatik, a European electronics and software company with extensive experience in industrial automation.
Development follows a collaborative partnership model where strategic partners contribute to the platform while maintaining independence. The entire
platform is open source, enabling community contributions and ensuring long-term sustainability beyond any single company.

### What industries and applications is EsoCore designed for?

EsoCore serves diverse industrial applications including CNC machine monitoring, industrial door systems, injection molding equipment, conveyor
systems, packaging lines, pumps, compressors, motors, and general manufacturing equipment. Any industrial machinery that requires condition
monitoring, predictive maintenance, or safety compliance can benefit from EsoCore. The modular sensor architecture enables customization for
industry-specific requirements.

---

## Technical Questions

### What hardware does EsoCore require?

EsoCore consists of an Edge device (STM32H747-based industrial controller) and modular RS-485 sensor modules. The Edge device handles data processing,
cloud connectivity, and fieldbus integration. Sensor modules connect via industrial RS-485 bus and include vibration sensors, temperature sensors,
acoustic sensors, current sensors, pressure sensors, and more. Reference hardware designs are open source, allowing partners to manufacture devices or
customize for specific applications.

### Can EsoCore work offline without cloud connectivity?

Yes. Edge intelligence is a core design principle. The Edge device processes sensor data locally using TinyML models for anomaly detection, stores
data on industrial SD cards, and continues monitoring even during network outages. Local buffering supports 30+ days of offline operation with
automatic sync when connectivity returns. Critical alerts can be delivered via local fieldbus integration or on-device displays without requiring
cloud connectivity.

### What programming languages and frameworks does EsoCore use?

The firmware is built on Zephyr RTOS using C for embedded systems programming. The cloud platform uses Django REST Framework (Python) for the backend
API and Nuxt.js (Vue.js/TypeScript) for the frontend portal. All components follow modern development practices with comprehensive documentation,
making it accessible to developers familiar with these widely-used technologies.

### Does EsoCore support existing industrial protocols?

Yes. EsoCore natively supports Modbus RTU/TCP, PROFIBUS DP, and PROFINET Device protocols, enabling seamless integration with PLCs, SCADA systems, and
existing factory automation infrastructure. The platform also provides REST APIs for modern web-based integrations and can be extended to support
additional protocols as needed.

### How does edge AI and TinyML work in EsoCore?

EsoCore runs lightweight machine learning models directly on the STM32 microcontroller using TensorFlow Lite Micro. Models are optimized to fit in
<16KB of flash memory while providing real-time anomaly detection with <100ms inference latency. This enables immediate response to equipment issues
without cloud round-trip delays. Models can be updated over-the-air as equipment behavior changes or new failure modes are identified.

### What sensors are supported?

EsoCore supports a comprehensive sensor suite including 3-axis vibration sensors, acoustic sensors (audible and ultrasonic), temperature sensors (NTC,
RTD, thermocouple, IR), pressure sensors, current sensors, air quality sensors, light sensors, oil quality sensors, and proximity/position sensors.
The modular RS-485 architecture allows new sensor types to be added without redesigning the Edge hardware. Partners can develop proprietary sensor
modules for specific applications.

### Can I add custom sensors to EsoCore?

Absolutely. The RS-485 sensor bus architecture is specifically designed for extensibility. You can develop custom sensor modules with local MCUs that
communicate via the standardized protocol. These can be proprietary sensors for competitive advantages, industry-specific sensors, or experimental
sensor types. The Edge device auto-discovers new sensors and their capabilities at runtime without firmware changes.

---

## Deployment and Integration Questions

### How long does it take to deploy EsoCore?

Initial pilot deployments typically take 1-2 days for hardware installation and basic configuration. The modular design enables rapid expansion—adding
monitoring to additional machines can be accomplished in hours rather than weeks. Cloud platform deployment takes 2-4 hours for self-hosted
installations or is immediate with managed hosting. Most organizations achieve full production deployment within 2-4 weeks including integration with
existing systems.

### Can EsoCore integrate with my existing MES, SCADA, or ERP systems?

Yes. EsoCore provides multiple integration pathways: industrial fieldbus protocols (Modbus, PROFIBUS, PROFINET) for SCADA integration, comprehensive
REST APIs for MES/ERP integration, and webhook support for event-driven workflows. The open-source nature enables custom integrations for proprietary
systems. Documentation includes integration examples and best practices for common industrial software platforms.

### Does EsoCore require changes to my existing machinery?

No. EsoCore is designed for non-invasive deployment. Sensors mount externally or connect to existing measurement points without modifying machine
internals. The system monitors and augments existing control systems rather than replacing them.

### What network infrastructure does EsoCore need?

EsoCore features dual Ethernet ports with physical network separation (Port A for machine/OT protocols, Port B for IT/cloud) and optional Wi-Fi
connectivity. Recommended deployment uses the dual Ethernet ports for reliability and security, but Wi-Fi works well for retrofit installations. The
Edge device uses two IP addresses (one per Ethernet port) and operates on standard factory networks. Firewall configuration is minimal -- outbound
HTTPS on Port B for cloud sync and optional inbound HTTPS on Port A for the on-device web UI. The platform is designed for industrial network
environments with intermittent connectivity and powered by a dedicated 24 V DC supply.

### Can I run EsoCore entirely on-premises without cloud services?

Yes. The Django backend can be deployed on-premises providing all data management, analytics, and API functionality without external cloud
dependencies. Local deployment ensures complete data sovereignty and eliminates internet connectivity requirements. The platform architecture
separates edge, backend, and frontend components allowing flexible deployment topologies including air-gapped installations for sensitive
environments.

---

## Predictive Maintenance and ROI Questions

### How does predictive maintenance reduce costs?

Predictive maintenance shifts from reactive (repair after failure) or time-based (scheduled regardless of condition) to condition-based maintenance.
This reduces unplanned downtime by 30-50%, extends equipment lifespan by 20-40%, and reduces maintenance costs by 20-30% according to industry
studies. EsoCore enables this by continuously monitoring equipment health and alerting you to developing issues before they cause failures, allowing
planned maintenance during scheduled downtime rather than emergency repairs during production hours.

### What is the typical ROI for industrial IoT monitoring?

ROI varies by application but typically ranges from 200-400% within the first year. A single avoided unplanned outage on critical production equipment
often pays for the monitoring system. Additional value comes from extended equipment life, reduced spare parts inventory, optimized maintenance
schedules, and improved operational efficiency. The open-source nature of EsoCore reduces upfront costs compared to proprietary platforms, improving
ROI further.

### How accurate is the anomaly detection?

EsoCore's TinyML models achieve >95% accuracy in identifying bearing faults, motor imbalances, and mechanical anomalies on test datasets. False
positive rates are typically <5% for maintenance alerts and <1% for safety-critical events. Models improve over time through federated learning as
more data is collected across the fleet. The system provides confidence scores with each prediction allowing you to tune sensitivity for your specific
risk tolerance.

### Can EsoCore replace my existing maintenance program?

EsoCore augments rather than replaces traditional maintenance programs. It enables the transition from time-based to condition-based maintenance while
maintaining required regulatory inspections and OEM-recommended service intervals. The system helps prioritize maintenance activities, optimize spare
parts inventory, and provide data-driven justification for maintenance decisions. Most organizations use EsoCore to reduce unnecessary preventive
maintenance while preventing unexpected failures.

---

## Security and Compliance Questions

### Is open-source software secure for industrial applications?

Yes. Open-source software often provides superior security because the code is transparently auditable by security researchers and the community.
EsoCore follows security best practices including TLS encryption, signed firmware updates, device authentication, and secure boot. The Apache 2.0
License includes patent protection. Regular security updates are provided by Newmatik and the open-source community can contribute security
improvements. Many critical industrial and government systems rely on open-source components.

### How does EsoCore handle data privacy?

EsoCore provides complete data ownership and control. Edge processing keeps sensitive data on-device with only aggregated metrics transmitted to the
cloud. You control what data leaves your premises. On-premises deployment options provide complete data sovereignty. The platform is designed to
support GDPR, HIPAA, and other data protection regulations. No data is shared with third parties without your explicit configuration and consent.

### What security certifications does EsoCore have?

The hardware designs follow EN 61000 for EMC compliance and EN 60204-1 for electrical safety. The platform architecture supports security best
practices aligned with IEC 62443 for industrial automation security. As an open-source platform, individual deployments can pursue necessary
certifications for their specific regulatory requirements. Newmatik provides certification support services for partners requiring specific compliance
documentation.

### Can EsoCore be used in safety-critical applications?

EsoCore includes 6 dual-channel safety digital inputs compliant with EN ISO 13849 Category 3 architecture. Each input uses two independent
optocouplers with firmware cross-monitoring, providing Performance Level d (PLd) safety integrity. Combined with the dual-channel safety relay
output (G7SA-2A2B-DC24), EsoCore can serve as part of a safety chain for applications such as emergency stop monitoring, light curtain
integration, and safety door sensing. Always consult with safety engineers and perform a risk assessment for your specific application.

---

## Cost and Licensing Questions

### How much does EsoCore cost?

The core EsoCore platform (software, firmware, and hardware designs) is free under the Apache 2.0 License. Hardware costs depend on your deployment
size and sensor requirements—typical installations range from $500-2000 per monitored machine for hardware. Optional commercial services include
managed cloud hosting ($10-50/device/month), enterprise support contracts, custom development, and certification assistance. Unlike proprietary
platforms, there are no per-device licensing fees or forced subscription models.

### Are there ongoing costs after initial deployment?

Ongoing costs depend on your deployment model. Self-hosted installations have minimal operating costs (server hosting and maintenance). Managed cloud
hosting has per-device fees but eliminates infrastructure management overhead. There are no mandatory licensing fees, but you may choose optional
support contracts or software updates services. The open-source nature means you are never locked into ongoing payments—you can switch from managed to
self-hosted at any time.

### Can I sell products based on EsoCore?

Yes. The Apache 2.0 License explicitly permits commercial use, modification, and distribution. You can build products on EsoCore, sell them under your
own brand, and add proprietary features without sharing your modifications. Many partners use EsoCore as the foundation for industry-specific
solutions. The license only requires attribution—you must include the Apache 2.0 License notice in your product documentation.

### What happens if Newmatik stops supporting EsoCore?

The open-source nature provides protection against vendor abandonment. All source code, hardware designs, and documentation are publicly available,
enabling the community or any organization to continue development. The Apache 2.0 License allows anyone to fork the project and maintain it
independently. Partners can establish their own support and development capabilities. This is fundamentally different from proprietary platforms where
vendor decisions directly impact your ability to maintain your systems.

---

## Getting Started Questions

### How do I get started with EsoCore?

Start by exploring the comprehensive documentation at [www.esocore.com/docs](/docs). The [Quick Start Guide](/docs/getting-started/quick-start) walks
through initial setup and your first sensor deployment. For pilot projects, we recommend starting with 1-3 monitored machines to validate the approach
before facility-wide deployment. Newmatik and partners offer pilot program support including hardware, installation assistance, and training. The
GitHub repository contains all source code and reference designs.

### Do I need specialized skills to deploy EsoCore?

Basic industrial automation knowledge is helpful but not required. The system is designed for deployment by maintenance technicians with guidance from
the documentation. For custom development, firmware modifications require embedded systems programming skills (C/Zephyr RTOS), while cloud
customization uses widely-known technologies (Python/Django, Vue.js). Most organizations successfully deploy standard configurations without custom
development. Newmatik offers training and professional services for complex deployments.

### Where can I get hardware and sensors?

Reference hardware designs are open source, enabling manufacturing by partners or your preferred contract manufacturer. Newmatik offers pre-built
hardware for evaluation and production deployments. Several partners provide certified hardware with regional support. Because the designs are open,
you are never dependent on a single source for hardware—you can manufacture it yourself, use multiple suppliers, or switch vendors without platform
lock-in.

### Is there a demo or trial available?

Yes. Virtual demos are available showing the cloud platform interface, dashboard analytics, and alert workflows. Newmatik and partners offer
evaluation hardware for pilot deployments, typically 30-90 day trials with 1-3 edge devices and sensor kits. The open-source nature means you can also
set up your own evaluation environment using the source code and off-the-shelf development boards before committing to production hardware.

### What support is available?

Community support is available through GitHub discussions and issue tracking. The comprehensive documentation covers most common deployment scenarios.
Newmatik offers commercial support contracts with guaranteed response times, priority bug fixes, and direct engineering consultation. Partners provide
regional support services tailored to specific industries. Because the platform is open source, you can also hire independent consultants or build
internal expertise without vendor dependency.

---

## Comparison Questions

### How does EsoCore compare to MachineMetrics?

MachineMetrics is a mature proprietary platform focused on production monitoring and OEE optimization for CNC machines. EsoCore differentiates through
open-source licensing (no vendor lock-in), edge-first TinyML architecture (lower latency, offline operation), integrated relay outputs for
interlocking, and cross-domain capability (doors, CNC, and general equipment on one platform). MachineMetrics offers more polished UI and established
customer base, while EsoCore provides customization freedom and lower total cost of ownership.

### How does EsoCore compare to Senseye?

Senseye (Siemens) is an enterprise-focused predictive maintenance platform emphasizing advanced AI/ML analytics for mixed equipment fleets. EsoCore
differentiates through embedded edge intelligence (vs cloud-centric), open-source flexibility (vs proprietary), and integrated hardware-software
solution (vs software-only). Senseye excels at large enterprise deployments with existing IoT infrastructure, while EsoCore provides complete
edge-to-cloud solution with more accessible pricing for mid-market manufacturers.

### How does EsoCore compare to proprietary OEM monitoring solutions?

OEM-specific solutions (like ASSA ABLOY Insight for doors or Fanuc FIELD for CNC machines) provide tight integration with specific equipment but lack
cross-platform capability. EsoCore enables monitoring diverse equipment types on a single platform, avoiding the complexity and cost of managing
multiple vendor solutions. The open-source nature provides insurance against vendor decisions, pricing changes, or product discontinuation. OEM
solutions excel at equipment-specific optimization, while EsoCore provides facility-wide visibility and vendor independence.

### Can I migrate from another IoT platform to EsoCore?

Yes. The open architecture and standard protocols facilitate migration from proprietary platforms. The REST API enables data import from existing
systems. The modular design allows gradual migration—new equipment deployed with EsoCore while legacy systems remain operational. Complete
documentation of data formats and protocols simplifies integration projects. Many organizations run EsoCore alongside existing systems during
transition periods.

---

## Advanced Technical Questions

### Can I modify the firmware or hardware designs?

Absolutely. The Apache 2.0 License explicitly grants modification rights. All firmware source code, hardware schematics, PCB layouts, and component
bills of materials are publicly available. You can modify for your specific needs, fix bugs, add features, or adapt for novel applications.
Modifications can remain proprietary or be contributed back to the community. The modular architecture makes targeted modifications feasible without
understanding the entire codebase.

### Does EsoCore support federated learning?

Yes. The platform architecture supports federated learning where models improve across the fleet without sharing raw sensor data. Each edge device can
participate in distributed training while keeping sensitive data on-premises. Updated models are validated and distributed via OTA updates. This
approach provides the benefits of fleet-wide intelligence while maintaining data privacy and regulatory compliance.

### Can EsoCore handle high-frequency data acquisition?

Yes. The vibration sensors support sampling rates up to 3kHz for detailed mechanical analysis. The Edge device includes dedicated signal processing
for FFT analysis, bandpass filtering, and statistical computations. High-frequency data is processed locally with only aggregated metrics transmitted
to the cloud, preventing bandwidth saturation. The firmware architecture prioritizes real-time data acquisition over other tasks to ensure
deterministic latency.

### How does the OTA update mechanism work?

Firmware updates use A/B partition scheme with signed images (Ed25519 or ECDSA signatures). The Edge device downloads, verifies, and installs updates
to the inactive partition, then reboots to test new firmware. Automatic rollback occurs if the new firmware fails health checks. Staged rollouts
(5%/25%/100%) prevent fleet-wide issues. The entire update process is designed for industrial reliability with fail-safe mechanisms and minimal
downtime.

---

## Contact and Community

### How do I contribute to EsoCore?

Contributions are welcome through the GitHub repository. Start by reviewing the contribution guidelines, opening issues for bugs or feature requests,
and submitting pull requests for improvements. The project follows standard open-source governance with code review and testing before merging.
Documentation improvements, test cases, and use case examples are especially valuable. Join the community discussions to connect with other developers
and users.

### How do I report security vulnerabilities?

Security issues should be reported privately to security@newmatik.com rather than public GitHub issues. We follow responsible disclosure practices
with acknowledgment within 48 hours and patches typically available within 7-14 days depending on severity. Security researchers who report valid
vulnerabilities are credited in release notes (with permission).

### Are there partnerships or collaboration opportunities?

Yes. Newmatik actively seeks strategic partners for industry-specific customizations, regional distribution, and application development. The
collaborative partnership model enables shared platform development costs while maintaining partner independence. Contact partnerships@newmatik.com
for opportunities. The open-source license also permits independent commercial activities without formal partnership agreements.

### Where can I get professional services and training?

Newmatik offers professional services including custom development, system integration, certification support, and operator training. Regional
partners provide localized support and services. Because the platform is open source, you can also engage independent consultants or system
integrators familiar with the technologies. Training materials and documentation are publicly available for self-service learning.

---

## Additional Resources

For more information about EsoCore:

- **Documentation**: [Complete technical documentation](/docs)
- **GitHub Repository**: [Source code and hardware designs](https://github.com/newmatik/EsoCore)
- **Getting Started**: [Quick start guide](/docs/getting-started/quick-start)
- **Hardware Specifications**: [Edge device](/docs/esocore-edge) and [Sensor modules](/docs/esocore-sensors)
- **API Documentation**: [REST API specification](/docs/api-specification)
- **Business Information**: [Partnership model](/docs/business-model-and-partnerships)

Have a question not answered here? Contact us or open a discussion on GitHub.

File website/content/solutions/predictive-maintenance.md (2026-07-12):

# Predictive Maintenance with EsoCore

Transform your maintenance strategy from reactive firefighting to proactive equipment health management with EsoCore's comprehensive predictive
maintenance system. Reduce unplanned downtime by up to 50%, extend equipment lifespan by 20-40%, and decrease maintenance costs by 20-30% through
data-driven decision making.

---

## What is Predictive Maintenance?

Predictive maintenance is a proactive maintenance strategy that monitors equipment condition in real-time to predict when maintenance should be
performed. This approach minimizes both unexpected equipment failures and unnecessary preventive maintenance, optimizing maintenance schedules based
on actual equipment condition rather than arbitrary time intervals or reactive responses to breakdowns.

Unlike reactive maintenance (fix it when it breaks) or preventive maintenance (fix it on a schedule), predictive maintenance uses continuous
monitoring and advanced analytics to detect developing problems early. This enables planned maintenance during scheduled downtime, avoiding emergency
repairs during production hours and preventing cascading failures that damage related equipment.

### Traditional Maintenance Approaches

**Reactive Maintenance:**

- Fix equipment only after it fails
- Results in unplanned downtime and production losses
- Often requires emergency repairs at premium costs
- May cause cascading damage to related components
- Typical downtime: 24-72 hours for repairs and parts ordering

**Preventive Maintenance:**

- Service equipment on fixed time intervals
- Prevents some failures but replaces parts prematurely
- Does not account for actual equipment condition
- Can miss developing issues between service intervals
- Results in unnecessary maintenance costs and parts waste

**Predictive Maintenance:**

- Monitor equipment continuously to detect developing issues
- Schedule maintenance based on actual condition
- Optimize service intervals for each specific machine
- Prevent failures while minimizing unnecessary maintenance
- Reduce unplanned downtime by 30-50%

---

## How EsoCore Enables Predictive Maintenance

EsoCore provides a complete predictive maintenance solution combining industrial-grade sensors, edge intelligence, and analytics infrastructure:

### Continuous Condition Monitoring

Monitor critical equipment parameters 24/7 with comprehensive sensor coverage:

**Mechanical Health:**

- 3-axis vibration analysis for bearing condition, shaft alignment, and mechanical imbalance
- Acoustic monitoring (audible and ultrasonic) for detecting leaks, friction, and tool wear
- Position and proximity sensors for detecting play, wear, and alignment issues

**Thermal Monitoring:**

- Spot temperature measurements for bearings, gearboxes, and motors
- Thermal imaging for hot spots and cooling system performance
- Temperature trend analysis for detecting developing thermal issues

**Electrical Monitoring:**

- Motor current signature analysis for electrical and mechanical faults
- Power quality monitoring for detecting supply issues
- Load monitoring for detecting abnormal operating conditions

**Process Parameters:**

- Pressure monitoring for hydraulic and pneumatic systems
- Flow monitoring for detecting restrictions and leaks
- Oil quality monitoring for lubrication system health

### Edge-Based Anomaly Detection

Process sensor data locally using TinyML models running directly on industrial edge devices:

**Real-Time Analysis:**

- <100ms inference latency for immediate anomaly detection
- Continuous operation even during network outages
- Local alert generation without cloud dependency

**Pattern Recognition:**

- Bearing fault detection with >95% accuracy
- Motor imbalance and misalignment identification
- Abnormal operating pattern recognition

**Adaptive Thresholds:**

- Learn normal operating baselines for each machine
- Detect gradual degradation trends
- Adjust sensitivity based on operational context

### Comprehensive Analytics

Cloud-based analytics provide deep insights into equipment health and maintenance optimization:

**Trend Analysis:**

- Long-term degradation tracking
- Seasonal and operational pattern identification
- Comparative analysis across equipment fleet

**Failure Prediction:**

- Remaining useful life estimation
- Probability-based maintenance scheduling
- Risk assessment and prioritization

**Maintenance Optimization:**

- Service interval recommendations based on actual condition
- Spare parts inventory optimization
- Maintenance crew scheduling and resource allocation

---

## Implementation Strategy

### Phase 1: Assessment and Planning (Week 1-2)

Identify critical equipment and failure modes that impact your operations:

1. **Equipment Inventory**: Document all production-critical equipment
2. **Failure Mode Analysis**: Identify common failure modes and their costs
3. **Priority Ranking**: Rank equipment by downtime impact and monitoring ROI
4. **Sensor Planning**: Determine required sensors for each failure mode
5. **Integration Planning**: Plan integration with existing maintenance systems

**Deliverable**: Implementation roadmap with prioritized equipment list and ROI projections

### Phase 2: Pilot Deployment (Week 3-6)

Deploy monitoring on 1-3 critical machines to validate the approach:

1. **Sensor Installation**: Mount sensors and edge devices on selected equipment
2. **Baseline Collection**: Gather 2-4 weeks of normal operating data
3. **Model Training**: Configure anomaly detection models for specific equipment
4. **Alert Tuning**: Adjust thresholds to minimize false positives
5. **Integration Testing**: Validate integration with maintenance workflows

**Deliverable**: Operational monitoring system with validated alert accuracy

### Phase 3: Expansion (Week 7-12)

Scale monitoring across facility based on pilot learnings:

1. **Staged Rollout**: Deploy monitoring in phases by equipment type or area
2. **Process Integration**: Integrate alerts with CMMS and work order systems
3. **Training**: Train maintenance staff on system use and alert response
4. **Optimization**: Refine models based on caught issues and false positives
5. **Documentation**: Document procedures and lessons learned

**Deliverable**: Facility-wide monitoring with established maintenance workflows

### Phase 4: Optimization (Month 4+)

Continuously improve predictive accuracy and maintenance processes:

1. **Model Refinement**: Update ML models based on verified failure events
2. **Process Improvement**: Optimize maintenance scheduling and resource allocation
3. **Expansion**: Add monitoring for additional failure modes and equipment types
4. **Analytics**: Leverage historical data for deeper insights and planning
5. **Benchmarking**: Track improvements in downtime, costs, and reliability

**Deliverable**: Mature predictive maintenance program with measurable ROI

---

## ROI and Business Case

### Downtime Reduction

Unplanned downtime is the largest cost driver in manufacturing operations:

**Typical Downtime Costs:**

- Production losses: $10,000-100,000+ per hour depending on operation
- Emergency repair premiums: 2-3x normal maintenance costs
- Rush parts ordering: Expedited shipping and premium pricing
- Quality issues: Scrap and rework from degraded equipment
- Safety incidents: Injuries from catastrophic equipment failures

**EsoCore Impact:**

- 30-50% reduction in unplanned downtime
- 50-70% reduction in catastrophic failures
- 20-30% reduction in overall maintenance costs
- 15-25% improvement in equipment utilization

**Example**: A CNC machining center experiences 20 hours of unplanned downtime per year at $15,000/hour cost = $300,000 annual loss. With 40%
reduction, save $120,000 annually. EsoCore investment: $2,000 hardware + $500 annual software = <1 month payback.

### Maintenance Cost Optimization

Move from time-based to condition-based maintenance:

**Reduced Costs:**

- Eliminate premature component replacements (20-40% reduction)
- Optimize parts inventory (15-30% reduction in carrying costs)
- Reduce emergency maintenance (50-70% reduction in premium labor costs)
- Extend equipment lifespan (20-40% longer service life)

**Improved Efficiency:**

- Better maintenance crew scheduling and resource utilization
- Reduced mean time to repair through faster fault diagnosis
- Fewer repeat failures through root cause identification
- Optimized service intervals based on actual wear patterns

### Quality and Production Benefits

Equipment condition directly impacts product quality:

**Quality Improvements:**

- Reduced scrap and rework from degraded equipment
- Consistent production output and dimensional accuracy
- Early detection of tool wear and process drift
- Prevention of cascading failures that cause quality issues

**Production Benefits:**

- Increased equipment availability and utilization
- Scheduled maintenance during planned downtime
- Faster changeovers with better equipment condition
- Improved overall equipment effectiveness (OEE)

---

## Industry-Specific Applications

### CNC Machine Monitoring

Monitor machining centers, lathes, mills, and turning centers for optimal performance:

**Critical Parameters:**

- Spindle vibration and temperature for bearing health
- Cutting forces and tool wear for quality and breakage prevention
- Servo motor current for mechanical binding and misalignment
- Coolant flow and temperature for thermal stability

**Typical Failures Prevented:**

- Spindle bearing failures ($15,000-50,000 repair + downtime)
- Ball screw degradation causing dimensional inaccuracy
- Tool breakage causing part scrap and machine damage
- Hydraulic system failures causing unplanned stops

**ROI**: Typical 4-8 month payback for high-value CNC equipment

[Learn more about CNC machine monitoring](/docs/industries/cnc-machine-monitoring)

### Industrial Door Systems

Monitor overhead doors, high-speed roll-up doors, and automated gate systems:

**Critical Parameters:**

- Spring tension and stress for failure prediction
- Motor current for mechanical resistance and binding
- Cycle counting for maintenance scheduling
- Safety digital input monitoring for operational and safety events

**Typical Failures Prevented:**

- Spring failures causing door drops and safety incidents
- Motor burnout from mechanical binding
- Safety sensor failures causing compliance violations
- Worn cables and pulleys causing unplanned stoppages

**ROI**: Typical 6-12 month payback for high-cycle commercial doors

[Learn more about industrial door monitoring](/docs/industries/industrial-door-monitoring)

### Injection Molding Equipment

Monitor injection molding machines and auxiliary equipment:

**Critical Parameters:**

- Hydraulic pressure and temperature for process stability
- Clamp force monitoring for mold protection
- Screw and barrel wear indicators
- Temperature zone stability for quality control

**Typical Failures Prevented:**

- Hydraulic system failures causing production stoppages
- Mold damage from clamp force issues
- Quality issues from temperature instabilities
- Screw and barrel wear causing process drift

**ROI**: Typical 3-6 month payback for high-volume production

[Learn more about injection molding monitoring](/docs/industries/injection-molding-monitoring)

### Pump and Compressor Monitoring

Monitor critical support infrastructure for facility reliability:

**Critical Parameters:**

- Vibration analysis for bearing and mechanical health
- Temperature monitoring for thermal issues
- Pressure monitoring for performance and leaks
- Current monitoring for mechanical loading

**Typical Failures Prevented:**

- Bearing failures causing catastrophic equipment damage
- Seal leaks causing environmental and safety issues
- Cavitation and flow problems causing efficiency losses
- Motor failures from mechanical overload

**ROI**: Typical 4-10 month payback depending on criticality

[Learn more about pump and compressor monitoring](/docs/industries/pump-compressor-monitoring)

---

## Integration with Existing Systems

EsoCore integrates seamlessly with your existing maintenance management infrastructure:

### CMMS Integration

Automatically create work orders based on equipment condition:

- REST API integration with major CMMS platforms
- Automatic work order generation from alert conditions
- Equipment hierarchy synchronization
- Maintenance history tracking and analysis

**Supported Systems**: SAP PM, IBM Maximo, Infor EAM, eMaint, Fiix, and others via API

### SCADA and Fieldbus Integration

Connect with existing control systems and monitoring infrastructure:

- Modbus RTU/TCP for PLC communication
- PROFIBUS DP and PROFINET for industrial networks
- OPC UA for enterprise integration
- Real-time data sharing with existing SCADA systems

### Business Intelligence Integration

Export data for analysis in your existing BI tools:

- CSV and Parquet export for historical data
- REST API for real-time data access
- Webhook integration for event notifications
- SQL database access for custom queries

---

## Getting Started

### Step 1: Identify Priority Equipment

Start with equipment that has the highest downtime impact:

- Production bottlenecks where failures stop entire lines
- Critical support equipment (compressors, chillers, pumps)
- Equipment with history of costly unplanned failures
- High-value capital equipment with expensive repairs

### Step 2: Define Success Metrics

Establish baseline metrics to measure improvement:

- Current unplanned downtime hours per month
- Average maintenance cost per machine per year
- Mean time between failures (MTBF)
- Overall equipment effectiveness (OEE)

### Step 3: Deploy Pilot System

Install monitoring on 1-3 machines to validate the approach:

- 1-2 weeks for hardware installation and configuration
- 2-4 weeks for baseline data collection
- 2-4 weeks for model training and alert tuning
- Ongoing optimization as patterns are identified

### Step 4: Measure and Expand

Track results and expand monitoring based on proven ROI:

- Document caught issues and prevented downtime
- Calculate actual cost savings and ROI
- Expand to additional equipment based on success
- Refine processes and integrate with existing workflows

---

## Support and Resources

### Technical Support

- **Documentation**: Comprehensive guides for installation, configuration, and troubleshooting
- **Community**: GitHub discussions for questions and knowledge sharing
- **Commercial Support**: Enterprise support contracts with guaranteed response times
- **Professional Services**: Consulting for complex deployments and integrations

### Training and Education

- **Self-Service**: Online documentation and video tutorials
- **Instructor-Led**: On-site and virtual training for operators and maintenance staff
- **Certification**: Technical certification programs for partners and integrators
- **Workshops**: Industry-specific workshops and best practices sessions

### Related Resources

- [Equipment Downtime Prevention Strategies](/docs/solutions/equipment-downtime-prevention)
- [Factory-Wide Monitoring Guide](/docs/solutions/factory-monitoring)

---

Transform your maintenance strategy from reactive to predictive with EsoCore. Start with a pilot program on your most critical equipment and
experience the benefits of data-driven maintenance decision making.

[View technical documentation](/docs)

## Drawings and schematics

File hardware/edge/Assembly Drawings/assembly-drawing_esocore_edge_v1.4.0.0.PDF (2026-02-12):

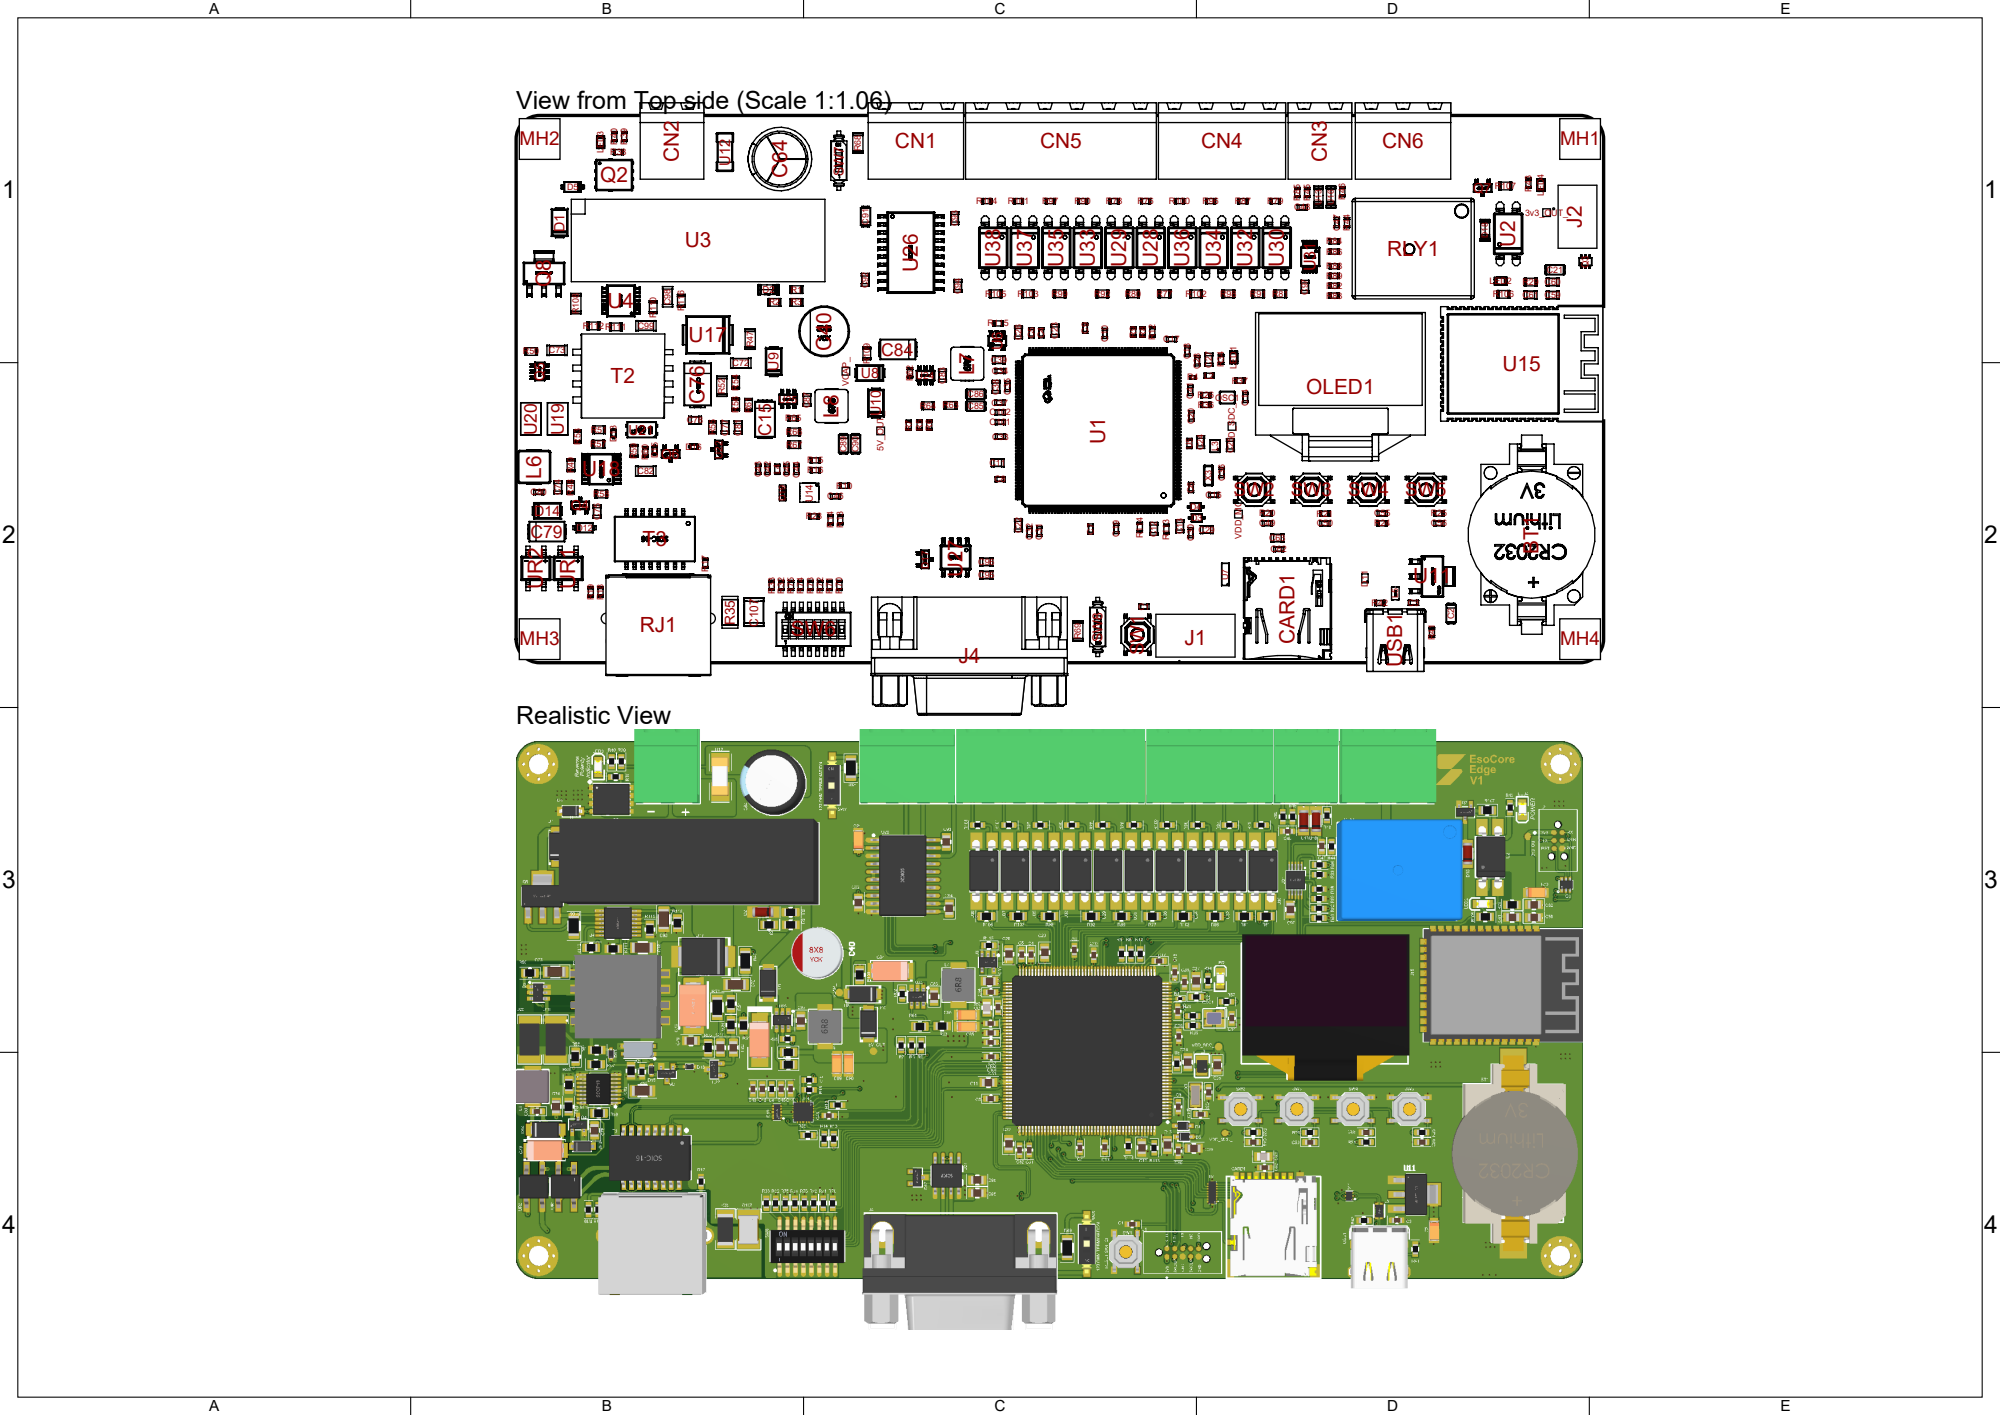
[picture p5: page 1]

View from Top side (Scale 1:1.06)

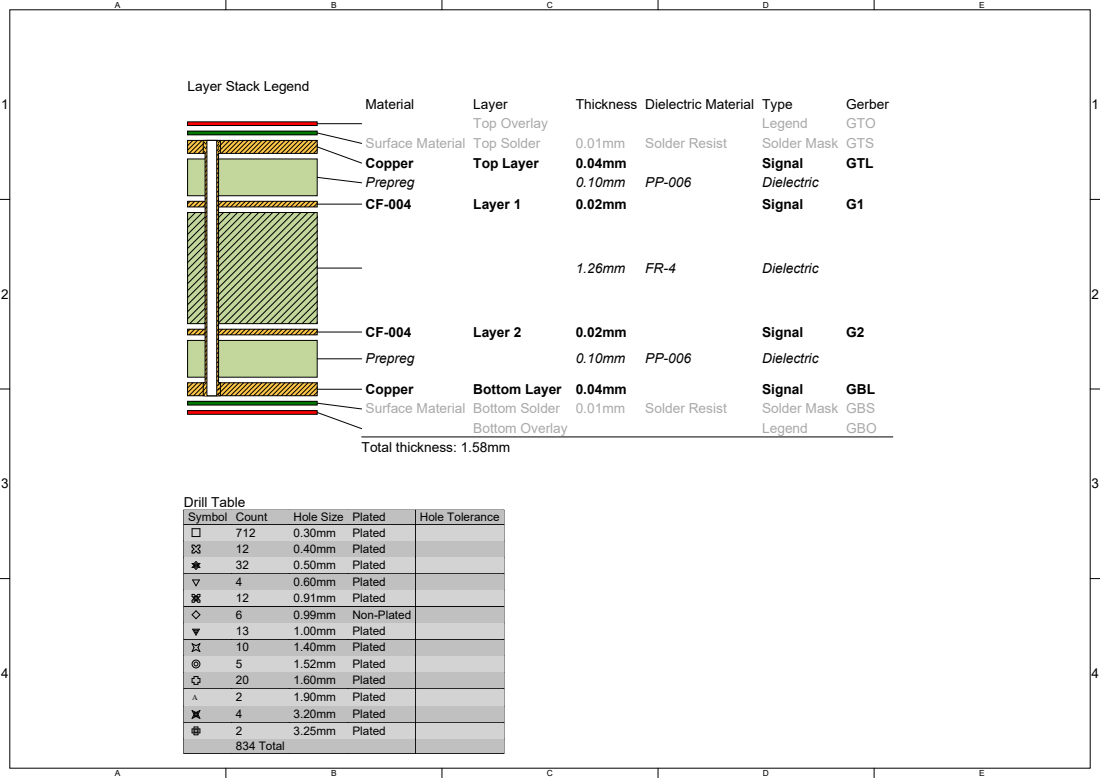
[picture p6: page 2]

Symbol | Count | Hole Size | Plated | Hole Tolerance

712 | 0.30mm | Plated
12 | 0.40mm | Plated
32 | 0.50mm | Plated
4 | 0.60mm | Plated
12 | 0.91mm | Plated
6 | 0.99mm | Non-Plated
13 | 1.00mm | Plated
10 | 1.40mm | Plated
5 | 1.52mm | Plated
20 | 1.60mm | Plated

A | | | 2 | 1.90mm | Plated

4 | 3.20mm | Plated
2 | 3.25mm | Plated
834 Total

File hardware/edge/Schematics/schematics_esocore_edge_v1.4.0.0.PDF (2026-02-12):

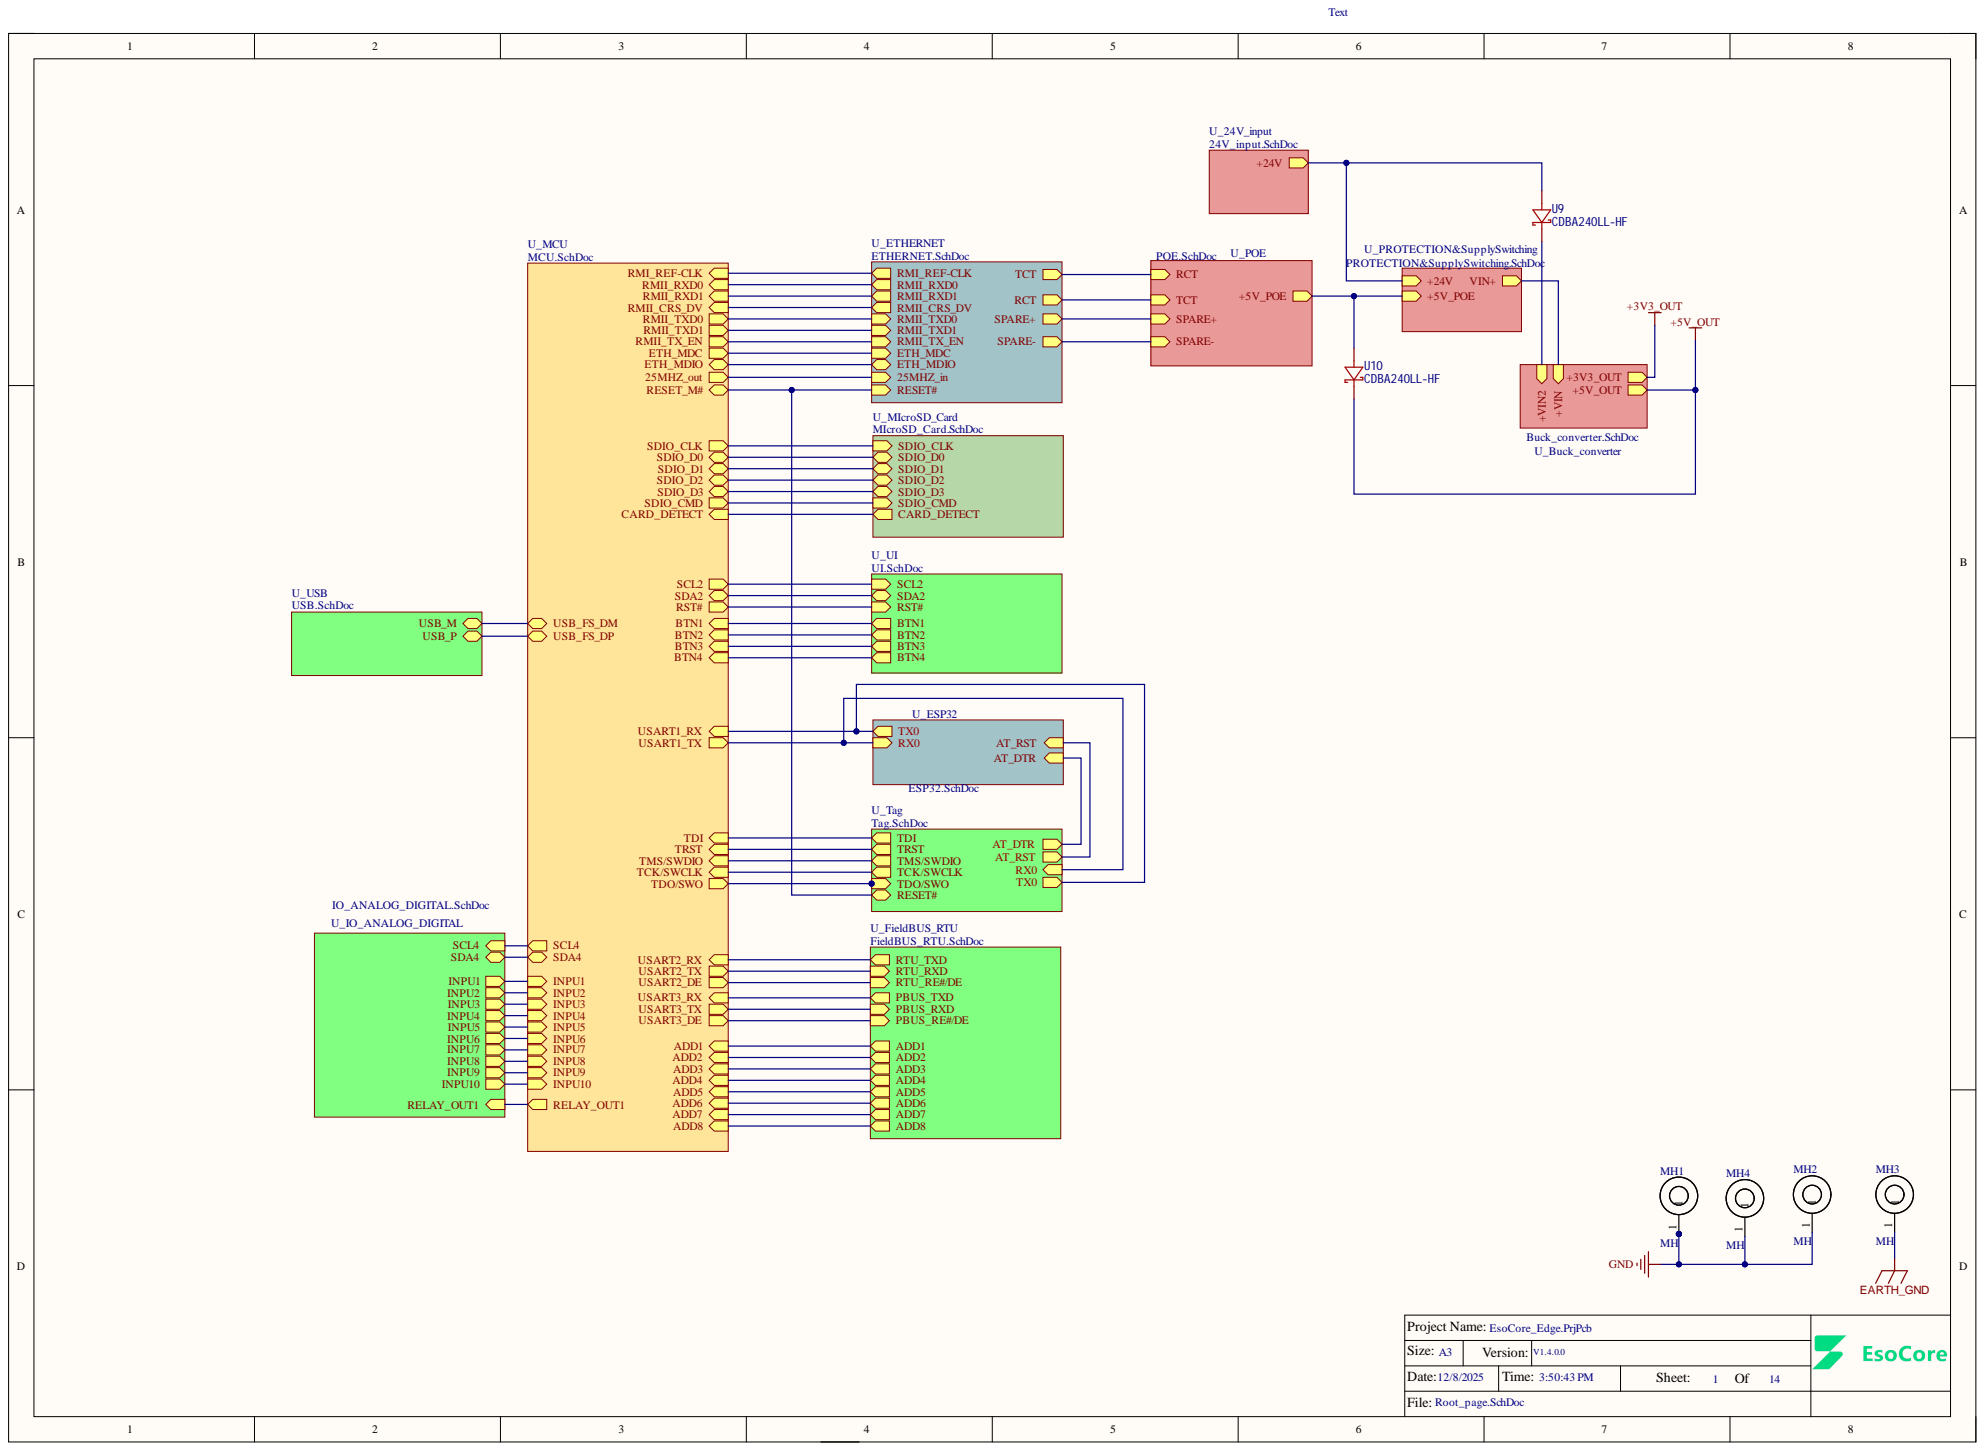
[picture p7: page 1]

TCK/SWCLK TX0
TDO/SWO RESET#

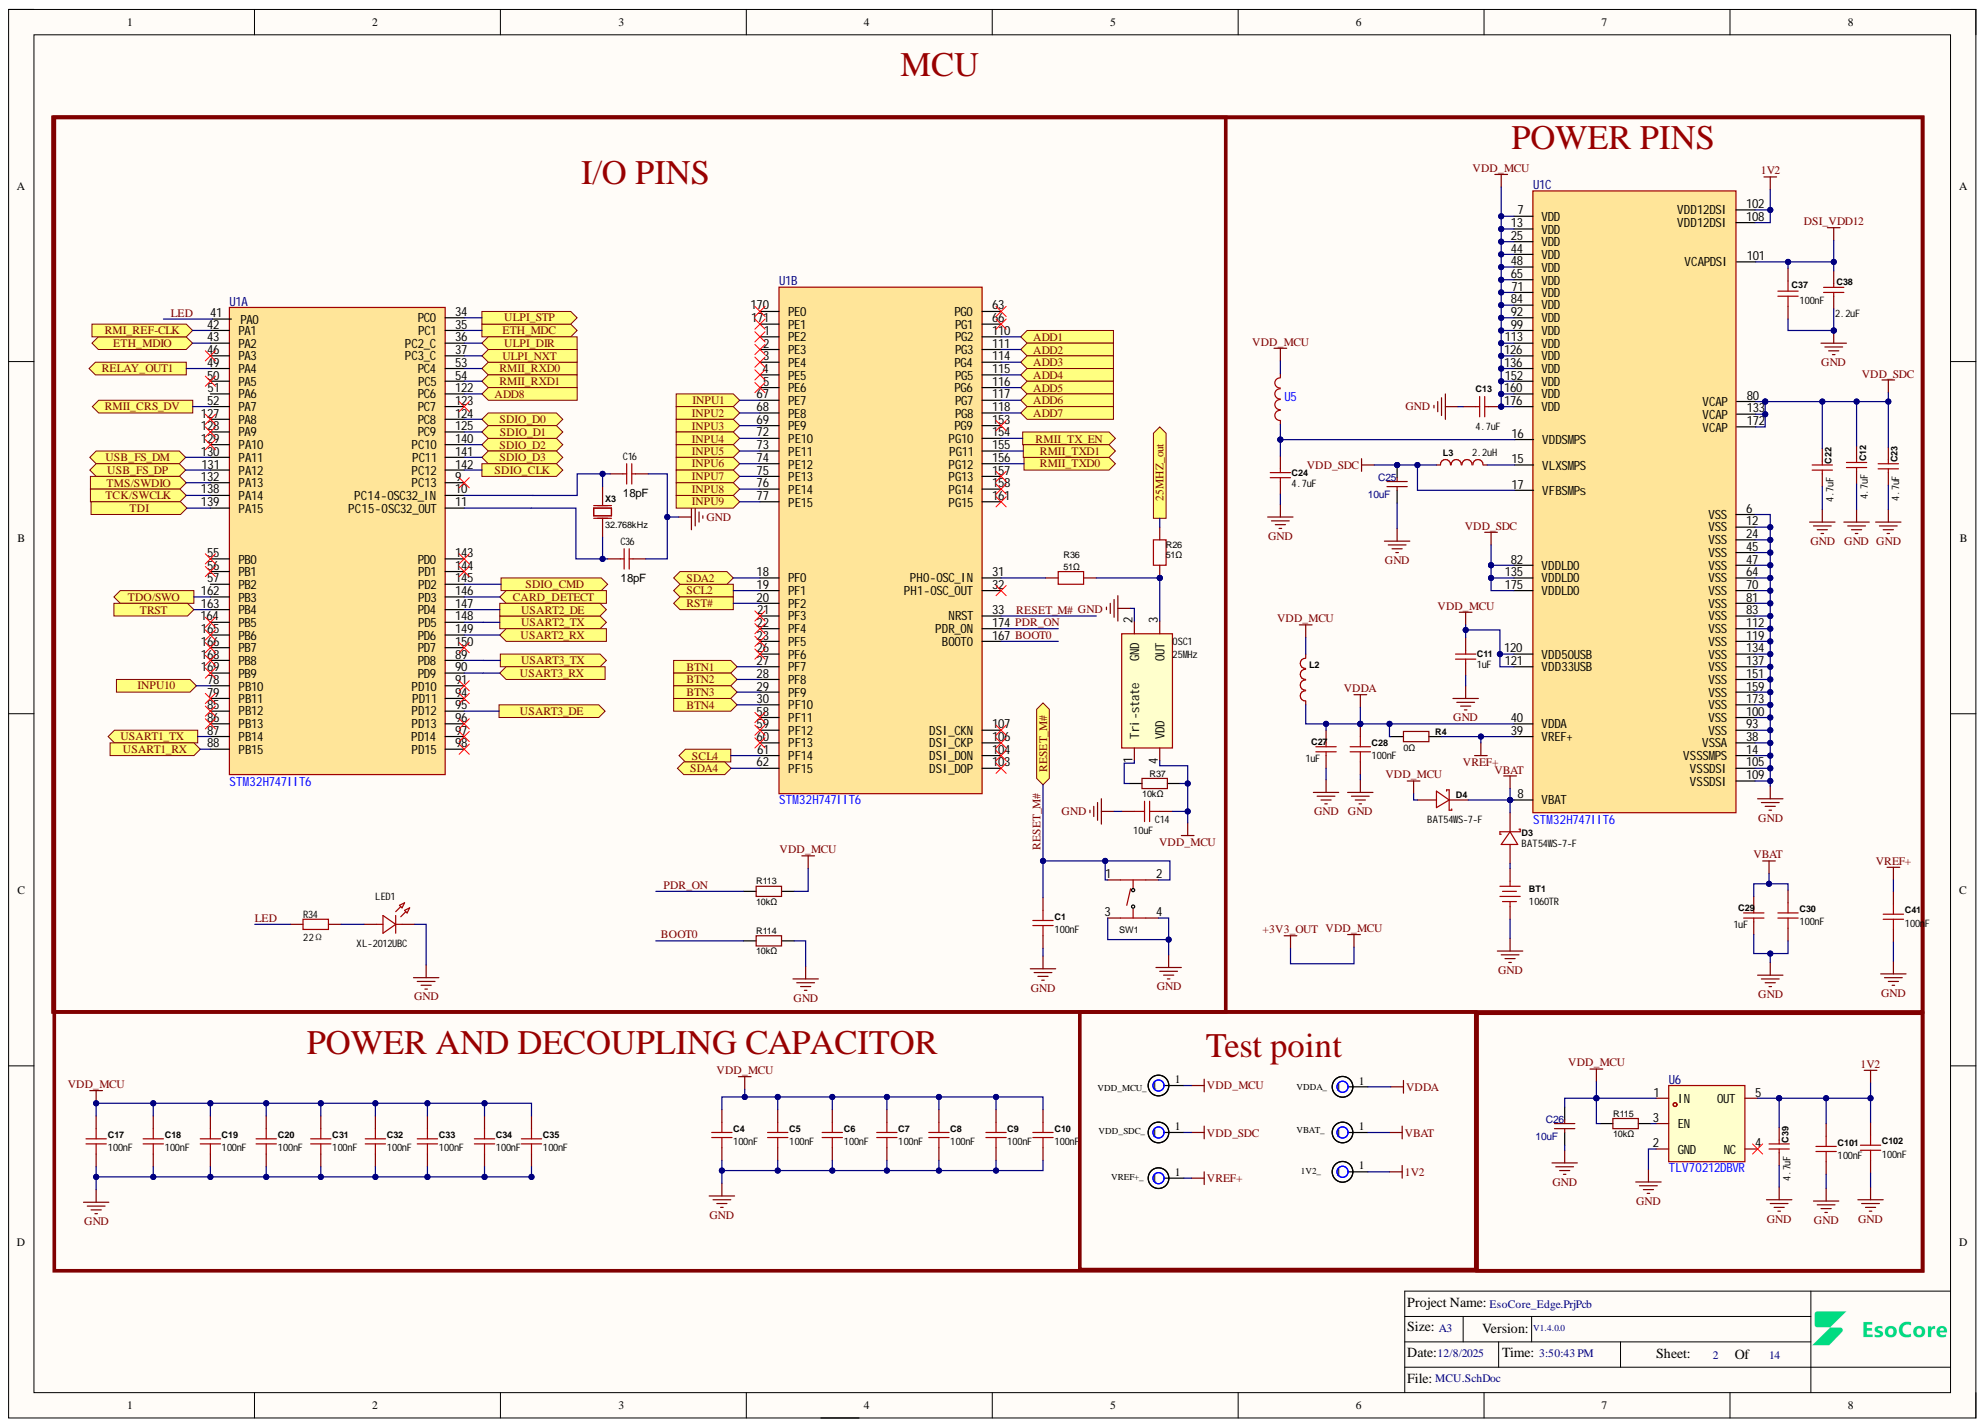
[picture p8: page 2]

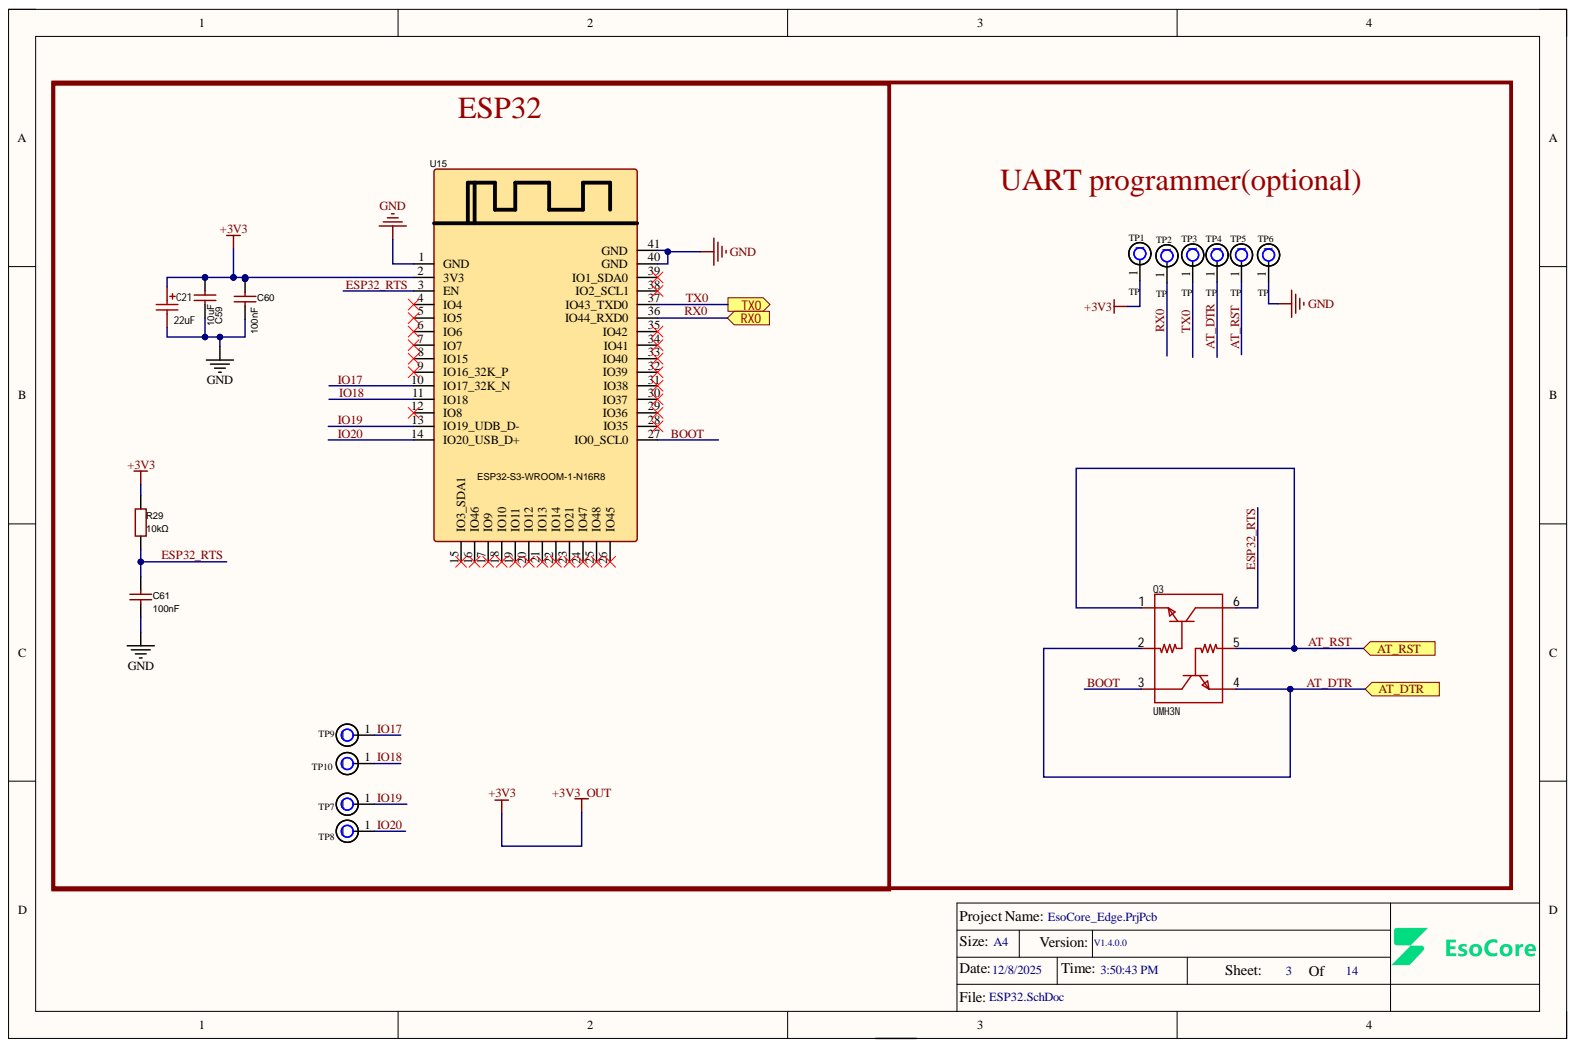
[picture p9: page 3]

Project Name: EsoCore_Edge.PrjPcb
Size: A4 | Version: | V1.4.0.0

Date: 12/8/2025 | Time: 3:50:43 PM | Sheet: 3 Of 14

File: ESP32.SchDoc

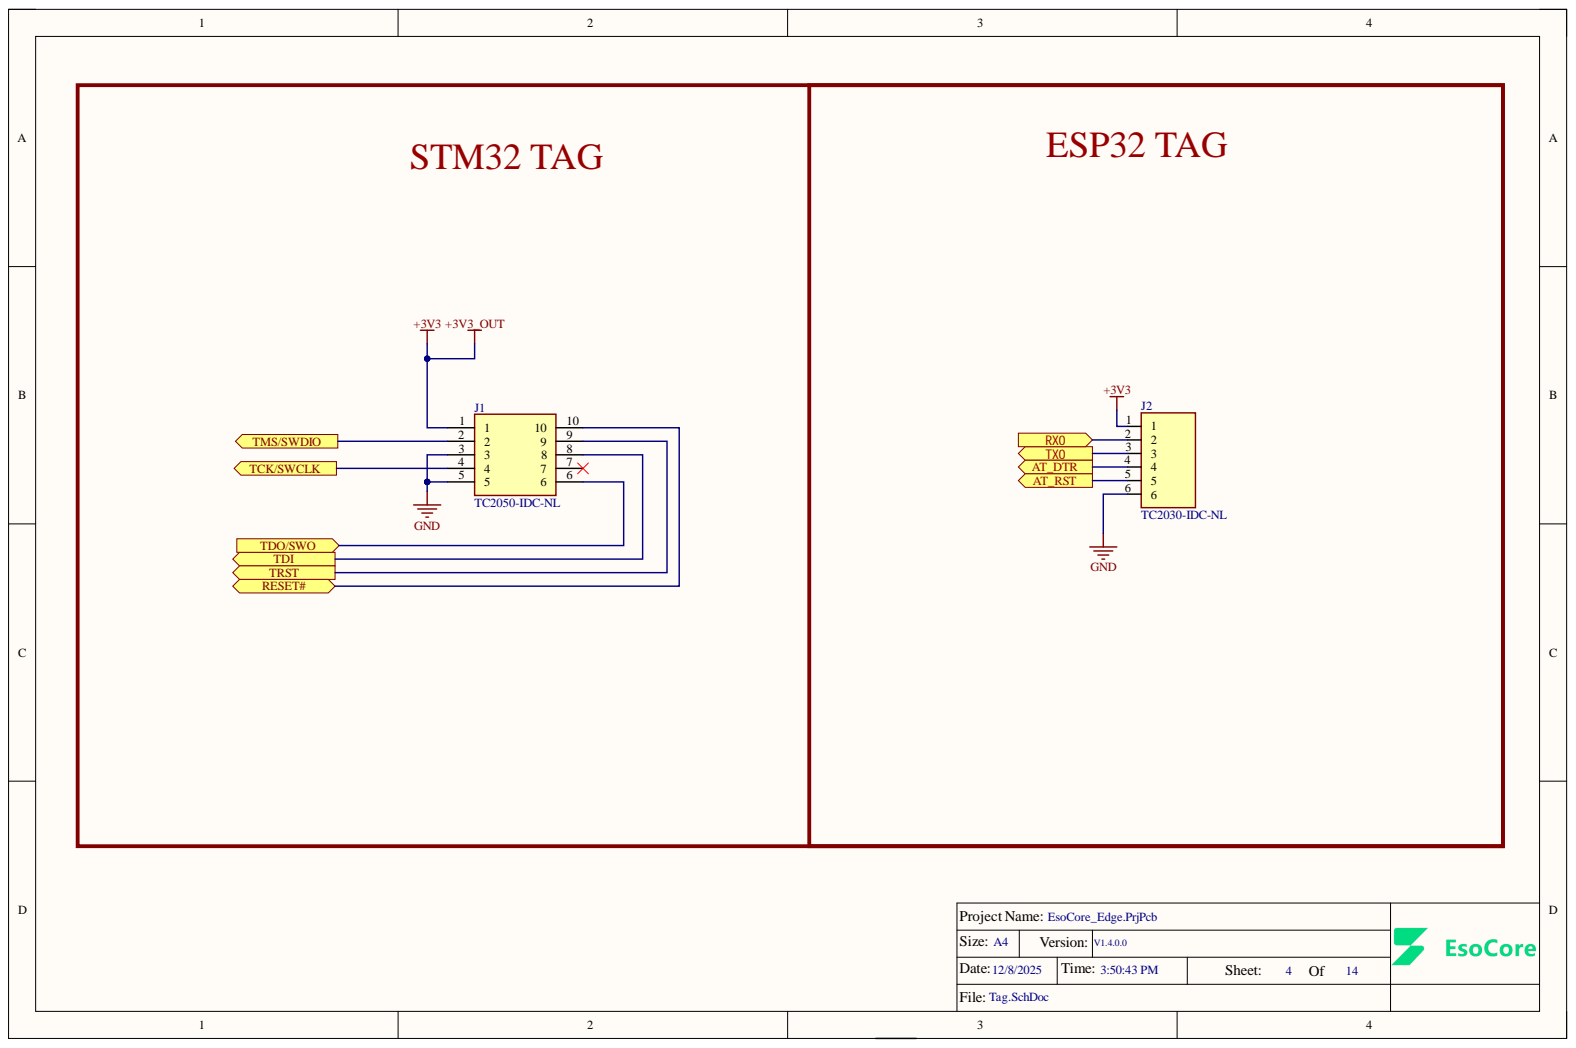
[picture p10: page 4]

Pr oject Name : EsoCor e_Edge . P rj P c b
Si z e : A4 | Versi o n : | V1.4.0.0

Dat e : 12/8/202 5 | T i me : 3:50:43 P M | Shee t : O f 14 4

Fi l e : Tag. S c hD o c

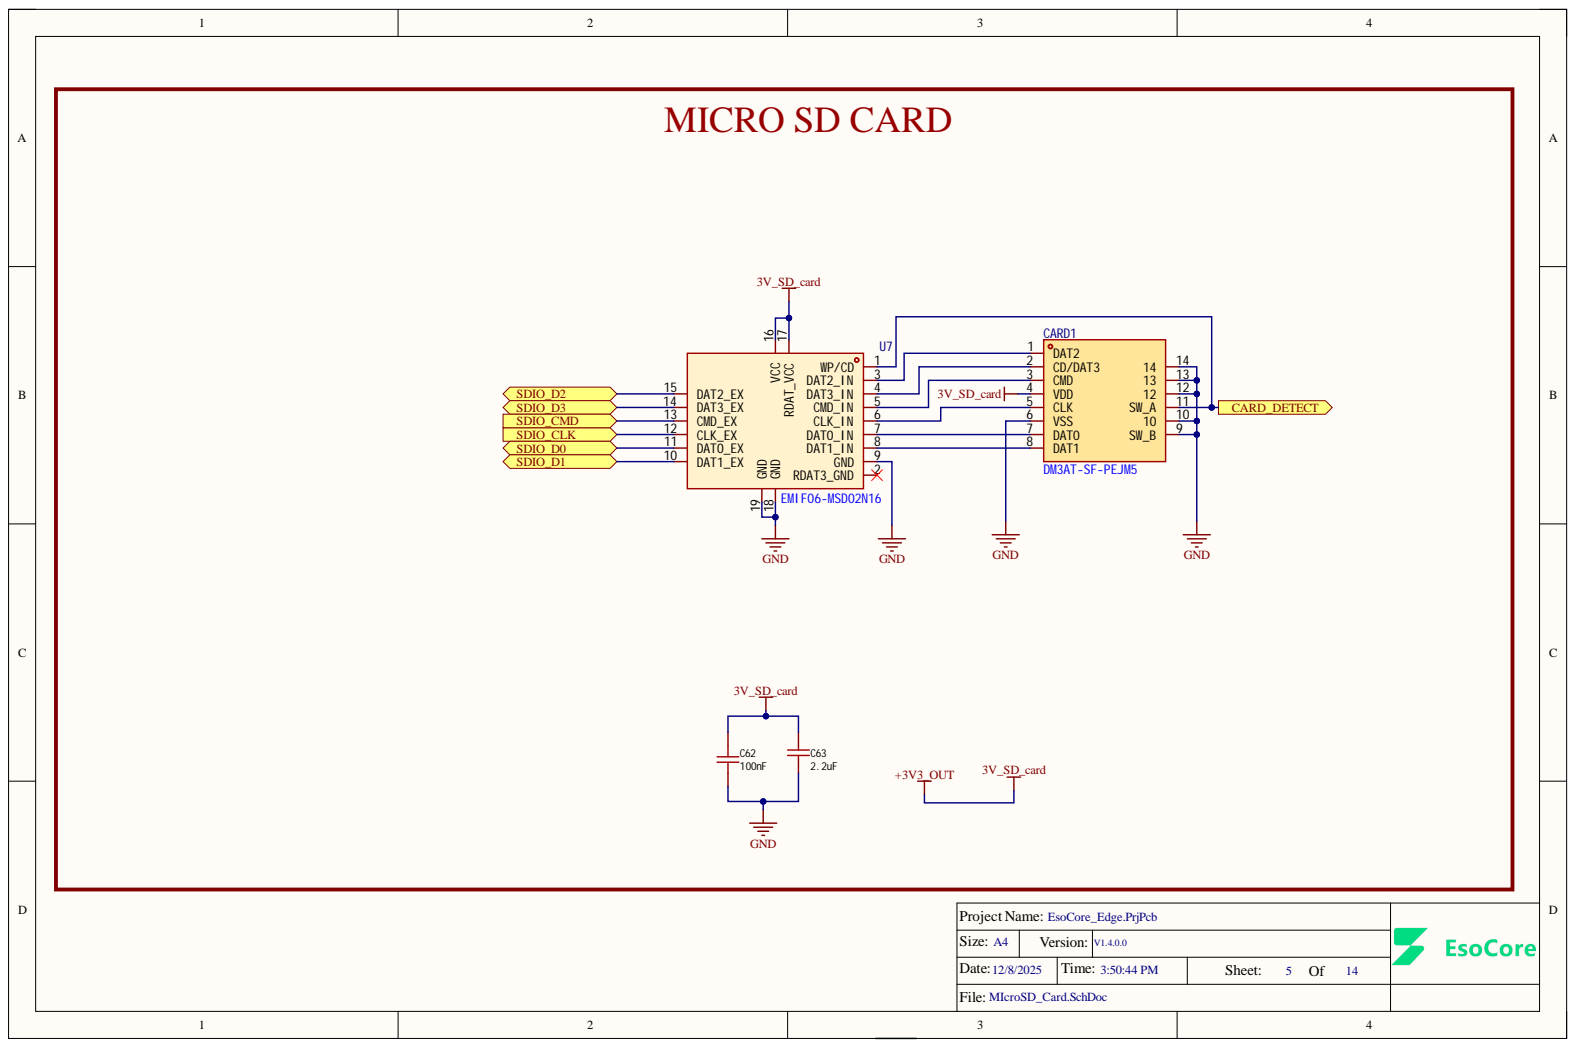
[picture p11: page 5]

Project Name: EsoCore_Edge.PrjPcb
Size: A4 | Version: | V1.4.0.0

Date: 12/8/2025 | Time: 3:50:44 PM | Sheet: 5 Of 14

File: MIcroSD_Card.SchDoc

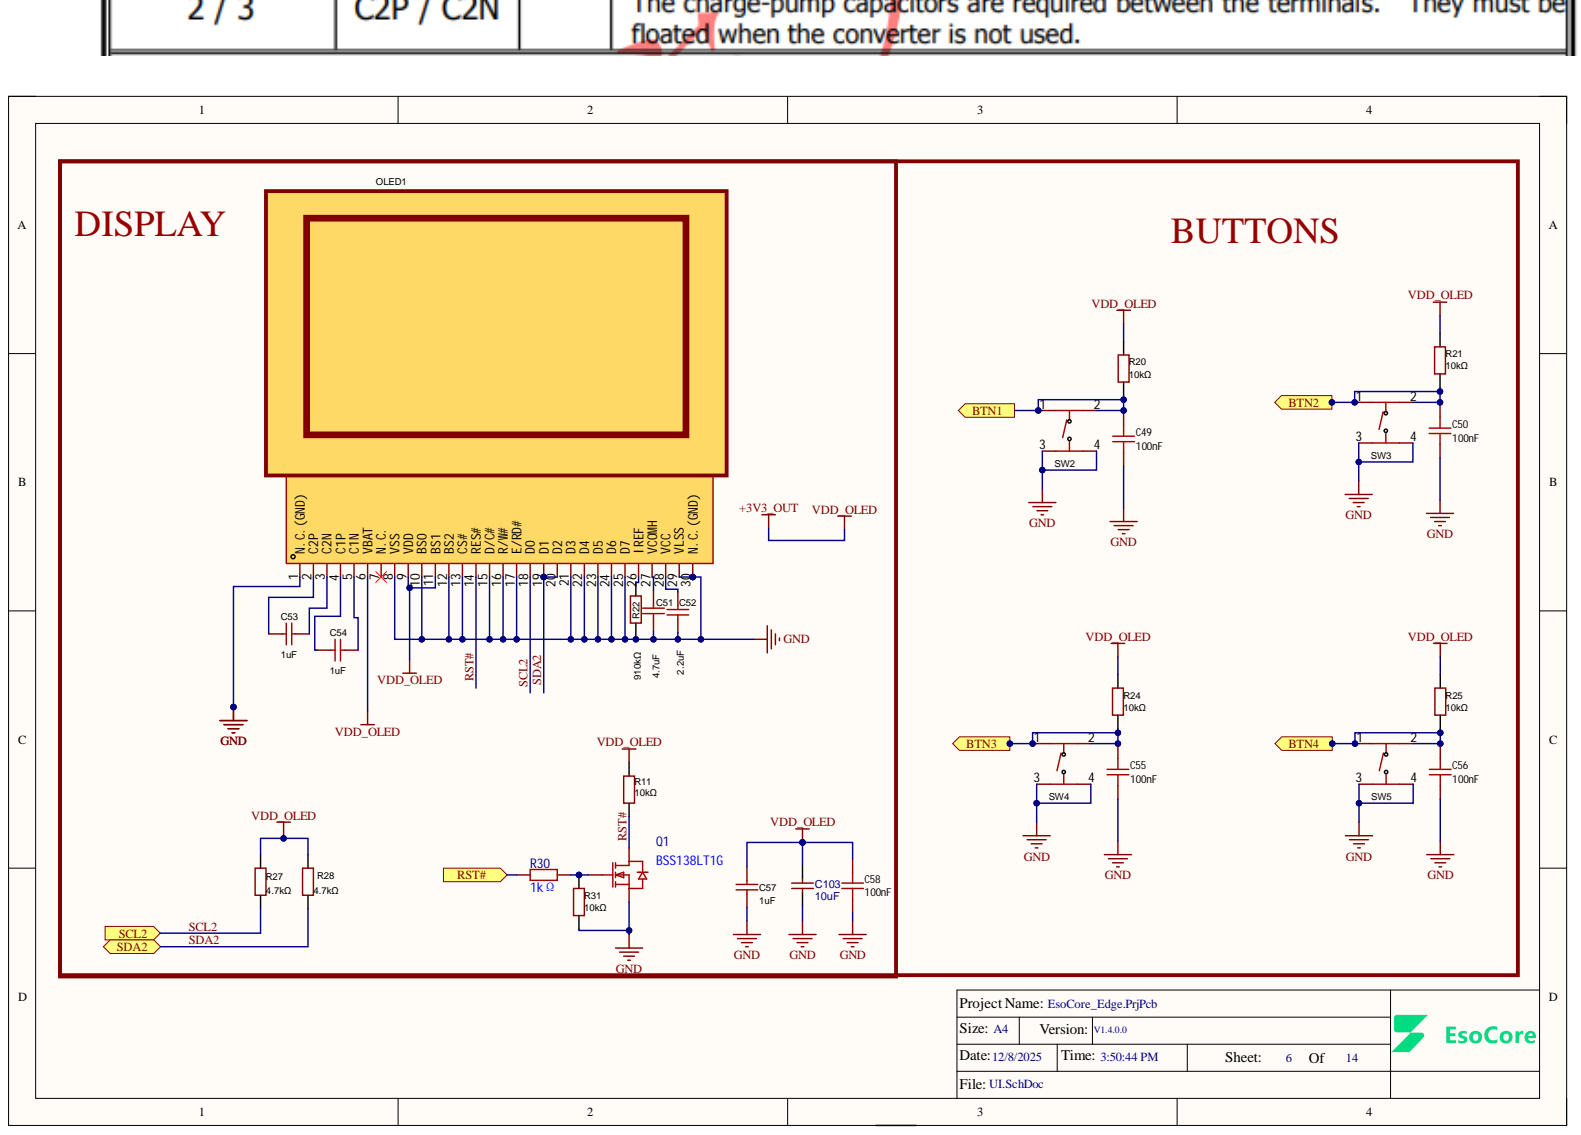
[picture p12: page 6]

Project Name: EsoCore_Edge.PrjPcb
Size: A4 | Version: | V1.4.0.0

Date: 12/8/2025 | Time: 3:50:44 PM | Sheet: 6 Of 14

File: UI.SchDoc

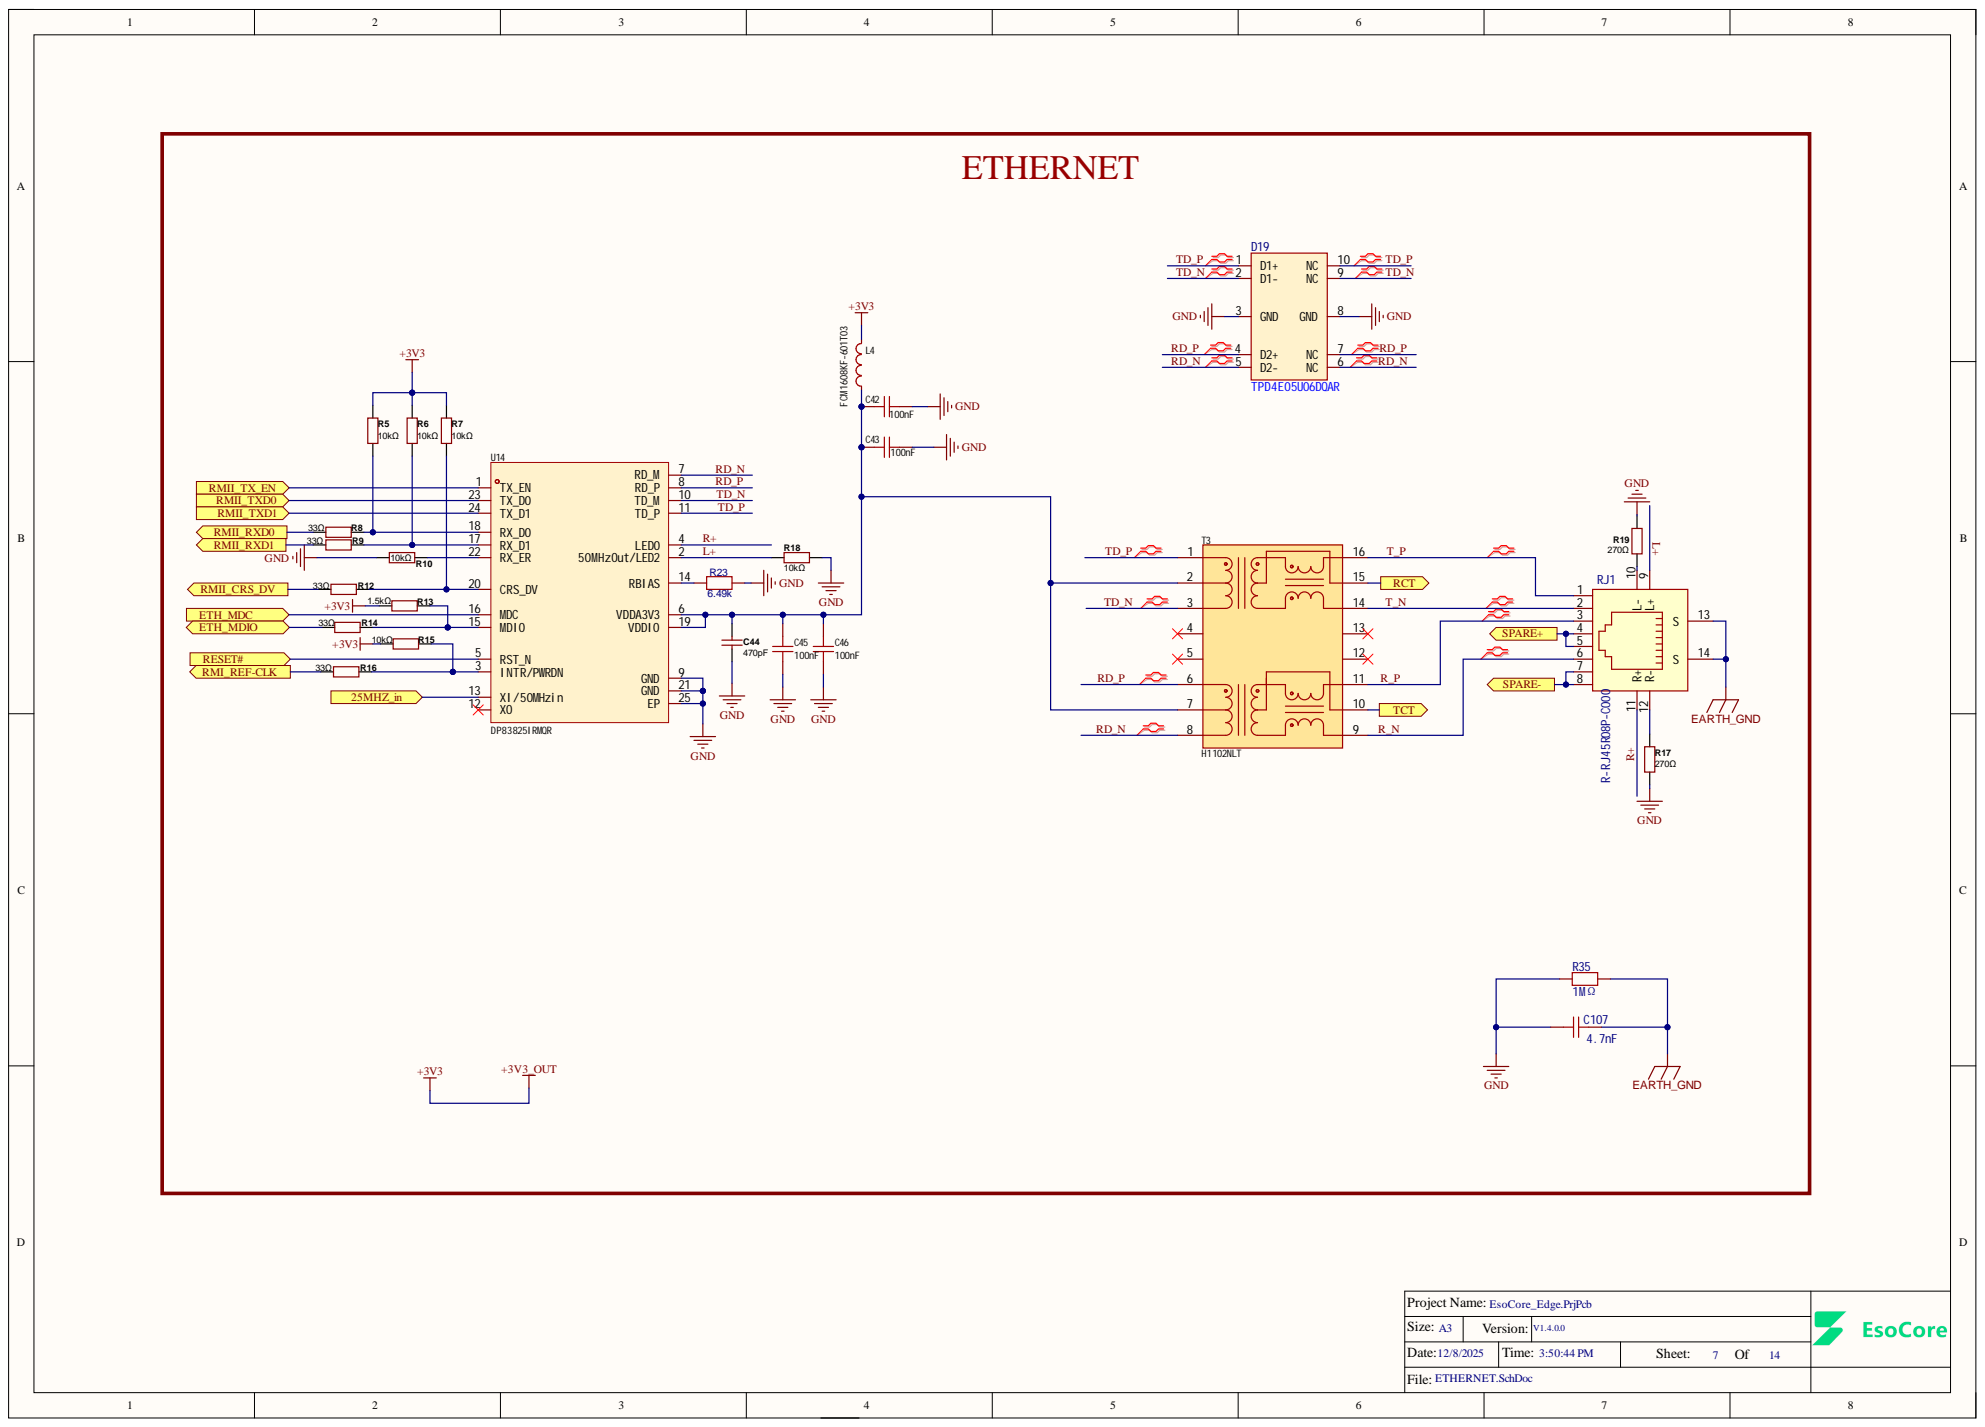
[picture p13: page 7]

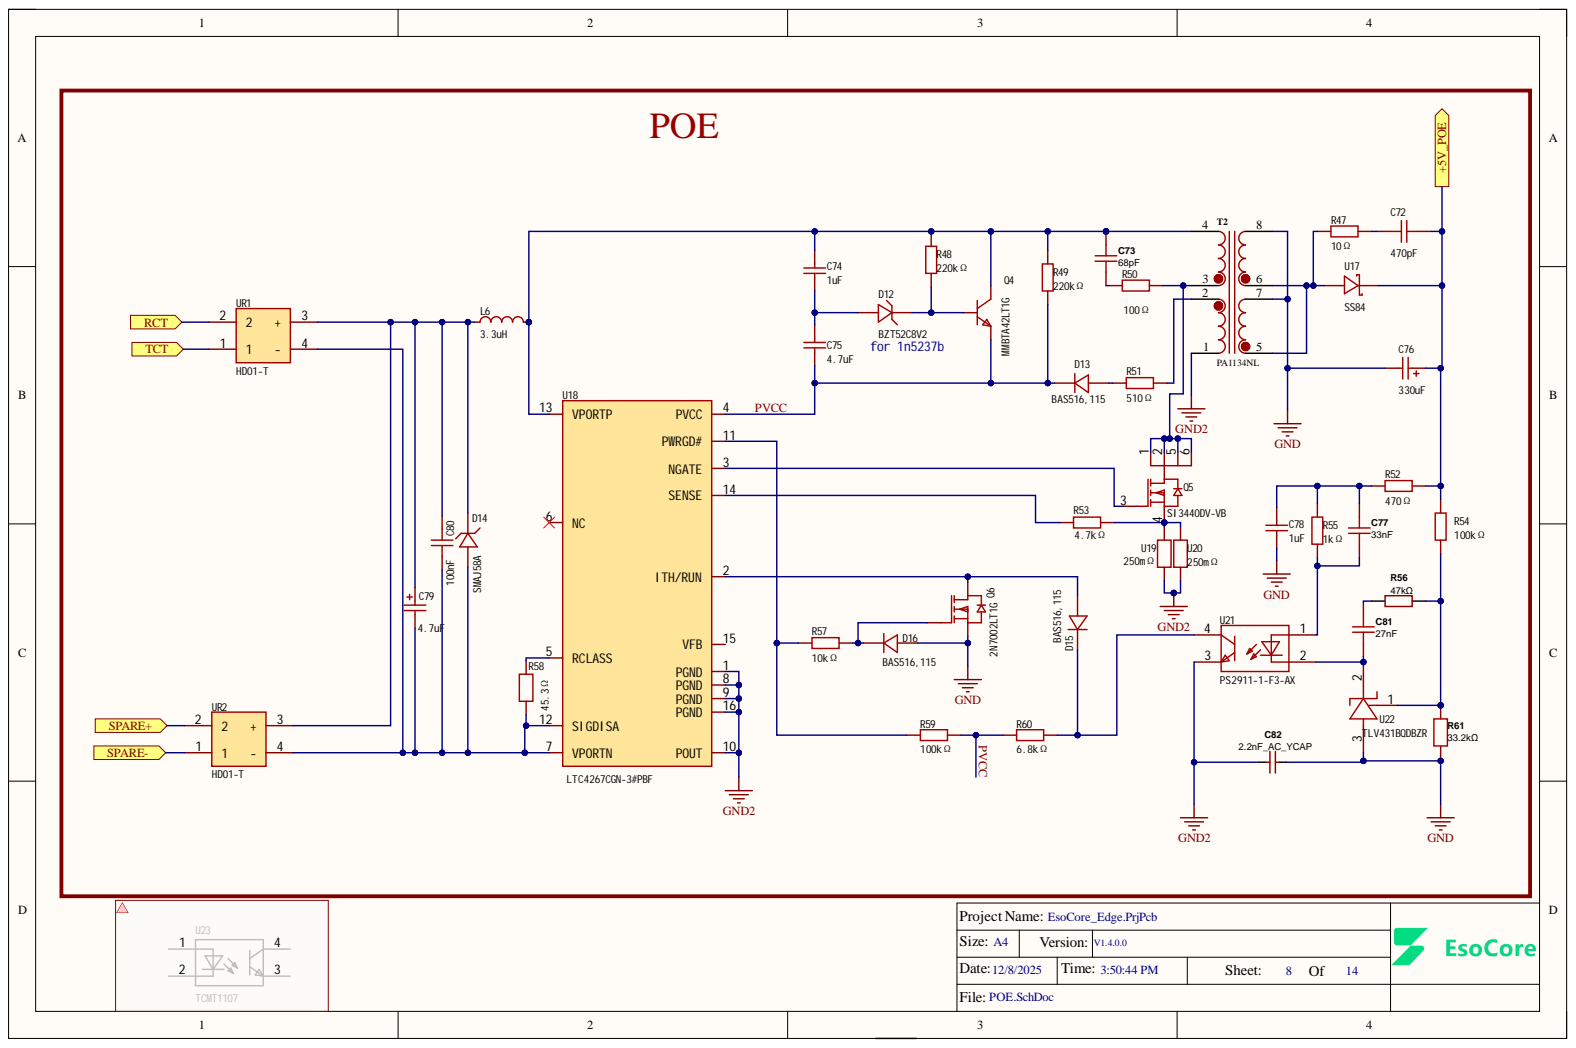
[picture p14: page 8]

Ω 1 BAS 51

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

Dat e : 12/8/202 5 | T i me : 3:50:44 P M | Shee t : O f 14 8

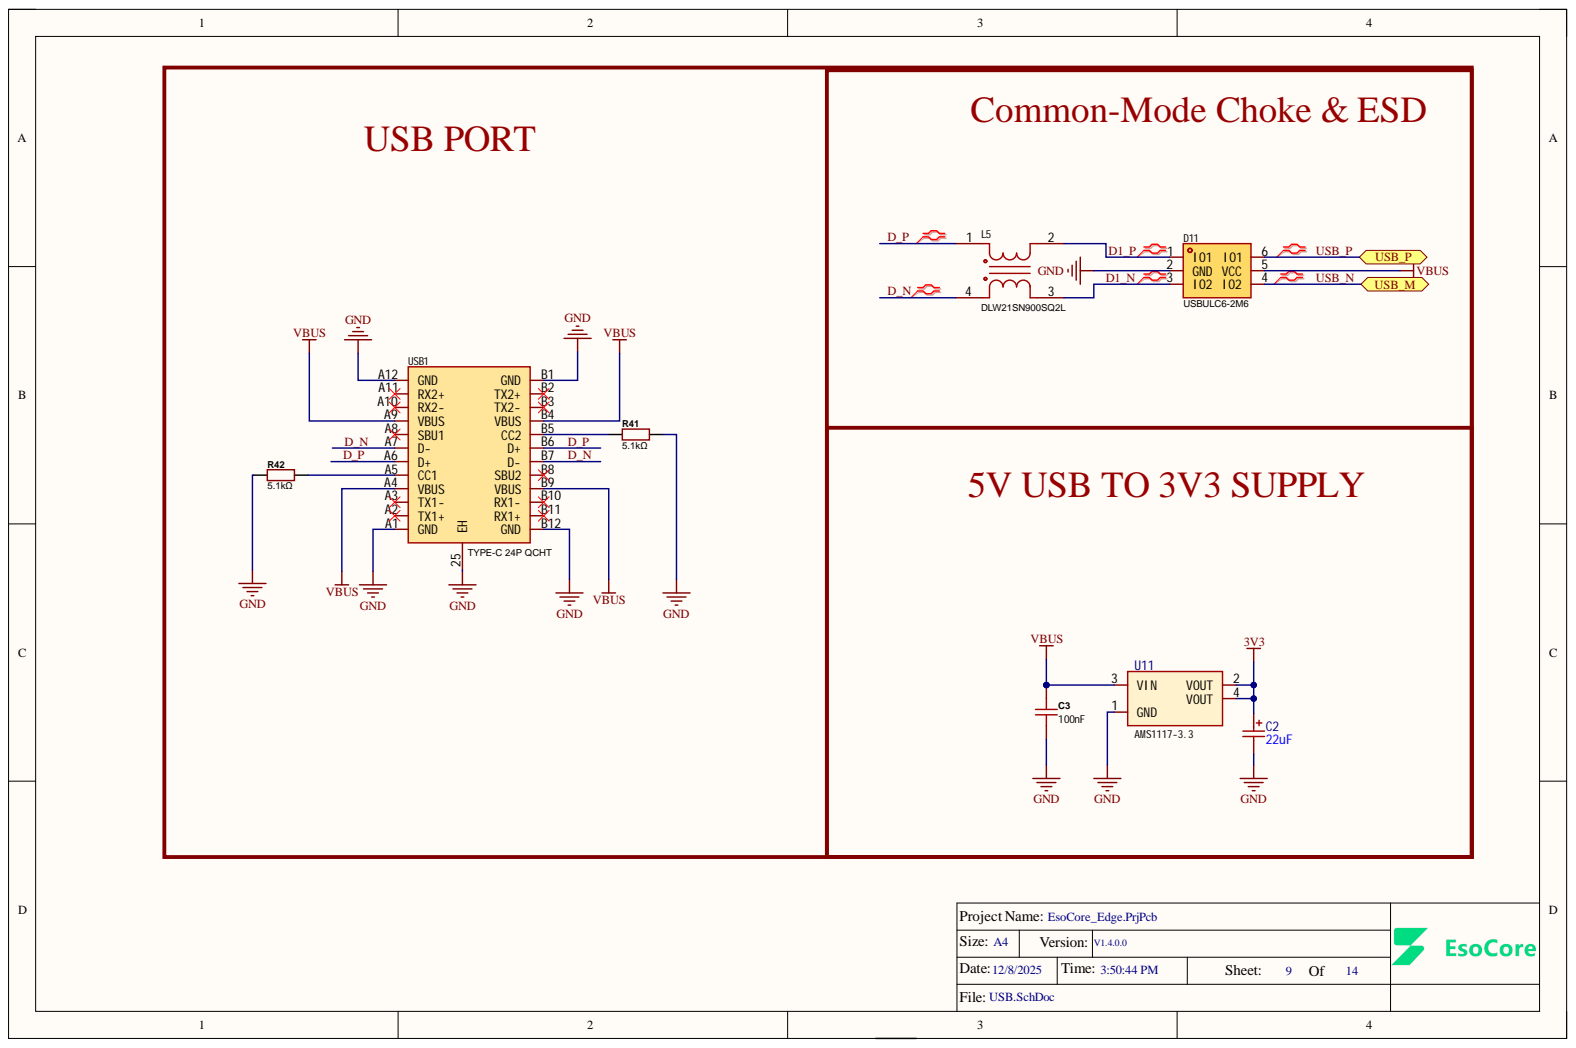
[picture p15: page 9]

Common-Mode Choke & ESD

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

Dat e : 12/8/202 5 | T i me : 3:50:44 P M | Shee t : O f 14 9

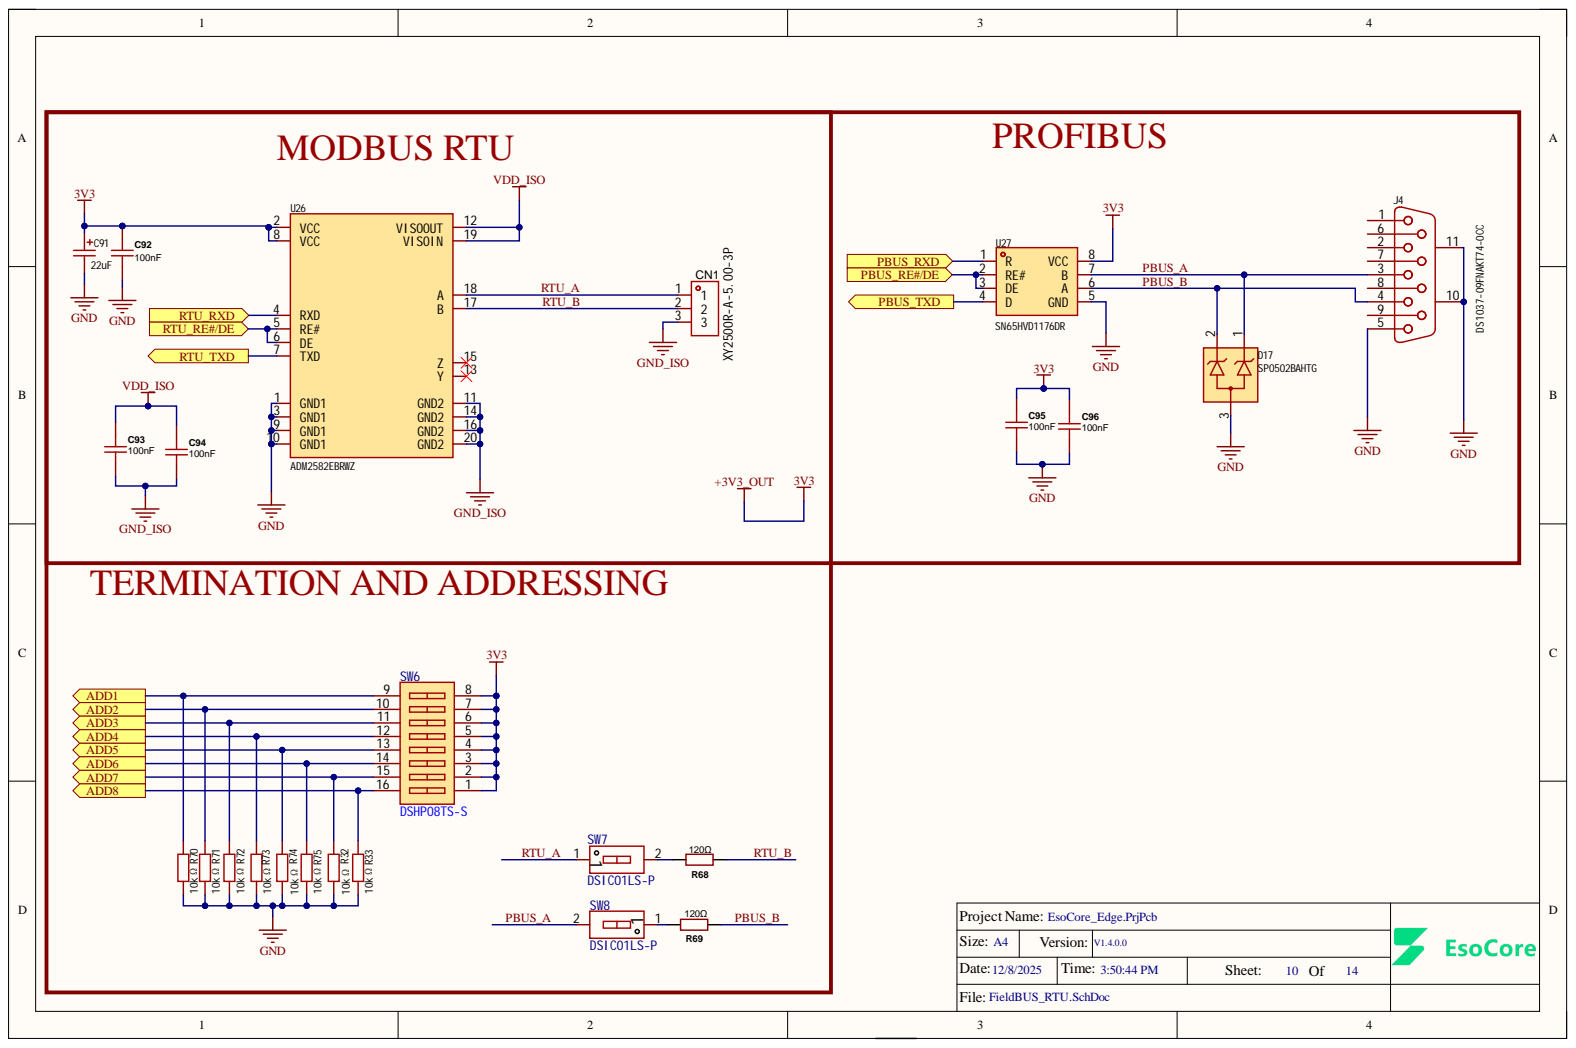
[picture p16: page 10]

VDD_ISO | VCC 8

RE# 5
DE 6

10 | | 7
11 | | 6
12 | | 5
13 | | 4
14 | | 3
15 | | 2
16 | | 1

Project Name: EsoCore_Edge.PrjPcb
Size: A4 | Version: | V1.4.0.0

Date: 12/8/2025 | Time: 3:50:44 PM | Sheet: 10 Of 14

File: FieldBUS_RTU.SchDoc

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

Dat e : 12/8/202 5 | T i me : 3:50:45 P M | Shee t : O f 14 1 1

Fi l e : Buck_conve rte r . S c hD o c


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

Dat e : 12/8/202 5 | T i me : 3:50:45 P M | Shee t : 13 O f 14

Fi l e : P ROTECTION&SupplySwitchin g . S c hD o c

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

Dat e : 12/8/202 5 | T i me : 3:50:45 P M | Shee t : 14 O f 14

Fi l e : 24V_input. S c hD o c

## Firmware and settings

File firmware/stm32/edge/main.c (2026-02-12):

/**
 * @file main.c
 * @brief EsoCore Edge Device v1.5.0.0 Main Application
 *
 * Complete system initialization and runtime loop for the EsoCore Edge device
 * targeting the STM32H747IIT6 (Cortex-M7). Integrates all v1.5.0.0 subsystems:
 *
 *   - 24V DC power management with brownout detection and supercap backup
 *   - Dual Ethernet (Port A: Machine/OT, Port B: IT/Cloud)
 *   - 4-channel dual-mode analog inputs (IEPE + DC, 24-bit, 50 kSPS)
 *   - 6 dual-channel safety digital inputs (EN ISO 13849 Cat. 3)
 *   - RS-485 sensor bus with auto-discovery
 *   - Modbus RTU, PROFIBUS DP, Interbus fieldbus interfaces
 *   - ESP32-S3 WiFi/BT via UART AT commands
 *   - MicroSD storage, OLED display, TinyML edge intelligence
 *
 * @author EsoCore Development Team
 * @copyright Copyright (c) 2026 Newmatik. All rights reserved.
 * @license Apache License, Version 2.0
 */

#include <stdint.h>
#include <stdbool.h>
#include <string.h>

/* BSP and HAL */
#include "../../stm32/stm32h7/bsp/bsp_edge_v150.h"
#include "../../stm32/stm32h7/bsp/system_clock.h"
#include "../../stm32/stm32h7/cmsis/stm32h747xx.h"
#include "../../stm32/stm32h7/cmsis/system_stm32h7xx.h"
#include "../../stm32/stm32h7/hal/hal_gpio.h"
#include "../../stm32/stm32h7/hal/hal_spi.h"
#include "../../stm32/stm32h7/hal/hal_uart.h"
#include "../../stm32/stm32h7/hal/hal_i2c.h"
#include "../../stm32/stm32h7/hal/hal_eth.h"
#include "../../stm32/stm32h7/hal/hal_dma.h"
#include "../../stm32/stm32h7/hal/hal_timer.h"
#include "../../stm32/stm32h7/hal/hal_adc.h"

/* Hardware drivers */
#include "../../stm32/stm32h7/drivers/drv_ksz8081.h"
#include "../../stm32/stm32h7/drivers/drv_ads1274.h"
#include "../../stm32/stm32h7/drivers/drv_pga280.h"
#include "../../stm32/stm32h7/drivers/drv_tmux1101.h"
#include "../../stm32/stm32h7/drivers/drv_iepe.h"
#include "../../stm32/stm32h7/drivers/drv_ssr.h"

/* Subsystem modules */
#include "../../common/communication/ethernet_manager.h"
#include "../../common/analog/analog_input.h"
#include "../../common/communication/interbus.h"
#include "../../common/communication/sensor_bus.h"

/* Existing common modules */
#include "../../common/management/power_management.h"
#include "../../common/safety/safety_io.h"
#include "../../common/communication/wifi_manager.h"
#include "../../common/communication/http_client.h"
#include "../../common/communication/modbus_rtu.h"
#include "../../common/communication/protocol.h"
#include "../../common/storage/storage_system.h"
#include "../../common/management/config_manager.h"
#include "../../common/intelligence/event_system.h"
#include "../../common/intelligence/tinyml_engine.h"
#include "../../common/ui/oled_display.h"

/* ============================================================================
 * Firmware Version
 * ============================================================================ */

#define FW_VERSION_STRING   ESOCORE_FW_VERSION_STRING

/* ============================================================================
 * Timing Configuration (all in milliseconds)
 * ============================================================================ */

#define POWER_POLL_INTERVAL_MS      100     /* Power rail monitoring */
#define SAFETY_POLL_INTERVAL_MS     10      /* Safety inputs (fast for response time) */
#define ETHERNET_POLL_INTERVAL_MS   1       /* Ethernet RX polling */
#define SENSOR_BUS_POLL_INTERVAL_MS 10      /* RS-485 sensor bus */
#define INTERBUS_POLL_INTERVAL_MS   5       /* Interbus cyclic */
#define DISPLAY_UPDATE_INTERVAL_MS  2000    /* OLED update */
#define HEARTBEAT_INTERVAL_MS       30000   /* Cloud heartbeat */
#define TELEMETRY_INTERVAL_MS       5000    /* Cloud telemetry */
#define OTA_CHECK_INTERVAL_MS       3600000 /* OTA check (1 hour) */
#define WATCHDOG_FEED_INTERVAL_MS   500     /* IWDG feed */

/* Device identity */
#define DEVICE_ADDRESS              0x01
#define DEVICE_TYPE                 0x01    /* Edge device */

/* ============================================================================
 * Global SPI Handles (shared between drivers and HAL)
 * ============================================================================ */

hal_spi_handle_t g_spi3_handle;   /* ADS1274 ADC */
hal_spi_handle_t g_spi4_handle;   /* PGA280 amplifiers */

/* ============================================================================
 * Global State
 * ============================================================================ */

static volatile bool system_running = false;

/* Timing counters */
static uint32_t last_power_poll = 0;
static uint32_t last_safety_poll = 0;
static uint32_t last_ethernet_poll = 0;
static uint32_t last_sensor_bus_poll = 0;
static uint32_t last_interbus_poll = 0;
static uint32_t last_display_update = 0;
static uint32_t last_heartbeat = 0;
static uint32_t last_telemetry = 0;
static uint32_t last_watchdog_feed = 0;

/* Forward declarations */
extern void hal_gpio_init_all(void);
static bool init_hal_peripherals(void);
static bool init_subsystems(void);
static void runtime_loop(void);
static void graceful_shutdown(void);
static void feed_watchdog(void);

/* ============================================================================
 * IWDG (Independent Watchdog) Control
 * ============================================================================ */

#define IWDG_BASE       0x58004800UL
#define IWDG_KR         (*(volatile uint32_t *)(IWDG_BASE + 0x00))
#define IWDG_PR         (*(volatile uint32_t *)(IWDG_BASE + 0x04))
#define IWDG_RLR        (*(volatile uint32_t *)(IWDG_BASE + 0x08))
#define IWDG_SR         (*(volatile uint32_t *)(IWDG_BASE + 0x0C))

static void iwdg_init(uint32_t timeout_ms)
{
    /* LSI ~32 kHz, prescaler /64 -> 500 Hz counter */
    IWDG_KR = 0x5555;  /* Enable register access */
    IWDG_PR = 4;       /* Prescaler /64 */
    IWDG_RLR = (timeout_ms * 500) / 1000;  /* Reload value */
    IWDG_KR = 0xCCCC;  /* Start watchdog */
}

static void feed_watchdog(void)
{
    IWDG_KR = 0xAAAA;  /* Reload counter */
}

/* ============================================================================
 * Interrupt Handlers
 * ============================================================================ */

/**
 * @brief SysTick interrupt -- 1 ms tick
 */
void SysTick_Handler(void)
{
    system_clock_tick_increment();
}

/**
 * @brief Hard fault handler -- enter safe state and reset
 */
void HardFault_Handler(void)
{
    /* De-energize all safety outputs immediately */
    hal_gpio_reset(SAFETY_RELAY_CTRL);
    hal_gpio_reset(SSR_CTRL);

    /* Log fault (best effort) */
    /* TODO: Write fault info to backup SRAM for post-mortem */

    /* System reset */
    NVIC_SystemReset();
}

/**
 * @brief DMA1 Stream 0 -- ADS1274 SPI RX complete
 */
void DMA1_Stream0_IRQHandler(void)
{
    /* TODO: Handle ADC DMA transfer complete, invoke buffer swap */
}

/**
 * @brief Ethernet IRQ handler
 */
void ETH_IRQHandler(void)
{
    /* TODO: Handle Ethernet MAC interrupt */
}

/* ============================================================================
 * HAL Peripheral Initialization
 * ============================================================================ */

static bool init_hal_peripherals(void)
{
    /* SPI3: ADS1274 ADC (16 MHz, mode 1, 8-bit for byte-level DMA) */
    hal_spi_config_t spi3_cfg = {
        .instance    = SPI3,
        .mode        = SPI_MODE_1,
        .data_size   = SPI_DATA_8BIT,
        .prescaler   = 8,   /* 120 MHz / 8 = 15 MHz (close to 16 MHz target) */
        .msb_first   = true,
        .software_cs = true,
    };
    if (!hal_spi_init(&g_spi3_handle, &spi3_cfg)) return false;

    /* SPI4: PGA280 amplifiers (5 MHz, mode 0, 8-bit) */
    hal_spi_config_t spi4_cfg = {
        .instance    = SPI4,
        .mode        = SPI_MODE_0,
        .data_size   = SPI_DATA_8BIT,
        .prescaler   = 32,  /* 120 MHz / 32 = 3.75 MHz (under 5 MHz target) */
        .msb_first   = true,
        .software_cs = true,
    };
    if (!hal_spi_init(&g_spi4_handle, &spi4_cfg)) return false;

    /* Internal ADC for power monitoring */
    if (!hal_adc_init()) return false;

    return true;
}

/* ============================================================================
 * Subsystem Initialization
 * ============================================================================ */

static bool init_subsystems(void)
{
    /* --- Power Management (must be first, checks all rails) --- */
    esocore_power_config_t pwr_cfg = {
        .brownout_warning_mv   = ESOCORE_RAIL_24V_BROWNOUT_MV,
        .brownout_shutdown_mv  = ESOCORE_RAIL_24V_SHUTDOWN_MV,
        .overvoltage_mv        = ESOCORE_RAIL_24V_MAX_MV + 500,
        .temperature_limit_c   = 70,
        .brownout_holdoff_ms   = 50,
        .enable_supercap_backup = true,
        .enable_analog_sequencing = true,
    };
    if (!esocore_power_init(&pwr_cfg)) return false;

    /* Power-up sequencing: wait for all rails to stabilize */
    if (!esocore_power_sequence_up()) return false;

    /* --- Event System (needed for logging) --- */
    esocore_event_init(NULL);

    /* --- Safety I/O --- */
    safety_system_config_t safety_cfg = {
        .watchdog_timeout_ms        = SAFETY_WATCHDOG_TIMEOUT,
        .test_pulse_interval_ms     = SAFETY_TEST_PULSE_INTERVAL,
        .fault_reset_time_ms        = SAFETY_FAULT_RESET_TIME,
        .enable_cross_monitoring    = true,
        .enable_safe_state_enforcement = true,
        .safety_category            = 3,
        .system_description         = "EsoCore Edge v1.5.0 Safety I/O",
    };
    if (!safety_io_init(&safety_cfg)) return false;

    /* --- Dual Ethernet --- */
#if ESOCORE_FEATURE_DUAL_ETHERNET
    ethm_config_t eth_cfg = {
        .port_config = {
            [ETHM_PORT_A] = {
                .role     = ETHM_ROLE_MACHINE,
                .phy_addr = ETH1_PHY_ADDR,
                .mac_addr = {0x00, 0x80, 0xE1, 0x00, 0x00, 0x01},
                .ip_config = {
                    .use_dhcp = false,
                    .ip_addr  = {192, 168, 10, 100},
                    .netmask  = {255, 255, 255, 0},
                    .gateway  = {192, 168, 10, 1},
                },
            },
            [ETHM_PORT_B] = {
                .role     = ETHM_ROLE_IT,
                .phy_addr = ETH2_PHY_ADDR,
                .mac_addr = {0x00, 0x80, 0xE1, 0x00, 0x00, 0x02},
                .ip_config = {
                    .use_dhcp = true,
                },
            },
        },
    };
    ethm_init(&eth_cfg);
#endif

    /* --- Analog Input Subsystem --- */
#if ESOCORE_FEATURE_ANALOG_INPUTS
    analog_config_t analog_cfg = {
        .sample_rate_hz    = ESOCORE_ADC_SAMPLE_RATE_HZ,
        .samples_per_block = 256,
        .channel_config    = {
            [0] = { .mode = ANALOG_MODE_IEPE, .gain = ANALOG_GAIN_1X,
                     .trigger_mode = ANALOG_TRIGGER_CONTINUOUS },
            [1] = { .mode = ANALOG_MODE_IEPE, .gain = ANALOG_GAIN_1X,
                     .trigger_mode = ANALOG_TRIGGER_CONTINUOUS },
            [2] = { .mode = ANALOG_MODE_DC,   .gain = ANALOG_GAIN_1X,
                     .trigger_mode = ANALOG_TRIGGER_CONTINUOUS },
            [3] = { .mode = ANALOG_MODE_DC,   .gain = ANALOG_GAIN_1X,
                     .trigger_mode = ANALOG_TRIGGER_CONTINUOUS },
        },
    };
    analog_input_init(&analog_cfg);
#endif

    /* --- RS-485 Sensor Bus --- */
#if ESOCORE_FEATURE_SENSOR_BUS
    sensor_bus_config_t sbus_cfg = {
        .baudrate            = ESOCORE_SBUS_BAUDRATE,
        .enable_termination  = true,
        .enable_12v_power    = true,
        .discovery_interval_ms = 5000,
        .max_sensors         = 32,
    };
    sensor_bus_init(&sbus_cfg);
#endif

    /* --- Interbus --- */
#if ESOCORE_FEATURE_INTERBUS
    interbus_config_t ibus_cfg = {
        .baudrate           = ESOCORE_INTERBUS_BAUDRATE,
        .node_address       = 1,
        .enable_termination = true,
        .cycle_time_ms      = 5,
    };
    interbus_init(&ibus_cfg);
#endif

    /* --- WiFi (ESP32-S3 via USART1) --- */
#if ESOCORE_FEATURE_WIFI_ESP32
    wifi_config_t wifi_cfg = {
        .mode         = WIFI_MODE_STATION,
        .dhcp_enabled = true,
        .max_retries  = 5,
    };
    wifi_manager_init(&wifi_cfg);
#endif

    /* --- Storage (microSD via SDMMC1) --- */
#if ESOCORE_FEATURE_MICROSD
    storage_system_init();
#endif

    /* --- TinyML Engine --- */
#if ESOCORE_FEATURE_TINYML
    tinyml_engine_init();
#endif

    /* --- OLED Display --- */
#if ESOCORE_FEATURE_OLED_DISPLAY
    oled_display_init();
    oled_display_status_screen("EsoCore Edge", FW_VERSION_STRING, "Booting...", 0);
#endif

    /* --- Protocol (RS-485 sensor communication) --- */
    esocore_protocol_init(DEVICE_ADDRESS, DEVICE_TYPE);

    return true;
}

/* ============================================================================
 * Runtime Loop
 * ============================================================================ */

static void runtime_loop(void)
{
    system_running = true;

    /* Start continuous acquisitions */
#if ESOCORE_FEATURE_ANALOG_INPUTS
    analog_input_start_acquisition();
#endif
#if ESOCORE_FEATURE_SENSOR_BUS
    sensor_bus_start();
#endif
#if ESOCORE_FEATURE_INTERBUS
    interbus_start();
#endif

    /* Main superloop */
    while (system_running) {
        uint32_t now = system_clock_get_tick();

        /* --- Power monitoring (100 Hz) --- */
        if (now - last_power_poll >= POWER_POLL_INTERVAL_MS) {
            esocore_power_poll();
            last_power_poll = now;

            /* Check for brownout -> initiate graceful shutdown */
            if (esocore_power_get_state() == ESOCORE_POWER_STATE_CRITICAL) {
                if (esocore_supercap_is_shutdown_safe()) {
                    graceful_shutdown();
                    return;
                }
            }
        }

        /* --- Safety I/O (100 Hz, <10 ms response requirement) --- */
        if (now - last_safety_poll >= SAFETY_POLL_INTERVAL_MS) {
            /* Safety polling is handled by safety_io internal test pulses.
             * Here we check for faults and react. */
            safety_system_status_t safety_status;
            if (safety_io_get_system_status(&safety_status)) {
                if (safety_status.fault_code != SAFETY_FAULT_NONE) {
                    esocore_event_log(ESOCORE_EVENT_SAFETY_FAULT,
                                     ESOCORE_EVENT_SEVERITY_CRITICAL,
                                     (uint8_t *)"Safety fault detected", 0);
                    /* Safety module auto-enters safe state */
                }
            }
            last_safety_poll = now;
        }

        /* --- Ethernet polling (1 kHz) --- */
#if ESOCORE_FEATURE_DUAL_ETHERNET
        if (now - last_ethernet_poll >= ETHERNET_POLL_INTERVAL_MS) {
            ethm_poll();
            last_ethernet_poll = now;
        }
#endif

        /* --- Sensor bus polling (100 Hz) --- */
#if ESOCORE_FEATURE_SENSOR_BUS
        if (now - last_sensor_bus_poll >= SENSOR_BUS_POLL_INTERVAL_MS) {
            sensor_bus_poll();
            last_sensor_bus_poll = now;
        }
#endif

        /* --- Interbus polling (200 Hz) --- */
#if ESOCORE_FEATURE_INTERBUS
        if (now - last_interbus_poll >= INTERBUS_POLL_INTERVAL_MS) {
            interbus_poll();
            last_interbus_poll = now;
        }
#endif

        /* --- Display update (0.5 Hz) --- */
#if ESOCORE_FEATURE_OLED_DISPLAY
        if (now - last_display_update >= DISPLAY_UPDATE_INTERVAL_MS) {
            esocore_power_status_t pwr_status;
            esocore_power_get_status(&pwr_status);

            oled_display_status_screen(
                "EsoCore Edge",
                FW_VERSION_STRING,
                (ethm_get_link_status(ETHM_PORT_A) == ETHM_LINK_UP) ? "ETH:OK" : "ETH:--",
                pwr_status.uptime_seconds);
            last_display_update = now;
        }
#endif

        /* --- Cloud heartbeat (via Port B / WiFi) --- */
        if (now - last_heartbeat >= HEARTBEAT_INTERVAL_MS) {
            /* TODO: Send heartbeat via IT network (Ethernet Port B or WiFi) */
            last_heartbeat = now;
        }

        /* --- Telemetry upload --- */
        if (now - last_telemetry >= TELEMETRY_INTERVAL_MS) {
            /* TODO: Collect and send telemetry data */
            last_telemetry = now;
        }

        /* --- Process incoming protocol messages --- */
        esocore_message_t msg;
        if (esocore_protocol_receive_message(&msg, 0)) {
            esocore_protocol_handle_message(&msg);
        }

        /* --- Flush event buffer --- */
        esocore_event_flush_buffer();

        /* --- Feed watchdog --- */
        if (now - last_watchdog_feed >= WATCHDOG_FEED_INTERVAL_MS) {
            feed_watchdog();
            last_watchdog_feed = now;
        }
    }
}

/* ============================================================================
 * Graceful Shutdown
 * ============================================================================ */

static void graceful_shutdown(void)
{
    system_running = false;

    /* Log shutdown event */
    esocore_event_log(ESOCORE_EVENT_SYSTEM_SHUTDOWN, ESOCORE_EVENT_SEVERITY_INFO,
                     (uint8_t *)"Graceful shutdown initiated", 0);

    /* Stop acquisitions */
#if ESOCORE_FEATURE_ANALOG_INPUTS
    analog_input_stop_acquisition();
#endif
#if ESOCORE_FEATURE_SENSOR_BUS
    sensor_bus_stop();
#endif
#if ESOCORE_FEATURE_INTERBUS
    interbus_stop();
#endif

    /* Enter safety mode (de-energize all outputs) */
    safety_io_enter_safety_mode();

    /* Flush events and data to microSD */
    esocore_event_flush_buffer();
    /* TODO: storage_system_flush() */

    /* Display shutdown message */
#if ESOCORE_FEATURE_OLED_DISPLAY
    oled_display_status_screen("EsoCore Edge", FW_VERSION_STRING, "SHUTDOWN", 0);
#endif

    /* Shut down subsystems in reverse order */
#if ESOCORE_FEATURE_OLED_DISPLAY
    oled_display_deinit();
#endif
    tinyml_engine_deinit();
#if ESOCORE_FEATURE_INTERBUS
    interbus_deinit();
#endif
#if ESOCORE_FEATURE_SENSOR_BUS
    sensor_bus_deinit();
#endif
#if ESOCORE_FEATURE_DUAL_ETHERNET
    ethm_deinit();
#endif
    analog_input_deinit();
    safety_io_deinit();

    /* Power down sequence */
    esocore_power_sequence_down();
    esocore_power_deinit();
}

/* ============================================================================
 * Main Entry Point
 * ============================================================================ */

/**
 * @brief Application entry point (called by Reset_Handler after SystemInit)
 *
 * Initialization sequence for EsoCore Edge v1.5.0.0:
 *   1. System clock configuration (480 MHz via PLL1)
 *   2. SysTick for 1 ms timing
 *   3. GPIO initialization (all pins per v1.5.0.0 mapping)
 *   4. HAL peripheral initialization (SPI, UART, I2C, etc.)
 *   5. Power rail sequencing and verification
 *   6. Subsystem initialization (Ethernet, analog, safety, fieldbus, ...)
 *   7. Watchdog start
 *   8. Enter runtime superloop
 */
int main(void)
{
    /* Step 1: Configure system clocks (25 MHz HSE -> 480 MHz SYSCLK) */
    if (!system_clock_init()) {
        /* Clock failure: system cannot operate. Hang with error LED. */
        /* Note: GPIO clocks may not be running; best effort */
        while (1) { __asm volatile("nop"); }
    }

    /* Update CMSIS SystemCoreClock variable */
    SystemCoreClockUpdate();

    /* Step 2: Start SysTick for 1 ms timing */
    system_clock_init_systick();

    /* Step 3: Initialize all GPIO pins per v1.5.0.0 board mapping */
    hal_gpio_init_all();

    /* Indicate boot in progress */
    hal_gpio_set(LED_STATUS_GREEN);

    /* Step 4: Initialize HAL peripherals (SPI, ADC) */
    if (!init_hal_peripherals()) {
        hal_gpio_set(LED_STATUS_RED);
        while (1) { bsp_delay_ms(1000); }
    }

    /* Step 5+6: Initialize all subsystems */
    if (!init_subsystems()) {
        hal_gpio_set(LED_STATUS_RED);
        esocore_event_log(ESOCORE_EVENT_SYSTEM_STARTUP, ESOCORE_EVENT_SEVERITY_CRITICAL,
                         (uint8_t *)"Subsystem initialization failed", 0);
        while (1) { bsp_delay_ms(1000); }
    }

    /* Step 7: Start independent watchdog (2 second timeout) */
    iwdg_init(2000);

    /* Log successful startup */
    esocore_event_log(ESOCORE_EVENT_SYSTEM_STARTUP, ESOCORE_EVENT_SEVERITY_INFO,
                     (uint8_t *)"EsoCore Edge v1.5.0.0 started", 0);

    /* Turn off boot LED, system is running */
    hal_gpio_reset(LED_STATUS_GREEN);

    /* Step 8: Enter main runtime loop */
    runtime_loop();

    /* If we exit the loop, perform graceful shutdown */
    graceful_shutdown();

    /* Should never reach here; reset */
    NVIC_SystemReset();
    return 0;
}

/* ============================================================================
 * BSP Helper Implementations
 * ============================================================================ */

/**
 * @brief bsp_delay_ms -- blocking delay using SysTick
 */
void bsp_delay_ms(uint32_t ms)
{
    uint32_t start = system_clock_get_tick();
    while ((system_clock_get_tick() - start) < ms) {
        /* Busy wait */
    }
}

/**
 * @brief bsp_get_tick_ms -- system tick in milliseconds
 */
uint32_t bsp_get_tick_ms(void)
{
    return system_clock_get_tick();
}

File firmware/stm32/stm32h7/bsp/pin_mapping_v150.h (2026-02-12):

/**
 * @file pin_mapping_v150.h
 * @brief EsoCore Edge v1.5.0.0 GPIO Pin Assignments
 *
 * Complete pin mapping for the STM32H747IIT6 (LQFP176) on the EsoCore Edge
 * PCB revision v1.5.0.0. All GPIO assignments are defined here as the single
 * source of truth. Drivers and BSP code include this file instead of
 * hard-coding pin numbers.
 *
 * Pin assignment strategy:
 *   - Ethernet 1 (Port A) uses the default ETH RMII alternate-function pins
 *   - Ethernet 2 (Port B) uses remapped ETH2 pins on Port I/H
 *   - SPI3 for ADS1274 ADC (high-speed, DMA-capable)
 *   - SPI4 for PGA280 gain amplifiers
 *   - USART1 for ESP32-S3 communication
 *   - USART2 for RS-485 sensor bus (SN65HVD72D)
 *   - USART3 for Modbus RTU (ADM2582EBRWZ)
 *   - UART4 for PROFIBUS (SN65HVD1176DR)
 *   - UART5 for Interbus (ADM2582EBRWZ)
 *   - I2C1 for OLED display
 *   - SDMMC1 for microSD (4-bit)
 *   - USB OTG FS for USB-C
 *
 * @author EsoCore Development Team
 * @copyright Copyright (c) 2026 Newmatik. All rights reserved.
 * @license Apache License, Version 2.0
 */

#ifndef ESOCORE_PIN_MAPPING_V150_H
#define ESOCORE_PIN_MAPPING_V150_H

#include <stdint.h>

#ifdef __cplusplus
extern "C" {
#endif

/* ============================================================================
 * GPIO Port and Pin Helper Macros
 * ============================================================================ */

/** Encode port letter (A=0 .. K=10) and pin number (0..15) into a uint16_t */
#define PIN_DEF(port, pin)  (((uint16_t)(port) << 8) | (uint16_t)(pin))
#define PIN_PORT(def)       ((uint8_t)((def) >> 8))
#define PIN_NUM(def)        ((uint8_t)((def) & 0xFF))

#define GPIO_PORT_A   0
#define GPIO_PORT_B   1
#define GPIO_PORT_C   2
#define GPIO_PORT_D   3
#define GPIO_PORT_E   4
#define GPIO_PORT_F   5
#define GPIO_PORT_G   6
#define GPIO_PORT_H   7
#define GPIO_PORT_I   8
#define GPIO_PORT_J   9
#define GPIO_PORT_K   10

/* ============================================================================
 * Ethernet Port A (Machine / OT Network) -- KSZ8081RNACA PHY #1
 * RMII interface on default ETH1 pins, MDIO address 0
 * ============================================================================ */

#define ETH1_RMII_REF_CLK       PIN_DEF(GPIO_PORT_A, 1)   /* PA1  AF11 */
#define ETH1_RMII_MDIO          PIN_DEF(GPIO_PORT_A, 2)   /* PA2  AF11 */
#define ETH1_RMII_CRS_DV        PIN_DEF(GPIO_PORT_A, 7)   /* PA7  AF11 */
#define ETH1_RMII_MDC           PIN_DEF(GPIO_PORT_C, 1)   /* PC1  AF11 */
#define ETH1_RMII_RXD0          PIN_DEF(GPIO_PORT_C, 4)   /* PC4  AF11 */
#define ETH1_RMII_RXD1          PIN_DEF(GPIO_PORT_C, 5)   /* PC5  AF11 */
#define ETH1_RMII_TX_EN         PIN_DEF(GPIO_PORT_B, 11)  /* PB11 AF11 */
#define ETH1_RMII_TXD0          PIN_DEF(GPIO_PORT_B, 12)  /* PB12 AF11 */
#define ETH1_RMII_TXD1          PIN_DEF(GPIO_PORT_B, 13)  /* PB13 AF11 */
#define ETH1_PHY_ADDR           0  /* MDIO address for PHY #1 */
#define ETH1_RMII_AF            11 /* Alternate function number */

/* PHY reset and interrupt (directly wired to MCU GPIOs) */
#define ETH1_PHY_RESET          PIN_DEF(GPIO_PORT_G, 0)   /* PG0 -- active low */
#define ETH1_PHY_INT            PIN_DEF(GPIO_PORT_G, 1)   /* PG1 -- active low, EXTI */

/* ============================================================================
 * Ethernet Port B (IT Network) -- KSZ8081RNACA PHY #2
 * RMII interface on remapped pins (PI/PH range), MDIO address 1
 * Note: STM32H747 supports a second Ethernet MAC via alternate pin mapping.
 * MDIO bus is shared with ETH1 (PA2/PC1).
 * ============================================================================ */

#define ETH2_RMII_REF_CLK       PIN_DEF(GPIO_PORT_I, 0)   /* PI0  AF11 */
#define ETH2_RMII_CRS_DV        PIN_DEF(GPIO_PORT_I, 1)   /* PI1  AF11 */
#define ETH2_RMII_RXD0          PIN_DEF(GPIO_PORT_I, 2)   /* PI2  AF11 */
#define ETH2_RMII_RXD1          PIN_DEF(GPIO_PORT_I, 3)   /* PI3  AF11 */
#define ETH2_RMII_TX_EN         PIN_DEF(GPIO_PORT_H, 2)   /* PH2  AF11 */
#define ETH2_RMII_TXD0          PIN_DEF(GPIO_PORT_H, 3)   /* PH3  AF11 */
#define ETH2_RMII_TXD1          PIN_DEF(GPIO_PORT_H, 6)   /* PH6  AF11 */
/* MDIO shared with ETH1: PA2 (MDIO), PC1 (MDC) */
#define ETH2_PHY_ADDR           1  /* MDIO address for PHY #2 */
#define ETH2_RMII_AF            11

/* PHY reset and interrupt */
#define ETH2_PHY_RESET          PIN_DEF(GPIO_PORT_G, 2)   /* PG2 -- active low */
#define ETH2_PHY_INT            PIN_DEF(GPIO_PORT_G, 3)   /* PG3 -- active low, EXTI */

/* ============================================================================
 * ADS1274 24-bit ADC -- SPI3
 * 4-channel simultaneous sampling, SPI + control pins
 * ============================================================================ */
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

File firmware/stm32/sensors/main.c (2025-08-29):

/**
 * @file main.c
 * @brief EsoCore Sensor Module Main Application
 *
 * This file contains the main application for EsoCore sensor modules, integrating
 * sensor data acquisition, RS-485 communication, and power management.
 *
 * @author EsoCore Development Team
 * @copyright Copyright © 2025 Newmatik. All rights reserved.
 * @license Apache License, Version 2.0
 */

#include <stdint.h>
#include <stdbool.h>
#include <stdio.h>
#include <string.h>

/* Core System Includes */
#include "protocol.h"
#include "../../common/sensors/sensor_interface.h"
#include "power_management.h"
#include "event_system.h"

/* Demo Sensors */
#include "vibration_sensor.h"
#include "acoustic_sensor.h"
#include "current_sensor.h"
#include "air_quality_sensor.h"

/* ============================================================================
 * Configuration Macros
 * ============================================================================ */

/* Device Configuration */
#define SENSOR_DEVICE_ADDRESS       0x02    /* Default sensor address */
#define SENSOR_DEVICE_TYPE          ESOCORE_DEVICE_TYPE_VIBRATION /* Default type */

/* Communication Configuration */
#define HEARTBEAT_INTERVAL_MS       15000   /* 15 seconds */
#define DATA_TRANSMIT_INTERVAL_MS   2000    /* 2 seconds */
#define CONFIG_CHECK_INTERVAL_MS    60000   /* 1 minute */

/* Power Configuration */
#define LOW_POWER_THRESHOLD_MA      50      /* Enter low power below this current */

/* ============================================================================
 * Global Variables
 * ============================================================================ */

/* System state */
static bool system_initialized = false;
static bool system_running = false;
static uint32_t system_uptime_ms = 0;

/* Device configuration */
static uint8_t device_address = SENSOR_DEVICE_ADDRESS;
static esocore_device_type_t device_type = SENSOR_DEVICE_TYPE;

/* Timing variables */
static uint32_t last_heartbeat_time = 0;
static uint32_t last_data_transmit_time = 0;
static uint32_t last_config_check_time = 0;

/* System status */
static struct {
    bool master_connected;
    bool sensors_active;
    uint8_t active_sensors;
    uint32_t total_measurements;
    uint8_t system_health;
    bool low_power_mode;
} system_status;

/* Sensor data buffers */
static vibration_sensor_data_t vibration_data;
static acoustic_sensor_data_t acoustic_data;
static current_sensor_data_t current_data;
static air_quality_sensor_data_t air_quality_data;

/* ============================================================================
 * System Initialization Functions
 * ============================================================================ */

/**
 * @brief Initialize demo sensors based on device type
 */
static bool initialize_demo_sensors(void) {
    bool success = false;

    switch (device_type) {
        case ESOCORE_DEVICE_TYPE_VIBRATION:
            {
                vibration_sensor_config_t config = {
                    .base_config = {
                        .sensor_type = ESOCORE_SENSOR_VIBRATION,
                        .sensor_id = 1,
                        .sampling_rate_hz = 1000,
                        .sample_count = 1024,
                        .measurement_interval_ms = 1000
                    },
                    .accelerometer_type = 0,
                    .sensitivity_mg_per_lsb = 2.0f,
                    .measurement_range = 2,
                    .enable_high_pass_filter = true,
                    .high_pass_cutoff_hz = 10.0f,
                    .enable_low_pass_filter = true,
                    .low_pass_cutoff_hz = 500.0f,
                    .enable_temperature_compensation = true,
                    .fft_window_type = 0
                };

                if (vibration_sensor_init(&config) && vibration_sensor_start_acquisition()) {
                    success = true;
                    system_status.active_sensors = 1;
                }
            }
            break;

        case ESOCORE_DEVICE_TYPE_CURRENT:
            {
                current_sensor_config_t config = {
                    .base_config = {
                        .sensor_type = ESOCORE_SENSOR_CURRENT,
                        .sensor_id = 1,
                        .sampling_rate_hz = 5000,
                        .sample_count = 512,
                        .measurement_interval_ms = 1000
                    },
                    .sensor_type = 1,
                    .sensitivity_mv_a = 40.0f,
                    .nominal_current_a = 5.0f,
                    .enable_temperature_compensation = true,
                    .enable_harmonic_analysis = true,
                    .harmonic_order_max = 15,
                    .enable_power_analysis = true,
                    .fft_window_type = 0,
                    .filter_cutoff_hz = 1000.0f
                };

                if (current_sensor_init(&config) && current_sensor_start_acquisition()) {
                    success = true;
                    system_status.active_sensors = 1;
                }
            }
            break;

        default:
            // For other sensor types, just initialize sensor interface
            if (esocore_sensor_init()) {
                success = true;
            }
            break;
    }

    if (success) {
        system_status.sensors_active = true;
    }

    return success;
}

/* ============================================================================
 * Communication and Data Functions
 * ============================================================================ */
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

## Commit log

2025-08-29 feat: initial commit
    Complete EsoCore platform with:
    - Hardware designs and BOMs for edge device and sensors
    - STM32 firmware for edge processing and sensor modules
    - Django REST API backend with device management
    - Nuxt.js web portal for monitoring and control
    - Static documentation website with GitHub Pages deployment
    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
    [acoustic-sensor.kicad_pcb, acoustic-sensor.kicad_sch, air-quality-sensor.kicad_pcb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]
2025-09-01 fix: update to STM32H747IIT6
    [bom-main.csv, bom.csv]
2025-09-01 feat(hardware): pluggable terminal connectors
    [bom.csv]
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2025-09-03 chore(hardware): switch from KiCad to Altium Designer
    [acoustic-sensor.kicad_pcb, acoustic-sensor.kicad_sch, air-quality-sensor.kicad_pcb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]
2025-09-03 fix(website): create folder structure for sensors pages
2025-09-03 fix(website): better sensor page content
2025-09-04 feat(website): better bom pages
    [bom-acoustic-sensor.csv, bom-air-quality-sensor.csv, bom-cables.csv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]
2025-09-04 fix(website): switch from FreeCAD to Fusion 360
2025-09-05 fix(edge hardware): update bom
    [bom-acoustic-sensor.csv, bom-air-quality-sensor.csv, bom-current-sensor.csv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]
2025-10-14 feat: 4 tact buttons, clarification on ethernet
    [bom-main.csv, bom.csv]
2025-10-14 fix: pcb dimensions with explanation
    [bom.csv]
2025-10-14 chore: markdownlint
    [bom-main.csv]
2026-02-12 feat: documentation update and v1.4.0 of edge
    [24V_input.SchDoc, Buck_converter.SchDoc, ESP32.SchDoc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]
2026-02-13 chore(deps): bump socket.io-client from 4.8.1 to 4.8.3 in /portal
    Bumps [socket.io-client](https://github.com/socketio/socket.io) from 4.8.1 to 4.8.3.
    - [Release notes](https://github.com/socketio/socket.io/releases)
    - [Changelog](https://github.com/socketio/socket.io/blob/main/CHANGELOG.md)
    - [Commits](https://github.com/socketio/socket.io/compare/socket.io-client@4.8.1...socket.io-client@4.8.3)
    ---
    updated-dependencies:
    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
2026-02-13 fix(ci): fix Portal CI formatting and Server CI poetry.lock
    - Run prettier --write to fix code style issues in 16 portal files
    that were causing Portal CI format:check to fail on main.
    - Remove poetry.lock from server/.gitignore and track it in git so
    Server CI can use it for dependency caching.
2026-02-13 fix(ci): resolve Portal typecheck errors and Server ruff lint failures (#20)
    Portal:
    - Fix TypeScript type errors in useApi.ts (method type widening,
    body type mismatch with $fetch)
    - Add BadgeColor type to .vue files where string was not assignable
    to the component's color prop union type
    Server:
    - Disable PT009/PT027/RUF012 ruff rules that conflict with Django's
    idiomatic unittest-style test patterns and model class defaults
    - Auto-fix import sorting (I001) and remove unused imports (F401)
    - Fix remaining lint issues: B017 (specific exceptions), B904 (raise
    from), DJ012 (method ordering), RUF003 (unicode), SIM105/SIM108
    (simplifications), F841 (unused vars), T201 (per-file ignor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
2026-07-12 chore(deps): consolidate 14 Dependabot updates and cover website with CI (#39)
    * ci: cover the website with CI and unbreak dependency PRs
    Three defects, all independent of any dependency bump:
    1. website/** had no pull_request CI at all. portal-ci and server-ci are path-filtered
    to their own directories and pages.yml (which publishes the website) only runs on
    push to main — so website changes reached main completely unchecked, including two
    untested majors sitting in open PRs (vue-router 4->5, vue-tsc 2->3). Added
    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
2026-07-12 hotfix(portal): clear four open transitive advisories (#46)
    The four Dependabot alerts still open against portal are all transitive, and the
    resolver was keeping a vulnerable copy alongside a patched one (ws 8.18.3 next to
    8.21.0, esbuild 0.27.7 next to 0.28.1), so a plain dependency bump never cleared them.
    Pinned the floors with pnpm overrides:
    - ws 8.18.3 -> 8.21.0 GHSA high (< 8.21.0) and medium (< 8.20.1)
    - socket.io-parser 4.2.5 -> 4.2.6 GHSA high (>= 4.0.0, < 4.2.6)
    - esbuild 0.27.7 -> 0.28.1 GHSA low (>= 0.27.3, < 0.28.1)
    Each now resolves to a single, patched version. Portal CI gate passes locally: lint
    (0 errors), format:check, typecheck, bui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
2026-07-12 ci: make the CI checks safe to mark as required (#47)
    Two things had to change before these can be enforced as required status checks.
    Path filters on pull_request are gone. A workflow skipped by a path filter never reports
    its check run at all — it does not report "skipped", it reports nothing — so a required
    check would sit pending forever on any PR that does not touch that directory. (Job-level
    `if:` skips are fine; those do report.) Push keeps its filters, since required checks only
    apply to PRs.
    Job names are now distinct. portal-ci and website-ci both emitted a check called
    "build-and-lint", which is ambiguous as a required-check context: one passing job would
    satisfy the require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
2026-07-13 chore(deps): bump the pip group in /server with 11 updates (#50)
    - dependency-name: django
    dependency-version: 5.2.16
    dependency-type: direct:production
    update-type: version-update:semver-patch
    dependency-group: pip
    - dependency-name: djangorestframework
    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
2026-10-05 chore(deps): bump the pip group across 1 directory with 9 updates (#75)
    Bumps the pip group with 9 updates in the /server directory:
    | Package | From | To |
    | --- | --- | --- |
    | [django](https://github.com/django/django) | `5.2.16` | `5.2.17` |
    | [djangorestframework](https://github.com/encode/django-rest-framework) | `3.17.1` | `3.18.1` |
    | [python-dotenv](https://github.com/theskumar/python-dotenv) | `1.2.2` | `1.2.3` |
    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
2026-10-05 fix: resolve regenerated code quality findings (pass 2) (#77)
    * fix: resolve regenerated code quality findings (pass 2)
    - website/public/bom.js: build the category filter, table cells and
    category summary with DOM nodes + textContent instead of innerHTML,
    and reject non-2xx CSV responses instead of rendering them as rows.
    - tools/step_linter.py: collapse the whole leading run of duplicate
    ISO-10303-21 lines, leave quoted STEP string literals untouched when
    respacing, and only rewrite the FILE_NAME name instead of replacing
    the header (keeps AP203/AP214/AP242 schema, timestamp and authors).
    - Add node tests for bom.js and unittest coverage for step_linter.
    * fix(tools): ignore FIL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
2026-10-06 chore: move agent instructions from .cursorrules to AGENTS.md (#78)
    The team is retiring Cursor in favour of Claude Code and Codex. Fold the
    .cursorrules conventions (BOM sync, Markdown line length, README style)
    into AGENTS.md, which Codex reads directly, and add a CLAUDE.md that
    imports it for Claude Code. Rename the "Cursor Cloud specific" heading
    to a tool-neutral "Development environment".
2026-10-13 chore(deps): bump the pip group in /server with 7 updates (#84)
    Bumps the pip group in /server with 7 updates:
    | [django](https://github.com/django/django) | `5.2.17` | `5.2.18` |
    | [djangorestframework](https://github.com/encode/django-rest-framework) | `3.18.1` | `3.18.3` |
    | [django-filter](https://github.com/carltongibson/django-filter) | `26.1` | `26.2` |
    | [python-dotenv](https://github.com/theskumar/python-dotenv) | `1.2.3` | `1.2.4` |
    | [ruff](https://github.com/astral-sh/ruff) | `0.16.8` | `0.16.10` |
    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
2026-10-13 fix: read CORS_ALLOWED_ORIGINS from the environment (#87)
    settings.py hard-coded a localhost-only CORS list, so the documented
    CORS_ALLOWED_ORIGINS variable had no effect and a portal on its own
    domain was blocked. Parse it as a comma-separated list like
    ALLOWED_HOSTS, keeping the current local origins as the default.
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2026-10-24 chore(portal): remove unused dependencies (#96)
    Drop axios, jwt-decode, socket.io-client and @vueuse/core, which nothing
    in the portal imports (HTTP goes through $fetch/useApi), and the
    socket.io-parser override that only existed for socket.io-client. The
    lockfile was regenerated with pnpm.
    Claude-Session: https://claude.ai/code/session_01CKbFLmUsEGdDkU48wrM6bp
2026-11-03 chore: drop unused code and deps, speed up server tests, fix CI pnpm cache (#110)
    * chore: drop unused code and deps, speed up server tests, fix CI pnpm cache
    - server: remove unused requests (and its urllib3/idna pins); MD5 hasher under manage.py test only (11.5 s -> 0.2 s)
    - server: login regression tests (inactive user, ambiguous email, wrong password via email)
    - portal: delete root app.config.ts, which Nuxt 4 never loads (srcDir is app/)
    - ci: working pnpm store cache via setup-node, concurrency and job timeouts
    * fix(server): authenticate devices by X-Device-Id and their API key
    APIKeyAuthentication read is_active from rest_framework_api_key's APIKey model, which has no such field,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
2026-11-03 feat(website): move to Cloudflare Workers (headers, cache, hourly catch-up); working docs search, lighter images, privacy notice (#111)
    * fix(website): working docs search, lighter hero and OG image, privacy notice, no 301s on canonical URLs
    - Docs search fetched /api/docs/<slug> for all 59 docs on every /docs visit; those routes do
    not exist on GitHub Pages (59 console 404s, search returned nothing). One prerendered
    /api/docs-search.json now, loaded on the first search.
    - Hero pcb.png (1.9 MB, LCP 11.6 s on mobile) -> 1000/2000 px WebP with srcset and size.
    - og-image.png (4.8 MB, 2848x1504) -> og-image.jpg 1200x630 (64 KB) with dimensions and alt.
    - JSON-LD logo pointed at a missing /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
2026-11-03 fix(website): attach custom domains with the DNS-override endpoint wrangler uses (#113)
    The first deploy of deploy-website.yml (run 41647795858) deployed the
    esocore-website Worker but failed to attach www.esocore.com: the public
    PUT /workers/domains rejects a hostname that still has DNS records
    (error 100117) and ignores override_existing_dns_record. The script now
    uses PUT /workers/scripts/<service>/domains/records, the endpoint
    wrangler deploy uses for custom domains, which replaces the GitHub Pages
    A/CNAME records. A push that changes the script now also redeploys.
2026-11-03 fix(website): serve www.esocore.com through Worker routes, not custom domains (#114)
    Cloudflare refuses a Workers custom domain while the hostname has DNS
    records, also with override_existing_dns_record on the endpoint wrangler
    uses (409, code 100117; deploy run 41649554900, confirmed with the
    Newmatik token). Deleting the GitHub Pages records first would leave the
    site without DNS for a moment. Worker routes on the existing proxied
    records take over at once and the Worker never fetches the origin, so
    the switch has no gap. The attach step and its script go.
2026-11-06 fix(api): keep management reads and writes on the caller's sites (#117)
    The firmware device list uses the same site filter as the device list.
    Creates and updates reject a site, device, or asset the caller cannot read.
2026-11-13 ci: run the portal and website on Node 24 (#123)
    * ci: run the portal and website on Node 24
    The workflows ran on Node 22 while the docs allowed 22.19+ or 24.11+,
    so the newer runtime was never exercised. Add an .nvmrc with 24.18.0
    to portal/ and website/, let the three workflows read it, and state
    Node 24 as the one supported version in the READMEs, AGENTS.md and the
    website docs.
    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
2026-11-13 feat(firmware): complete the Modbus RTU slave function codes and add T1.5/T3.5 frame timing (#126)
    * feat(firmware): complete the Modbus RTU slave function codes and add T1.5/T3.5 frame timing
    The slave answered only function codes 0x01, 0x03, 0x05 and 0x0F. It now
    also serves 0x02 Read Discrete Inputs, 0x04 Read Input Registers, 0x06 Write
    Single Register and 0x10 Write Multiple Registers, and answers errors with
    the exception code the specification assigns (01, 02, 03 or 04) instead of
    always 02.
    New RTU receiver: modbus_rtu_receive_byte() and modbus_rtu_poll() apply the
    inter-character (T1.5) and inter-frame (T3.5) silence rules, with the times
    from modbus_rtu_get_frame_timing().
    Also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
2026-11-13 fix(api): honour page_size, and load complete lists in the portal (#130)
    * fix(api): honour page_size, and load complete lists in the portal
    The API ignored the page_size query parameter (DRF's PageNumberPagination
    needs page_size_query_param), so the portal's "recent" lists returned up to
    100 rows instead of 8, 10 or 20, and the documented parameter did nothing.
    A StandardPagination class now honours it up to 500 rows.
    The portal's device, alert and asset lists read only the first page. They
    now follow the pages up to 2,000 rows and say so when more exist.
    Closes #129
    * fix(api): give every paginated list a total order
    Review finding: no model or view sets an ordering, so the database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
